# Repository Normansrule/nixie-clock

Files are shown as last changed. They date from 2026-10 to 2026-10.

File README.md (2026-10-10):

# Six-Tube Nixie Clock · Rev C

> [!CAUTION]
> **About 170 V of direct current (DC) inside: hazardous and potentially lethal.** Power only from an external, isolated 12 V adapter (no mains inside). Dark tubes, software "off" or a pulled shunt do **not** mean safe: **measure test pad TP4 below 10 V** before touching. Read **[SAFETY.md](docs/SAFETY.md)** first.

**An open-source, handmade-style desk clock with six real IN-14 Nixie tubes in a walnut case with brass trim, fully enclosed behind a smoked window, that you can make yourself.** It comes with 3D-printable parts, laser-cut and woodworking drawings, a bill of materials (BOM), pin-by-pin wiring, KiCad files, firmware, requirements, labels and a staged build guide, plus a website and a desktop app. **The one missing piece is a routed circuit board**: the path to it is in [MANUFACTURING.md](docs/MANUFACTURING.md).

   

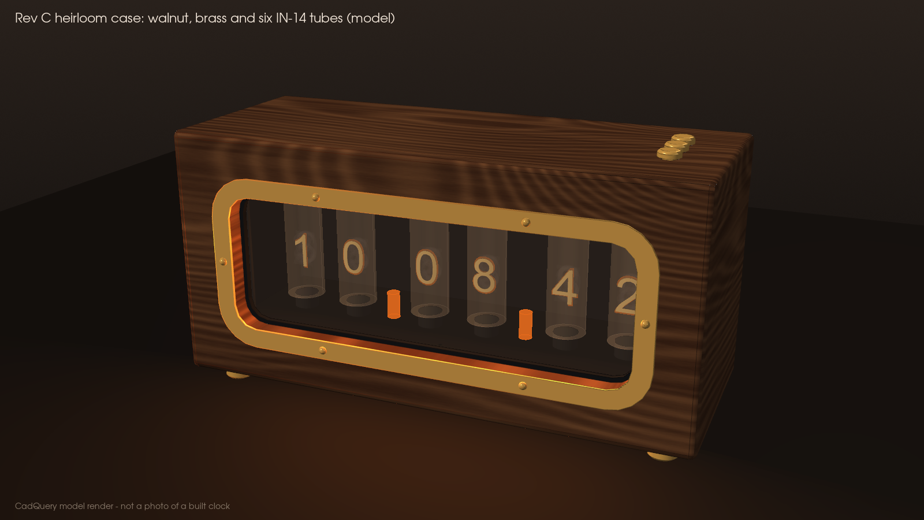
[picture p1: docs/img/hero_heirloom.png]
Walnut and brass heirloom case with six glowing IN-14 tubes, model render


| Front | From the side |
|---|---|
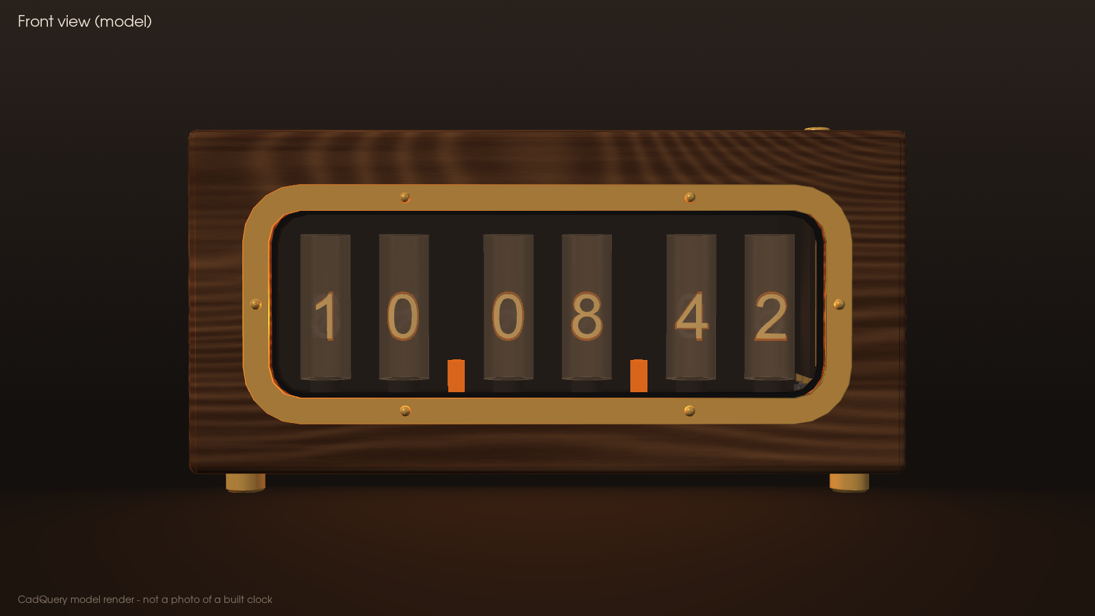
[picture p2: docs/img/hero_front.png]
Front view, model render
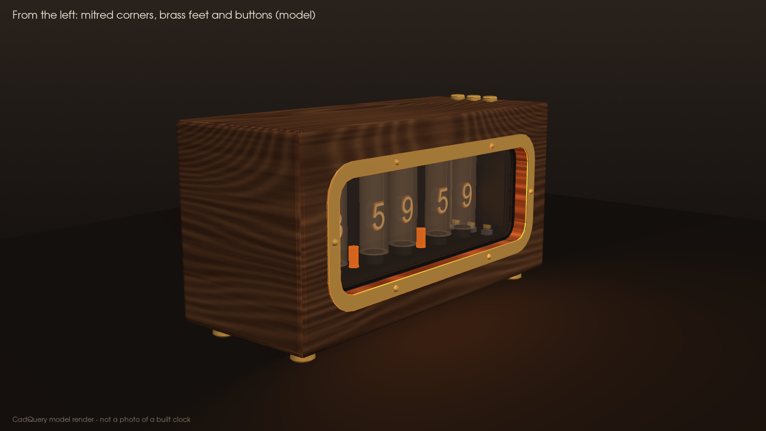
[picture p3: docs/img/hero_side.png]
Left side: mitred corners, brass feet and buttons, model render
|  |  |

> [!IMPORTANT]
> **Rev C is an unvalidated engineering prototype.** Nothing has been powered yet, and the circuit board is not routed, so no Gerber files exist. Recorded file checks pass; every physical check is still open ([VALIDATION.md](docs/VALIDATION.md)).

## At a glance

| | |
|---|---|
| 📏 **Size** | 254 × 100 × 130 mm on its brass feet, about 134 mm to the top of the buttons |
| 🔆 **Display** | 6 × IN-14 tubes (HH MM SS) + 2 × NE-2 neon separators |
| 🔌 **Power** | External isolated 12 V adapter, about 0.25 A with all digits lit |
| 🧠 **Electronics** | Arduino Nano Classic · DS3231 real-time clock (RTC) · 2 × HV5522 tube drivers · NCH8200HV 170 V module |
| 🪵 **Case** | Five mitred 9.5 mm walnut boards, oiled · 1 mm brass bezel with six brass screws · brass feet and button caps · 3 mm smoked cast-acrylic window |
| 🧱 **Inside** | A printed black inner case (fits a Bambu Lab P1S) carries every precise fit and keeps the HV enclosed; on its own it is a complete *printed edition* · **M2 screws only** |
| 💲 **Parts** | About $390 for electronics and printed parts, plus roughly $60–100 for wood and brass (planning estimates, not re-priced) |

## 🏭 Make it

What to make, from which file, and what is ready

Full process, PCB specification and the release gate: **[MANUFACTURING.md](docs/MANUFACTURING.md)**.

## 🧊 See it in 3D

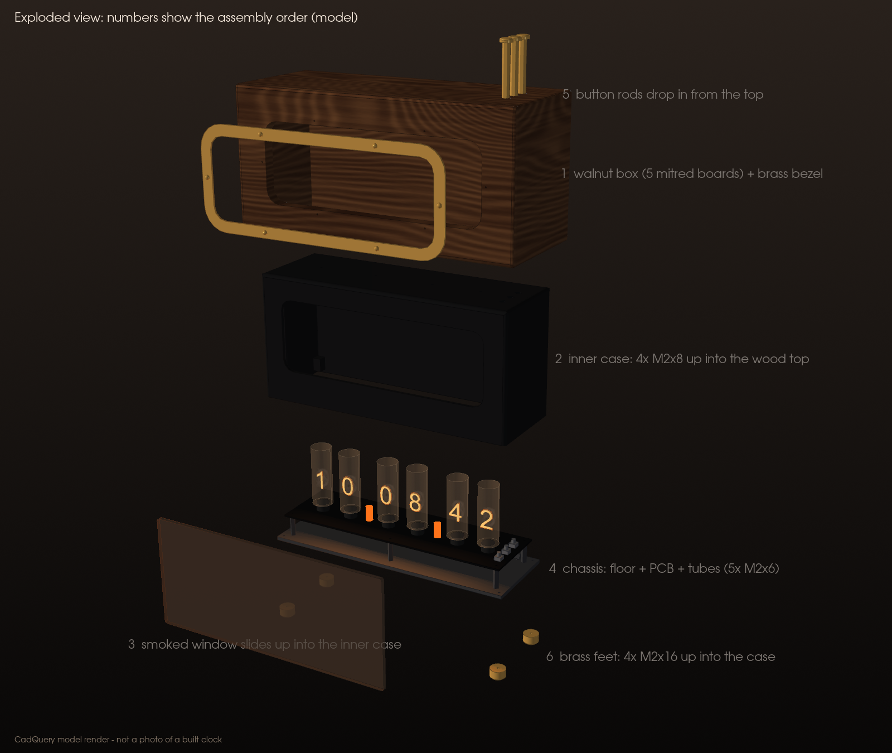
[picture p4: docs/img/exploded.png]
Exploded view


**How it goes together:** glue the five walnut boards into a box and screw the brass bezel on; screw the box onto the printed inner case through its roof; slide the smoked window up into the inner case; screw the PCB with its tubes onto the floor (the *chassis*); lower the case over it and close it with four screws through the brass feet. No glass ever passes through an opening, and nothing high-voltage can be reached once those four screws are in.

GitHub shows `.stl` files in an interactive 3D viewer: click one to rotate it.

| View the whole clock (do not print) | Print these | Cut / make these |
|---|---|---|
| [Finished clock](cad/view/Assembly_RevC_heirloom_VIEW_ONLY.stl) · [Printed edition](cad/view/Inner_case_printed_edition_VIEW_ONLY.stl) · [Chassis, case off](cad/view/Chassis_RevC_case_removed_VIEW_ONLY.stl) | Black PETG: [01 inner case](cad/stl/01_inner_case.stl) · [02 floor](cad/stl/02_floor.stl) · [03 clamp](cad/stl/03_cable_clamp.stl) · [06 fit coupon](cad/stl/06_fit_coupon.stl) · [07 lead coupon](cad/stl/07_unpowered_lead_pattern_coupon.stl) · silk brass: [04 button rod ×3](cad/stl/04_button_rod.stl) · ready plates in [`cad/print/`](cad/print/) | [Wood boards DXF](cad/dxf/Wood_boards_1to1.dxf) (walnut, [WOODWORK.md](docs/WOODWORK.md)) · [Brass bezel DXF](cad/dxf/Brass_bezel_1mm_1to1.dxf) · [Window DXF](cad/dxf/Window_panel_3mm_1to1.dxf) (3 mm smoked cast acrylic) · [brass foot](cad/step/14_brass_foot.step) ×4 |

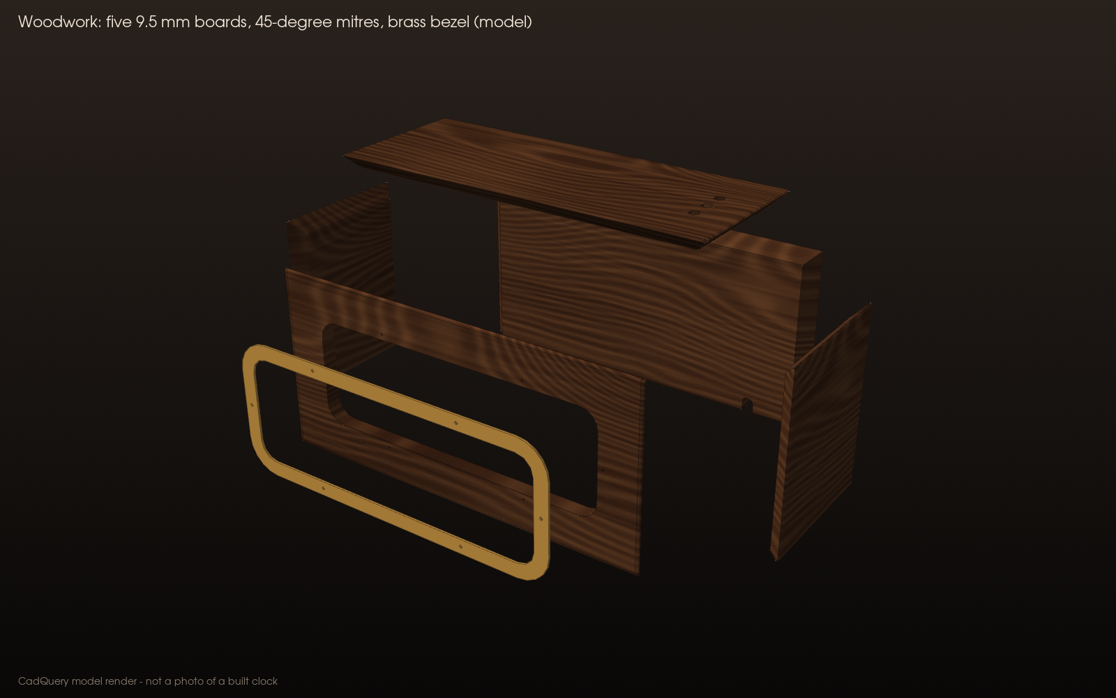
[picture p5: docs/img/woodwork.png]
Woodwork: five mitred walnut boards and the brass bezel


STEP files for computer-aided design (CAD) are in [`cad/step/`](cad/step/); the model of record is [`source/build_cad.py`](source/build_cad.py), driven by [`cad/DIMENSIONS.json`](cad/DIMENSIONS.json). Printing: [PRINTING.md](docs/PRINTING.md) · woodwork and brass: [WOODWORK.md](docs/WOODWORK.md).

Case dimensions

## 🧾 Bill of materials

29 electrical lines (71 parts) plus the case (printed, wood, brass, acrylic) and M2 fasteners. **Lines marked safety-critical must be bought at the stated rating or better.**

| Key part | Qty | Why it matters |
|---|---|---|
| IN-14 Nixie tube | 6 | The display; enclosure is sized for it |
| HV5522PJ-G driver (PLCC-44) | 2 | Switches the tube cathodes (not the PG package) |
| NCH8200HV module | 1 | Makes about 170 V from 12 V |
| Arduino Nano Classic + DS3231SN# | 1 + 1 | Brains and timekeeping |
| 22 kΩ 1 W resistors (Vishay PR01) | 6 | Tube current limit: **safety item** |
| 100 nF ≥250 V capacitor, 110 kΩ bleeders | 1 + 2 | HV rail storage and discharge: **safety items** |

Everything, with specs and allowed substitutions: [`hardware/BOM.csv`](hardware/BOM.csv) · [`hardware/BOM_mechanical.csv`](hardware/BOM_mechanical.csv) · readable [BOM.md](docs/BOM.md).

## 🔌 Circuit and wiring

Wiring overview and driver shift chain

- **Pin by pin:** [WIRING.md](docs/WIRING.md) and [`hardware/NET_MAP.csv`](hardware/NET_MAP.csv) (340 connections; HV5522 pins from the data sheet)
- **Schematic:** [PDF](docs/Nixie_RevC_schematic.pdf) · KiCad project in [`hardware/`](hardware/)
- **PCB:** [mechanical drawing](docs/img/pcb_drawing.svg) · placement-only board (checked by KiCad's own design rules check, no copper yet)
- **Numbers behind the design:** [EQUATIONS.md](docs/EQUATIONS.md) (tube current, resistor power, discharge time, RTC drift)

## 🛠️ Build it

Build stages

Step by step, with parts, measurements and PASS / FIX / STOP at every stage: **[BUILD_GUIDE.md](docs/BUILD_GUIDE.md)**. Record each unit in [`hardware/TEST_RECORD.csv`](hardware/TEST_RECORD.csv) and stick on the [labels](docs/labels.pdf).

## ✅ Requirements

Requirement status

42 requirements, each traced to the part of the design that meets it and to how it is verified: [REQUIREMENTS.md](docs/REQUIREMENTS.md).

## 💻 Website, app and tools

| Website | Desktop app | Tools |
|---|---|---|
| This repository as a website on GitHub Pages; installs as an offline web app | Windows, macOS and Linux from the *Releases* page | Tube and HV calculator, and a USB serial companion for the clock ([APP.md](docs/APP.md)) |

## 🚀 Publish and keep building

- Put this repository on GitHub (website and desktop release included) with one paste: [PUBLISH.md](docs/PUBLISH.md)
- Everyday commands (check, commit, release, apply a new ZIP): [DEVELOP.md](docs/DEVELOP.md)
- Supply chain, signed releases, reporting problems: [SECURITY.md](docs/SECURITY.md) · data sheets: [CREDITS.md](CREDITS.md)

<details>
<summary><b>Repository layout</b></summary>

```
README.md            this page
docs/                SAFETY · BUILD_GUIDE · MANUFACTURING · BOM · WIRING · REQUIREMENTS · EQUATIONS
                     PRINTING · WOODWORK · VALIDATION · APP · PUBLISH · DEVELOP · SECURITY · labels.pdf · schematic PDF
hardware/            KiCad project · NET_MAP.csv · BOM.csv · BOM_mechanical.csv · REQUIREMENTS.csv
                     COMPONENT_PLACEMENT.csv · TEST_RECORD.csv · REVIEW_SIGNOFF.md · native-check reports
firmware/Nixie_RevC/ Nixie_RevC.ino · display_core.h · build/Nixie_RevC.hex
cad/                 DIMENSIONS.json · stl/ · 3mf/ · print/ · step/ · view/ · dxf/ (window, brass bezel, wood boards) · assembly STEP
source/build_cad.py  CadQuery model of record
scripts/             generators, checks, publish/ship/release helpers, gated fab-output script
tests/               equation, design, requirement, CAD and firmware checks
site/ · app/         GitHub Pages website · Electron desktop app
sbom/                toolchain software bill of materials
```
</details>

**Checks:** `scripts/run_all_checks.sh` reruns every recorded check (equations, design tables, requirements, firmware, AVR compile, CAD geometry, KiCad netlist and placement checks). Passing means the files agree with each other, not that a powered clock works.

**License:** MIT ([LICENSE](LICENSE)). Building and powering high-voltage hardware is at your own risk.

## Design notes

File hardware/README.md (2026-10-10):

# Hardware (KiCad, Rev C)

**Status: UNVALIDATED.** Generated files for schematic review and layout. No copper, no routing, no Gerbers.

| File | What it is | How it was made |
|---|---|---|
| `NET_MAP.csv` | Every connection: net, ref, pin, pin name, domain (LV / LOGIC12 / HV), status, note | `scripts/make_design_tables.py` |
| `COMPONENT_PLACEMENT.csv` | Planning positions in **enclosure** coordinates (mm), side, rotation | same |
| `Nixie_RevC.kicad_pro` | Project, with an `HV` net class and patterns that put `HV170`, `ANODE*`, `T?_K?`, `LAMP?_A`, `SEP?_K`, `HV_BLEED_MID`, `HV_SENSE_MID` in it | `scripts/make_kicad.py` |
| `Nixie_RevC.kicad_sch` + `digit_1.kicad_sch` + `digit_2.kicad_sch` | Root sheet (power, logic, level shifters, HV supply, RTC) and one child sheet per driver bank | generated from `NET_MAP.csv`; every connection is a **global label** at a pin |
| `Nixie_RevC.kicad_sym` | Local symbol library: generic box symbols, one per part type | generated |
| `Nixie_RevC.pretty/` | **PLACEHOLDER** footprints: courtyard and fab outline only, **no pads** (plus a real M2 NPTH mounting hole) | generated |
| `sym-lib-table`, `fp-lib-table` | Project-local library tables | generated |
| `Nixie_RevC.kicad_dru` | Starting HV clearance rules for the future routed board | written by hand in the generator; **check against IPC-2221B** |
| `Nixie_RevC_placement.kicad_pcb` | 218 × 64 mm 4-layer outline, five M2 holes, placeholder courtyards (top: tubes, lamps, switches; bottom: everything else, plus keep-outs under the tube and lamp leads) | pcbnew Python API |
| `reports/` | Native netlist export, netlist-vs-net-map comparison, native DRC report of the placement board | `scripts/make_kicad.py` |

**Coordinates.** The placement board uses KiCad's Y-down axis with the clock's front edge at the bottom of the screen. Enclosure point (x, y) sits at board (20 + x, 20 + 80 − y) mm.

## What the native checks do and do not show

- `kicad-cli sch export netlist` reads the generated schematic, and every one of the 106 shared nets matches `NET_MAP.csv`. So the schematic **files** faithfully encode the net map. This is not ERC, and it cannot tell you whether the net map is *right*.
- pcbnew DRC on the placement board reports 0 violations: the outline, holes and courtyards do not collide. There is no copper, so it says nothing about clearances or connectivity.

## To turn this into a board

1. Open `Nixie_RevC.kicad_pro` in KiCad 7 or newer. Redraw the root sheet into readable blocks (the generated one is a label-connected parts list).
2. Replace placeholders with real footprints: PLCC-44 for the HV5522PJ-G, SOIC-16W for the DS3231SN, the IN-14 direct-solder pattern **measured from your tubes**, the NCH8200HV **measured from your module**.
3. Run native ERC. Fix everything or document every waiver.
4. Route 4 layers with `Nixie_RevC.kicad_dru`. Keep HV on one side of the board, away from the Nano and the logic. Keep the top side to tubes, lamps, switches, the HV_ARM header and the TP1–TP4 test pads along the rear edge (reached with the case lifted off).
5. Run native DRC. Have the HV layout reviewed by someone experienced.
6. Only then plot Gerbers and drill files. Record all of it in `docs/VALIDATION.md`.

Regenerate everything here with `python3 scripts/make_design_tables.py && python3 scripts/make_kicad.py` (needs KiCad 7.x with `kicad-cli` and the `pcbnew` Python module).

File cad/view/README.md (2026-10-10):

# View-only assemblies

Open these `.stl` files on GitHub to rotate the whole clock in 3D. **Do not print them**: they contain the glass, PCB, switch, window, wood and brass parts in assembly coordinates. The heirloom view is the finished clock; the printed-edition view is the inner case on its own; the chassis view shows the inside with the case lifted off. Printable parts are in `../stl/` and `../print/`.

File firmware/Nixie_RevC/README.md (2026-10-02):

# Firmware: Nixie_RevC

For the **Arduino Nano Classic (A000005, ATmega328P, 16 MHz)** only. Not for the Nano Every, Nano ESP32 or other boards. Uses only `Wire` and `EEPROM`, which ship with the Arduino AVR core. Serial at 115200 baud.

**Status: UNVALIDATED.** Compiled and linked for the ATmega328P with avr-gcc outside the Arduino IDE; never run on a Rev C board. Read [docs/SAFETY.md](../../docs/SAFETY.md) before connecting USB to a board that has ever had HV on it.

## Files

- `Nixie_RevC.ino`: pins, safe start-up, HV state machine, RTC, buttons, serial commands.
- `display_core.h`: pure logic (bit mapping, one-digit-per-tube check, time formatting, sense conversions). Tested on a PC by `tests/test_display_core.cpp`.

## Features

HH:MM:SS; 12/24-hour; time setting by buttons or serial; real-time clock (RTC) with coin-cell backup; startup blanking; display sleep window; hourly digit exercise against cathode poisoning; VIN and HV diagnostics; default-off on invalid time, reset and faults.

## Safe defaults

- The first lines of `setup()` drive HV_EN and RUN low and shift an all-off frame.
- HV starts only when the time is valid (or while you set it with the buttons, which times out after 60 s), VIN reads 10.8–13.2 V (13.2 V is the HV5522's VDD maximum), and the rail reaches 150 V within 1.5 s. Above 190 V at any time, below 150 V while running, or an unsafe frame latches `HV FAULT` **in EEPROM**: it survives every reset, including the one the serial monitor causes, until you send `CLEARFAULT`.
- Every frame passes `frameIsSafe()` (at most one cathode per tube, never HVOUT32) or an all-off frame is sent instead.
- A 2 s watchdog resets the Nano if the loop hangs; in reset the hardware blanks the tubes and turns HV off.

## Buttons

| Action | Result |
|---|---|
| Hold SET 2 s (or press SET while the time is invalid) | Set hours: H up, M down; SET → set minutes; SET → save (seconds = 00). 60 s without a press abandons setting. HV runs while setting so you can see the digits |
| Hold H 2 s | Toggle 12 / 24-hour (saved) |
| Hold M 2 s | Toggle display sleep (saved) |
| Any press during sleep | Wake for 30 s |

## Serial commands (115200, newline)

`STATUS` · `T hh:mm:ss` · `12` · `24` · `SLEEP hh:mm hh:mm` · `SLEEP OFF` · `HVOFF` (HV off and blank until `RUN`) · `RUN` · `EXERCISE` · `CLEARFAULT` (only after measuring TP4 and fixing the cause)

## Build-time constants to confirm on real hardware

- `nixie::kOutReversed` in `display_core.h` (false = HVOUT*n* is frame bit *n* − 1, matching the data sheet's shift direction). Confirm in Stage 4 by lighting one digit at a time.
- HV window `HV_MIN_DV` / `HV_MAX_DV` and VIN window in `Nixie_RevC.ino`.
- The anode resistor start value (22 kΩ) is not a verified brightness: measure every digit before changing it.

## Build it

Arduino IDE: *Tools → Board → Arduino AVR Boards → Arduino Nano*, *Processor → ATmega328P* (or *Old Bootloader*), then Upload. Record the IDE and core versions in `docs/VALIDATION.md` and pin them in `docs/SECURITY.md` once Stage 2 passes.

Without the IDE (compile check only): `scripts/avr_compile_check.sh /path/to/ArduinoCore-avr`.

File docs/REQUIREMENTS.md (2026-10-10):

# Requirements (Rev C)

42 requirements, each traced to the design element that satisfies it and to how it is verified. Generated by `scripts/make_requirements.py` (also as [`hardware/REQUIREMENTS.csv`](../hardware/REQUIREMENTS.csv)); `tests/check_requirements.py` checks that every requirement has evidence that exists.

**Methods:** I = Inspection, A = Analysis, D = Demonstration, T = Test. **Status:** *recorded* means a script checks the design files, which is **not** a physical result; *open* needs real parts or a measurement at the listed build stage ([BUILD_GUIDE.md](BUILD_GUIDE.md)).

25 of 42 requirements have a recorded design check; 17 still need a physical result

## Safety

| ID | Requirement | Satisfied by | Method | Evidence | Stage | Status |
|---|---|---|---|---|---|---|
| SAF-01 | The clock takes power only from an external, isolated, regulated 12 V adapter. No mains wiring inside the enclosure. | J1 pigtail, adapter line in BOM_mechanical.csv | I | `BOM_mechanical.csv` | 1, 6 | recorded |
| SAF-02 | No high-voltage (HV) copper, lead or module is reachable through any enclosure opening in normal use. | Fully enclosed case: glazed window, rods filling the button holes (<=0.3 mm gap), cable filling the rear hole, screwed floor | I | `tests/check_cad.py (model only)` | 6 | **open** |
| SAF-03 | After power is removed the HV rail falls below 10 V within 60 s, confirmed by measurement every time before access. | RH1+RH2 bleeder (220 kOhm), sense divider, SAFETY.md rule 3 | A, T | `tests/check_equations.py (discharge)` | 3 | **open** |
| SAF-04 | Removing the HV_ARM shunt physically opens the converter's 12 V input. | JP1 in series with QP2 and PS1 input | I, T | `tests/check_design.py` | 2 | recorded |
| SAF-05 | The HV converter stays off whenever the Nano is in reset or unprogrammed. | RGP gate pull-up on QP2, RPD5 base pull-down on QE1 | I, T | `tests/check_design.py` | 2 | recorded |
| SAF-06 | All tube outputs are blanked at start-up and whenever the Nano is in reset. | RD1 pull-down on BL, POL tied HIGH, two-stage RUN shifter | I, T | `tests/check_design.py` | 2 | recorded |
| SAF-07 | No Nano output connects directly to an HV5522 input. | QL1-QL5 level shifters | I | `tests/check_design.py` | - | recorded |
| SAF-08 | At most one cathode per tube is ever latched on, and unused driver outputs are never set. | frameIsSafe() in display_core.h; unsafe frame latches a fault | A, T | `tests/test_display_core.cpp` | 4 | recorded |
| SAF-09 | Each tube anode is current-limited by a 22 kOhm 1 W resistor and each lamp by 220 kOhm 1 W. | RA1-RA6, RL1, RL2 (PR01) | I, A | `tests/check_design.py, tests/check_equations.py` | 4 | recorded |
| SAF-10 | HV is sensed; outside 150-190 V the firmware turns HV off and latches a fault that survives resets until a deliberate CLEARFAULT. | RS1-RS3 to A0; hvService(), EEPROM fault latch | A, T | `scripts/avr_compile_check.sh` | 2, 3 | **open** |
| SAF-11 | The 12 V input is fused and protected against reverse polarity. | F1 PTC, QP1 P-MOSFET | I, T | `tests/check_design.py` | 1 | recorded |
| SAF-12 | Every exposed neon lamp lead is sleeved with insulation rated at least 300 V (600 V preferred). | Sleeving line in BOM_mechanical.csv | I | `BOM_mechanical.csv` | 4 | **open** |
| SAF-13 | HV-side parts meet minimum ratings: CHV >=250 V; bleeder and sense resistors >=200 V; anode and lamp resistors 1 W. | BOM.csv safety_critical lines | I | `tests/check_requirements.py (BOM specs)` | 1 | recorded |
| SAF-14 | A hung firmware loop resets the Nano within 2 s. | wdt_enable(WDTO_2S) | A | `scripts/avr_compile_check.sh` | 2 | recorded |

## Honesty

| ID | Requirement | Satisfied by | Method | Evidence | Stage | Status |
|---|---|---|---|---|---|---|
| HON-01 | No Gerber or drill files are produced until a routed board passes native ERC and DRC and an experienced HV review is signed off. | scripts/make_fab_outputs.sh gate, hardware/REVIEW_SIGNOFF.md | D | `scripts/make_fab_outputs.sh (refuses today)` | - | recorded |
| HON-02 | Validation records keep recorded file checks separate from physical checks, and claim only what was done. | docs/VALIDATION.md | I | `docs/VALIDATION.md` | 7 | recorded |

## Function

| ID | Requirement | Satisfied by | Method | Evidence | Stage | Status |
|---|---|---|---|---|---|---|
| FUN-01 | Six upright IN-14 tubes show HH MM SS, with an NE-2 separator between each pair. | NET_MAP.csv driver map; timeToDigits() | T | `tests/test_display_core.cpp` | 4 | **open** |
| FUN-02 | 12- or 24-hour display is selectable and remembered across power cycles. | cfg.twelveHour in EEPROM | D | `tests/test_display_core.cpp` | 2, 4 | **open** |
| FUN-03 | Time can be set with the SET, H and M buttons and over USB serial. | handleButtons(), T command | D | `scripts/avr_compile_check.sh` | 2 | **open** |
| FUN-04 | The DS3231 keeps time on a CR2032 primary cell while unpowered (about +/-2 ppm, 0-40 C). | U3, J2, VBAT | A, T | `tests/check_equations.py (drift)` | 2 | **open** |
| FUN-05 | An optional sleep window blanks the display; any button wakes it for 30 s. | inWindow(), wantDisplay() | D | `tests/test_display_core.cpp` | 2 | **open** |
| FUN-06 | Once an hour every cathode of every tube is lit briefly (anti-poisoning). | exerciseDigits() | A, D | `tests/test_display_core.cpp` | 4 | recorded |
| FUN-07 | The display stays off while the time is invalid (except while the user is setting it, 60 s timeout). | wantDisplay(), SET_TIMEOUT_MS | D | `scripts/avr_compile_check.sh` | 2 | **open** |
| FUN-08 | STATUS over serial reports time, VIN, HV, state, faults and button states. | printStatus() | D | `scripts/avr_compile_check.sh` | 2 | **open** |

## Electrical

| ID | Requirement | Satisfied by | Method | Evidence | Stage | Status |
|---|---|---|---|---|---|---|
| ELE-01 | With all digits lit the 12 V input current stays near 0.25 A (stop above 0.35 A); adapter rated >=1 A. | EQUATIONS.md section 5 | A, T | `tests/check_equations.py` | 4 | **open** |
| ELE-02 | HV load with all six tubes and both lamps lit stays within the converter rating (model: about 35 % of 30 mA). | PS1 NCH8200HV | A, T | `tests/check_equations.py` | 4 | **open** |
| ELE-03 | HV5522 logic supply stays within 10.8-13.2 V; firmware refuses HV outside that VIN window. | VIN sense RV1/RV2, VIN_MIN_DV/VIN_MAX_DV | A, T | `tests/check_equations.py` | 2 | **open** |

## Mechanical

| ID | Requirement | Satisfied by | Method | Evidence | Stage | Status |
|---|---|---|---|---|---|---|
| MEC-01 | Heirloom case: printed inner case 234 x 80 x 112 mm clad in a mitred hardwood box 254 x 100 x 121.5 mm (129.5 mm on its feet), outer edges rounded R3. | cad/DIMENSIONS.json, source/build_cad.py | I | `tests/check_cad.py` | 6 | recorded |
| MEC-09 | Premium finish: hardwood (walnut by default) with an oil finish, a 1 mm brass bezel with six brass screws around the window, brass feet and brass button caps. | wood_box(), brass_bezel(), brass_foot(), BOM_mechanical.csv wood and brass lines | I, D | `tests/check_cad.py` | 6 | recorded |
| MEC-10 | Wood never carries a functional fit and never touches the electronics: every precise feature is in the printed inner case, and the wood is held only by four screws into its top board. | wood_fit_gap, roof_screws, inner case | I, A | `tests/check_cad.py` | 6 | recorded |
| MEC-02 | Only M2 fasteners: 4x M2x16 (feet and floor to inner case), 4x M2x8 (inner case to wood top), 7x M2x6 (PCB, cable clamp), 6x M2x6 brass (bezel). | DIMENSIONS.json fasteners, BOM_mechanical.csv | I, A | `tests/check_design.py` | 0, 6 | recorded |
| MEC-03 | The tubes are fully enclosed: no glass passes through any opening; the case is lowered over the finished chassis. | case_shell(), floor standoffs, light baffle | I, D | `tests/check_cad.py` | 6 | recorded |
| MEC-04 | All six numerals are seen through one front window glazed with a 3 mm smoked cast-acrylic panel, framed by the brass bezel and held by the floor and three silicone dots so it stays put when the case is lifted. | window_panel(), slot rails, Window DXF | I | `tests/check_cad.py` | 6 | recorded |
| MEC-05 | Every printed part fits a 256 x 256 x 256 mm build volume (Bambu Lab P1S); only the inner-case roof needs supports. The wood and brass parts are not printed. | cad/BUILD_REPORT.txt bounding boxes | A, D | `tests/check_requirements.py (bed fit)` | 0, 6 | recorded |
| MEC-08 | With the case lifted off, TP1, TP4 and the HV_ARM shunt are reachable from the top of the chassis without reaching under the board. | JP1, TP1-TP4 on the PCB top side (COMPONENT_PLACEMENT.csv) | I | `tests/check_design.py` | 3 | recorded |
| MEC-07 | SET, H and M are pressed from the top of the case through brass-coloured rods that rest on the switches by their own weight and are hidden from the window by a baffle. | button_rod(), guides in case_shell() | A, D | `tests/check_cad.py` | 0, 6 | **open** |

## Electrical

| ID | Requirement | Satisfied by | Method | Evidence | Stage | Status |
|---|---|---|---|---|---|---|
| ELE-04 | The sealed, wood-clad case stays cool enough: modelled average internal rise about 3-5 K at about 2.7 W (wood insulation included); regulator checked at Stage 5. | No vents (keeps HV enclosed) | A, T | `tests/check_equations.py (enclosure rise)` | 5 | **open** |

## Mechanical

| ID | Requirement | Satisfied by | Method | Evidence | Stage | Status |
|---|---|---|---|---|---|---|
| MEC-06 | PCB 218 x 64 x 1.6 mm, 4 layers, five M2 holes at the specified coordinates. | Nixie_RevC_placement.kicad_pcb | I | `scripts/make_kicad.py (native placement DRC)` | - | recorded |

## Cost

| ID | Requirement | Satisfied by | Method | Evidence | Stage | Status |
|---|---|---|---|---|---|---|
| CST-01 | Built as cheaply as is safe: generic passives where allowed, no downgrades of safety items (planning total about $390 plus roughly $60-100 for wood and brass, not re-priced). | BOM.csv substitution column | I | `BOM.csv` | order | **open** |

## Supply chain

| ID | Requirement | Satisfied by | Method | Evidence | Stage | Status |
|---|---|---|---|---|---|---|
| SEC-01 | CI actions pinned by commit hash, least-privilege permissions, SBOM, SHA-256 checksums, Dependabot and CodeQL. | .github/, sbom/, SHA256SUMS | I | `.github/workflows/checks.yml` | - | recorded |

## Documentation

| ID | Requirement | Satisfied by | Method | Evidence | Stage | Status |
|---|---|---|---|---|---|---|
| DOC-01 | Every stage of the build guide lists parts, steps, measurements and PASS / FIX / STOP, with a safety gate before HV. | docs/BUILD_GUIDE.md | I | `docs/BUILD_GUIDE.md` | - | recorded |

## Distribution

| ID | Requirement | Satisfied by | Method | Evidence | Stage | Status |
|---|---|---|---|---|---|---|
| APP-01 | The project is published as a GitHub repository, a GitHub Pages website (installable offline) and a desktop app. | site/, app/, workflows | D | `app launched headless (docs/APP.md)` | - | recorded |

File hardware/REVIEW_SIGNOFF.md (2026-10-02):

# Fabrication review sign-off (Rev C)

`scripts/make_fab_outputs.sh` refuses to make Gerber, drill or placement files until **every** field below is filled in
and the last line says `Approved for fabrication: yes`. Fill it in only after the work is actually done.

| Item | Value |
|---|---|
| Routed board file | `hardware/Nixie_RevC.kicad_pcb` |
| Git commit reviewed | |
| Native ERC (electrical rules check): KiCad version, date, result | |
| Native DRC (design rules check) with `Nixie_RevC.kicad_dru`: KiCad version, date, result | |
| HV clearances checked against IPC-2221B and the fab's capability by | |
| Real footprints checked against parts in hand (IN-14 lead circle, NCH8200HV outline, PLCC-44) by | |
| Experienced HV reviewer (name) | |
| Review date | |
| Notes / waivers | |

Approved for fabrication: no

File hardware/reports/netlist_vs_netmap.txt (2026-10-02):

native netlist: 147 nets from kicad-cli 7.0.11
NET_MAP.csv:    106 multi-use nets (NC nets excluded)
mismatched nets: 0
extra native nets: []
NETLIST vs NET_MAP: MATCH

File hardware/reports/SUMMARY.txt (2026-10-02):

Native KiCad checks run by scripts/make_kicad.py
These are NOT ERC, and NOT DRC of a routed board. See docs/VALIDATION.md.

native netlist: 147 nets from kicad-cli 7.0.11
NET_MAP.csv:    106 multi-use nets (NC nets excluded)
mismatched nets: 0
extra native nets: []
NETLIST vs NET_MAP: MATCH

placement board native DRC (pcbnew 7.0.11): violations=0, unconnected=0, footprint errors=0

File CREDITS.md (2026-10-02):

# Credits and data sheets

Every value taken from a data sheet is marked in [`hardware/NET_MAP.csv`](hardware/NET_MAP.csv) (status `DATASHEET`) or listed as an untested assumption in [`docs/VALIDATION.md`](docs/VALIDATION.md). Links were found or opened on 2026-09-30, except the onsemi, Microchip ATmega328P and Arduino pages, which are the manufacturers' usual product pages and were not re-checked. Manufacturers move files: search the part number on the manufacturer's site if a link breaks.

| Part | Document | Used for | Status |
|---|---|---|---|
| IN-14 Nixie tube | [Tube-Tester IN-14 page](https://www.tube-tester.com/sites/nixie/data/in-14/in-14.htm); [IN-14 data (PDF)](https://download.elektronicastynus.be/57/in-14_datasheet.pdf) | 145 V typical maintaining voltage, 2.5 mA typical current, 19 mm × 55 mm bulb, 13 leads | Lead-circle diameter **not verified** (placeholder) |
| HV5522 (HV5522PJ-G) | [Microchip product page](https://www.microchip.com/en-us/product/hv5522); [data sheet DS20005699](https://ww1.microchip.com/downloads/en/DeviceDoc/20005699A.pdf); [Supertex-era data sheet](https://www.mouser.com/datasheet/2/268/supertex_hv5522-1181179.pdf) | PLCC-44 pinout, function table (POL/BL), shift direction, falling-edge clock, VDD 10.8–13.2 V, VIH ≥ VDD − 2 V, 220 V outputs | Read from the Supertex-era sheet; **recheck against DS20005699** |
| DS3231SN# | [Analog Devices DS3231 product page](https://www.analog.com/en/products/ds3231.html); [data sheet (PDF)](https://www.analog.com/media/en/technical-documentation/data-sheets/ds3231.pdf) | Pinout, ±2 ppm (0–40 °C), OSF and EOSC bits, grounding pins 5–12 | Pin 5–12 grounding **verify** |
| NCH8200HV | [Omnixie product page](https://omnixie.io/nch8200hv.html); [NCH8200HV data sheet v2.1 (PDF)](https://nixieclock.org/wp-content/uploads/2023/02/NCH8200HV-Datasheet-EN-v2.1.0.3.pdf) | 2.5–15 V in, ~170 V fixed out, 30 mA peak, 86–89.65 % efficiency, pin order, no reverse-polarity protection | Outline and output capacitance **not documented** |
| ATmega328P / Arduino Nano | [Microchip ATmega328P](https://www.microchip.com/en-us/product/atmega328p); [Arduino Nano A000005](https://docs.arduino.cc/hardware/nano/) | ADC, watchdog, Nano header pinout | |
| DMP3098L-7 | [Diodes Inc. DMP3098L data sheet DS31447](https://datasheet.octopart.com/DMP3098L-7-Diodes-Inc.-datasheet-12534397.pdf) | −30 V P-MOSFET, SOT-23 | V_GS limit **verify** against adapter overshoot |
| 1812L075/33DR | [Littelfuse 1812L PolySwitch data sheet](https://www.littelfuse.com/assetdocs/resettable-ptcs-1812l-datasheet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) | 0.75 A hold, 33 V PTC | |
| MMBT3904 / MMBT3906 | [onsemi MMBT3904](https://www.onsemi.com/products/discrete-power-modules/general-purpose-and-low-vcesat-transistors/mmbt3904); [onsemi MMBT3906](https://www.onsemi.com/products/discrete-power-modules/general-purpose-and-low-vcesat-transistors/mmbt3906) | Level shifters | |
| Omron B3F-1062-G | [Omron B3F series](https://components.omron.com/us-en/products/switches/B3F) | 6 × 6 mm body, 7 mm height | Body height **verify** (drove the pocket change) |
| Vishay PR01 | [Vishay PR01/PR02/PR03](https://www.vishay.com/en/product/28729/); [data sheet (PDF)](https://www.vishay.com/docs/28729/pr010203.pdf) | 1 W axial anode and lamp resistors | |
| NE-2 neon lamp | Generic; supplier data | ~60 V maintaining voltage assumed | **verify** |

## Standards and references

- OWASP Top 10:2025, A03 Software Supply Chain Failures: [A03:2025](https://owasp.org/Top10/2025/A03_2025-Software_Supply_Chain_Failures/).
- IPC-2221B Table 6-1 (conductor spacing): the source to check the HV clearances in `hardware/Nixie_RevC.kicad_dru` against. Not reproduced here.

## Tools

CadQuery, OpenCASCADE, ezdxf, VTK, KiCad, avr-gcc and ArduinoCore-avr. Versions are in [`sbom/toolchain.spdx.json`](sbom/toolchain.spdx.json).

## Author

Aleksander Norman. Rev C documentation, generators and checks prepared with Claude (Anthropic).

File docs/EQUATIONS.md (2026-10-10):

# Equations

Each section goes intuition → equation → symbols and units → worked example → picture and test. Every number on this page is recomputed by [`tests/check_equations.py`](../tests/check_equations.py) (39 checks). They are **model numbers**, not measurements: Stage 4 of the [build guide](BUILD_GUIDE.md) replaces them with readings from your board.

Inputs used throughout:

| Symbol | Value | Source |
|---|---|---|
| V_HV | 170 V | NCH8200HV v2.1 data sheet: fixed nominal output |
| V_tube | 145 V typical, 135–155 V assumed spread | Tube-Tester IN-14 page (typical maintaining voltage) |
| I_typ | 2.5 mA per digit | Tube-Tester IN-14 page (typical cathode current) |
| R_anode | 22 kΩ, 1 W | Rev C start value (RA1–RA6) |
| R_lamp | 220 kΩ, 1 W | RL1, RL2 |
| V_NE2 | 60 V assumed | NE-2 maintaining voltage; **verify** |

## 1. Tube anode current

**Intuition.** A glowing Nixie tube holds its own voltage roughly constant (the *maintaining voltage*). Whatever is left of the supply is dropped across the anode resistor, and that sets the current.

**Equation.** I_anode ≈ (V_HV − V_tube) / R_anode

**Symbols.** I_anode in amperes (A); V_HV and V_tube in volts (V); R_anode in ohms (Ω).

**Worked example.** (170 V − 145 V) / 22 000 Ω = **1.14 mA**. Across the assumed spread: 1.59 mA at 135 V, 0.68 mA at 155 V.

**What it means.** 1.14 mA is about **45 % of the 2.5 mA typical** IN-14 current. Expect the start value to run the tubes gently; a digit that glows only partly is a sign of too little current. The 22 kΩ value is a *starting point, not a verified brightness*. Measure the current on every digit (Stage 4) before you change anything. For reference, 2.5 mA at 145 V would need about 10 kΩ, and a lower resistor raises the fault power in section 2.

Anode current against tube voltage

**Test.** `anode current @ V_tube=...` and `22 k start value vs IN-14 typical` in `tests/check_equations.py`.

## 2. Resistor power: why the anode resistors are 1 W

**Intuition.** In normal running the resistor only sees the leftover 25 V or so, so it barely warms. In a fault (a tube or cathode path shorted) it can see the whole rail.

**Equation.** P = I² × R in normal running; P = V_HV² / R if the full rail appears across it.

**Symbols.** P in watts (W); I in A; R in Ω; V in V.

**Worked example.**

| Case | Calculation | Result | Share of 1 W rating |
|---|---|---|---|
| Normal, worst tube (135 V) | (1.59 mA)² × 22 kΩ | 55.7 mW | 5.6 % |
| Fault: full rail across RA | 170² / 22 000 | **1.31 W** | **131 %** |
| Lamp resistor, normal | (0.5 mA)² × 220 kΩ | 55 mW | 5.5 % |
| Lamp resistor, fault | 170² / 220 000 | 131 mW | 13 % |

**What it means.** Normal dissipation is tiny. The 1 W rating is there for voltage stress and fault margin, and it is still **not enough** for a sustained hard short, because the NCH8200HV data sheet describes no current limit (up to 30 mA peak output). This is recorded as an open item in [VALIDATION.md](VALIDATION.md#open-items), not hidden. Never reduce the rating.

## 3. Bleeder discharge

**Intuition.** When the converter stops, its output capacitors are still charged. The bleeder resistors drain that charge. The tubes go dark long before the rail is safe, because a tube stops glowing at about 140 V.

**Equation.** V(t) = V_HV × e^(−t/τ), with τ = R × C, so the time to fall to a voltage V is t = τ × ln(V_HV / V).

**Symbols.** τ (tau), the time constant, in seconds (s); R in Ω (the bleeder in parallel with the sense divider); C in farads (F).

**Worked example.** R = 220 kΩ ∥ 2.022 MΩ = 198.4 kΩ.

| Capacitance on the rail | τ | Time to 10 V |
|---|---|---|
| CHV only (100 nF) | 19.8 ms | 56 ms |
| CHV + an **assumed** 1 µF inside the converter | 218 ms | 0.62 s |
| Same, but **the bleeder path open** (RH1 and RH2 are in series, so one open resistor is enough) | 2.2 s | 6.3 s |

**What it means.** On paper the rail empties in under a second. But the converter's internal capacitance is not in its data sheet, and a single open resistor makes it ten times slower. That is why [SAFETY.md](SAFETY.md) asks you to wait 60 seconds **and measure below 10 V** every time.

Discharge curves

**Test.** The `tau ...` and `time to 10 V ...` checks. The firmware also warns if its own sense reading is above 10 V three seconds after HV off; that is a hint, not a proof.

## 4. HV and VIN sensing

**Equation.** V_A0 = V_HV × R_S3 / (R_S1 + R_S2 + R_S3); V_A1 = V_IN × R_V2 / (R_V1 + R_V2)

**Worked example.** 170 V × 22 k / 2.022 M = **1.85 V**, about 378 counts on the Nano's 10-bit analog-to-digital converter (ADC) with a 5 V reference, or 0.45 V of HV per count. 12 V × 10 k / 57 k = 2.1 V on A1. Full scale is 459 V for HV and 28.5 V for VIN. If RS3 ever opens, about 82 µA flows into the A0 protection diodes through 2 MΩ, which the pin tolerates.

**What it means.** The firmware window is 150–190 V. The reference is the Nano's 5 V rail, which can be a few percent off, so compare the firmware's `HV sense` with your meter at Stage 3 and note the difference in VALIDATION.md.

## 5. 12 V input current

**Equation.** I_in ≈ P_HV / (η × 12 V) + I_logic, with P_HV = V_HV × (6 × I_anode + 2 × I_lamp + I_bleed + I_sense)

**Worked example.** Worst-case tubes: P_HV ≈ 1.94 W; at η (efficiency) = 86 % and about 50 mA of logic load, **I_in ≈ 0.24 A**. The HV load (10.6 mA) is about 35 % of the converter's 30 mA peak rating.

**Test.** `12 V input current ...` and `NCH8200HV headroom ...`. A reading well above 0.35 A is a stop condition.

## 6. Real-time clock drift

**Intuition.** The DS3231 is a temperature-compensated crystal clock, so it drifts far less than an ordinary watch crystal, but not zero.

**Equation.** drift per day = accuracy (ppm) × 10⁻⁶ × 86 400 s

**Worked example.** At the data sheet's ±2 parts per million (ppm) from 0 to 40 °C: ±0.17 s per day, ±63 s per year at worst. Real parts are usually better. The DS3231 also has an aging register for trimming, which Rev C firmware leaves at zero.

**Test.** `DS3231 worst drift ...`. To measure your clock, set it against a reference, then compare after a week with `STATUS` over the serial port.

## 7. Sealed-case temperature

**Intuition.** The case has no vents (so the HV stays enclosed). All the power the clock uses ends up as heat inside and has to leave through the case surface. The walnut box looks good but is an insulator, so it is part of the path the heat must cross.

**Equation.** ΔT ≈ P / (U × A), with U = 1 / (1/h + t_wood / k_wood)

**Symbols.** ΔT, the average rise of the inside air over the room, in kelvin (K); P, heat released inside, in W; A, the outer surface area, in m²; h, the combined natural-convection and radiation coefficient of the outer surface, in W/(m²·K); t_wood, the board thickness, in m; k_wood, the wood's thermal conductivity across the grain, in W/(m·K); U, the overall coefficient, in W/(m²·K).

**Worked example.** P ≈ 1.94 W / 0.86 (converter) + 7 V × 50 mA (the Nano's regulator) + 0.1 W (logic) ≈ **2.7 W**. A ≈ 2 × (0.254 × 0.100 + 0.254 × 0.1215 + 0.100 × 0.1215) ≈ 0.137 m². Walnut: t_wood / k_wood ≈ 0.0095 / 0.15 ≈ 0.063 m²·K/W (k assumed). With h = 5 (pessimistic), U ≈ 3.8 and ΔT ≈ **5.2 K**; with h = 10 (typical), U ≈ 6.1 and ΔT ≈ 3.2 K. The wood resistance is applied to every face, which is pessimistic for the PETG floor and the acrylic window; the printed inner wall and the inside air film are ignored.

**What it means.** On average the inside barely warms, even with the wood on. Hot spots are another matter: the Nano's linear regulator and the HV module run hotter than the air around them. Stage 5 of the build guide measures them after two hours closed, with the wood box fitted.

**Test.** `heat dissipated inside the case`, `wood wall resistance`, `average internal rise ...`.

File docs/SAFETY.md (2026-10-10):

# High-voltage safety

> **About 170 volts of direct current (V DC) lives on this board whenever the high-voltage converter has run. Treat it as hazardous and potentially lethal.** Rev C is an unvalidated engineering prototype. Nobody has yet powered one and recorded the results.

This page is the rulebook. The [build guide](BUILD_GUIDE.md) points back here at every high-voltage (HV) step, and none of its gates may be skipped.

## The five rules

1. **No mains inside the clock.** Power comes only from an external, *isolated*, regulated 12 V adapter with a centre-positive 5.5 × 2.1 mm plug. The clock never touches line voltage. Do not substitute a non-isolated supply, a bench supply without current limit during bring-up, or a battery pack of unknown voltage.
2. **Off is not safe until you have measured it.** Firmware "HV off", dark tubes, unplugging the adapter and pulling the HV_ARM shunt all stop the converter. **None of them proves the HV rail (net `HV170`, test pad TP4) is discharged.** Only a meter reading does.
3. **Measure before every touch.** Before your hands, tools or probes go near the board: unplug 12 V, wait at least 60 seconds, then measure TP4 to TP1 (ground). Continue only below **10 V**. If the reading is not falling as the bleeder predicts, **STOP**: a bleeder resistor may be open, and the capacitors can hold charge for a long time.
4. **Enclosed in use; guarded during bring-up.** In normal use the clock only runs fully closed: case screwed to the floor through the brass feet, window in place, rods in their holes, so no HV copper, lead or the converter can be reached. The printed inner case is the HV enclosure; the walnut box is only cladding, so the clock never runs in the wood box without the inner case, and all woodwork and brass work (conductive swarf) is finished and vacuumed before electronics go in. The only exception is guarded bench bring-up (Stages 3 and 4 of the build guide), where the board must be measured: then the chassis (floor + PCB) sits on an insulated surface behind a clear barrier, on a current-limited supply, with meter leads and USB connected **before** power is applied, hands off while energised, never unattended.
5. **Experienced review first.** Before the HV_ARM shunt goes in for the first time, someone experienced with high-voltage DC circuits reviews the populated board, the enclosure and your measuring setup.

## What protects you in the design, and what does not

| Protection | What it does | What it does **not** do |
|---|---|---|
| Isolated external 12 V adapter | Keeps mains out of the enclosure | Does nothing about the 170 V made inside |
| F1 resettable fuse (Positive Temperature Coefficient, PTC) | Limits a 12 V side fault | Does not limit HV current |
| QP1 reverse-polarity P-channel MOSFET (Metal-Oxide-Semiconductor Field-Effect Transistor) | Blocks a reversed plug | The converter itself has **no** reverse-polarity protection (its data sheet says so) |
| JP1 HV_ARM shunt | Physically opens the converter's 12 V input | Does not discharge anything already charged |
| QP2 high-side switch, gate pulled off | Converter stays off while the Nano is in reset or unprogrammed | A failed transistor can leave it on |
| Base pull-downs + BL pull-down + POL tied high | Tubes blanked while the Nano is in reset | Depends on the HV5522 behaving as its data sheet says: **verify** |
| 22 kΩ 1 W anode resistors, 220 kΩ 1 W lamp resistors | Set and limit current into each tube and lamp | The NCH8200HV module has no documented current limit, so a hard short can overload a 1 W resistor (see [VALIDATION.md](VALIDATION.md#open-items)) |
| RH1 + RH2 bleeder (220 kΩ total) | Discharges the HV rail in well under a second on paper | Fails silently if a resistor opens: that is why rule 3 exists |
| HV sense divider to A0 | Firmware shuts down outside 150–190 V | A reading is not a guarantee: the sensing chain can fail |
| Firmware fault latch (EEPROM) | Any HV fault keeps HV off across resets until `CLEARFAULT` | A deliberate clear by the user re-enables it |
| Firmware watchdog | A hung Nano resets, which blanks the tubes and turns HV off | Not a safety device on its own |
| Sleeving ≥300 V (600 V preferred) on neon leads | Insulates exposed lamp leads | Only if every lead is covered |

These parts are **safety items and must never be "value-engineered" away**: the 1 W anode and lamp resistors, the ≥250 V HV capacitor (CHV), the bleeders, the sleeving, the isolated adapter and the fused, reverse-protected 12 V path.

## Measuring the HV rail safely

- Use a meter rated at least Category II 600 V with intact leads. Clip the black lead to TP1 **before** power is ever applied, and use a single-hand technique: one hand behind your back or in your pocket.
- Probe TP4 only with the probe tip; never bridge TP4 to anything with a tool.
- Expected with the converter running: about 170 V (the NCH8200HV output is fixed, not adjustable, per its v2.1 data sheet).
- Expected after unplugging, with good bleeders: below 10 V within about 1 second on paper (see [EQUATIONS.md](EQUATIONS.md#3-bleeder-discharge)). Rule 3 still asks you to wait 60 seconds and measure, because the converter's internal capacitance is unknown.
- If you ever need to force a discharge, use a purpose-made discharge tool: a resistor of at least 10 kΩ, rated 5 W or more, on insulated leads. Never short the rail with a screwdriver.

## USB, the shunt and the serial monitor

The Nano sits under the PCB, inside the closed case; its USB port is reached from the side of the chassis once the case is lifted off. Two situations:

- **Guarded bring-up (Stages 3–4):** USB may stay connected with the shunt fitted, but connect it before applying 12 V and never plug or unplug it while 12 V is on. Opening the serial monitor resets the Nano; the firmware keeps any HV fault latched in EEPROM across that reset, so HV cannot quietly restart after a fault. A USB isolator between the computer and the clock is a sensible extra.
- **Flashing firmware:** follow the steps below every time.

### Flashing

1. Unplug the 12 V adapter. Remove the HV_ARM shunt only after the discharge check below.
2. Wait 60 seconds. Lay the clock on its back, remove the 4 screws through the brass feet, stand it up and lift the case (wood and inner case together) straight off. **Measure TP4 to TP1 below 10 V** (both on the top side at the rear edge), then remove the HV_ARM shunt next to them.
3. Connect USB only after that. With the shunt out, USB power cannot reach the converter. This matters because the NCH8200HV starts from as little as 2.5 V input, and USB can back-feed a few volts into the 12 V rail through the Nano's regulator.
4. Refit the shunt only when you are about to close the case for a powered test.

## Stop conditions (any of these ends the session until fixed)

- TP4 does not fall below 10 V within 60 seconds of unplugging.
- The firmware reports `HV FAULT`, `HV still ... after off`, or `unsafe frame rejected`. A fault stays latched in EEPROM until you send `CLEARFAULT`; only do that after you have measured TP4 and found the cause.
- Any smell, discoloration, crackling, visible arcing or a resistor warmer than you can comfortably hold.
- A tube shows more than one digit, or a lamp stays lit when the display should be blank.
- The 12 V adapter current rises above about 0.35 A with all digits lit (the model predicts roughly 0.25 A; see [EQUATIONS.md](EQUATIONS.md#5-12-v-input-current)).

## Who should not build this

If you are not comfortable working near high-voltage direct current, have never used a multimeter on a live circuit, or have no experienced person to review your board, do not build Rev C yet. Wait for a validated revision.

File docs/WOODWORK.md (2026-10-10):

# Woodwork and brass

The heirloom look comes from five hardwood boards mitred into a box, a brass bezel around the window, brass feet and brass button caps. None of this is electrical, and none of it carries a precise fit: the printed inner case does that, so the woodwork can be forgiving. Everything here is a **baseline, untested** plan, like the rest of Rev C.

Woodwork: five mitred boards and the brass bezel, model render

> [!WARNING]
> **Do all woodwork and brass work before any electronics go near the case.** Brass swarf and filings are conductive: one chip near a 170 V trace is a short. Vacuum the inner case and the wood box before assembly. Walnut dust irritates skin and airways: wear a dust mask and extract dust.

## What you make

| Part | Outer size (mm) | Joints | From |
|---|---|---|---|
| 08 front | 254 × 121.5 × 9.5 | 45° mitre on both ends and the top edge; window opening 198 × 68, R12 | `cad/dxf/Wood_boards_1to1.dxf` |
| 09 back | 254 × 121.5 × 9.5 | Mitre both ends and the top; cable notch 8 × 10 in the bottom edge | same |
| 10, 11 ends | 100 × 121.5 × 9.5 | Mitre both vertical edges and the top | same |
| 12 top | 254 × 100 × 9.5 | Mitre all four edges; 3 holes Ø8; 4 pilots Ø1.6 × 6.5 deep from below | same |
| 13 brass bezel | 214 × 84 × 1 | 6 holes Ø2.4 | `cad/dxf/Brass_bezel_1mm_1to1.dxf` |
| 14 brass feet × 4 | Ø14 × 8 | Hole Ø2.4, counterbore Ø4.2 × 2.2, 1 mm chamfer | `cad/step/14_brass_foot.step` |

Sizes are the **outer faces** of the mitred boards; grain runs along the long side of each board. The finished box is 254 × 100 × 121.5 mm, 129.5 mm tall on its feet, and weighs about 530 g in walnut. STEP models of every board are in `cad/step/08_…` to `12_…`.

## Wood

- **Black walnut** is the default. Oak, cherry and ash work too; avoid soft, resinous woods.
- Buy one board **planed to 9.5 mm, 130 mm wide and about 1.1 m long**. Let it sit indoors for a week first.
- Cut the four sides from one length, in order **front · right end · back · left end**, so the grain wraps continuously round the corners. The top comes from what is left.

## Steps

1. **Print the inner case first.** It is the gauge for everything that follows.
2. **Cut the boards** about 1 mm long, then mitre them at exactly 45° on a table saw with a sled, a mitre saw, or a mitre box and shooting board. Test the angle on offcuts: four test pieces must close into a square with no gap.
3. **Window opening** in the front: drill a 10 mm hole inside each corner, saw between them with a coping, scroll or jig saw, and file to the line. Or send the front DXF to a CNC or laser service. The cut edge is hidden behind the brass bezel, so it does not need to be perfect.
4. **Cable notch** in the bottom edge of the back, 8 mm wide and 10 mm high, centred 40 mm from the right-hand end as seen from the front.
5. **Glue-up (tape-hinge method).** Lay the four sides face down in order, ends touching, and tape across each joint. Wrap the inner case in cling film (so glue cannot stick to it), spread PVA glue on the mitres, roll the boards up round the inner case and tape the last joint. Then glue the top on, again with the wrapped inner case inside as the form, and tape or clamp it. Wipe squeeze-out with a damp cloth.
6. **Holes in the top, drilled through the inner case so they line up.** With the glue dry, put the inner case (film off) into the box. From inside, drill each of the four roof holes with a **1.6 mm** bit set to stop 9.5 mm past the inside of the roof (3 mm roof + 6.5 mm into the wood): it must **not** break through the top. Then drill a 6 mm pilot up through each of the three button guides, take the inner case out, and open those three holes to 8 mm from outside.
7. **Round over** every outer edge to about R3 with a 3 mm roundover bit or a sanding block. Sand 120 → 180 → 240, wipe with a damp cloth to raise the grain, then 320.
8. **Finish** the outside with two or three coats of hardwax or Danish oil, then paste wax. Leave the inside faces bare or give them one coat; keep finish out of the screw pilots.
9. **Brass bezel.** Have the DXF cut by a laser or waterjet service, or cut it from 1 mm sheet with a fret saw and files. Deburr, then brush in one direction with a fine abrasive pad (or polish), degrease and clear-lacquer it, or leave it to patina. Centre it on the window, mark the six holes, drill 1.6 mm pilots 6.5 mm deep, cut each thread with a **steel** M2 × 6 first, then drive the **waxed brass** M2 × 6 pan-head screws. Brass screws snap easily in walnut.
10. **Brass feet.** Cut four 8 mm slices from 14 mm brass bar, face them flat, drill 2.4 mm through the centre, counterbore 4.2 mm × 2.2 mm deep on the bottom face, chamfer the bottom edge, and polish. No lathe? Print part 14 in silk brass instead.
11. **Button rods.** Print part 04 in silk brass, or turn them from brass (6 mm shaft, 10.5 mm cap, 96.5 mm overall, 4.2 mm × 2 mm cup in the bottom). Solid brass rods weigh about 0.24 N each, still well under the switches' 1.47 N actuation force.
12. **Fit the box.** Vacuum everything. Slip the box over the inner case and drive 4 × M2 × 8 up through the roof into the pilots. The wood is never glued to the inner case, so it can come off again.

**PASS / FIX / STOP** for this work is in the [build guide](BUILD_GUIDE.md#woodwork-and-brass-no-electronics-any-time).

## Why the wood is cladding, not the enclosure

- **Precision lives in the print.** The window slot, the button guides and the screw blocks are printed to tenths of a millimetre; wood moves with the seasons. A 0.5 mm gap on every side lets it.
- **High voltage stays inside the printed case.** The wood never touches the circuit board, the tubes or any HV part, and the case is never run with only the wood around it.
- **Combustibility.** Wood and PETG both burn; no flammability rating is claimed for either. The anode-resistor fault power in [VALIDATION.md](VALIDATION.md#open-items) is an open item for the same reason.
- **Heat.** The wood adds insulation. With it, the modelled average rise inside the sealed case is about 3–5 K ([EQUATIONS.md](EQUATIONS.md#7-sealed-case-temperature)); Stage 5 of the build guide measures the hot spots with the box on.

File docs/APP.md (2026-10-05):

# App: Nixie Clock Companion

The same content comes in three forms. Pick whichever suits you; they all show the same build guide.

| Form | Where | Works offline | Talks to the clock over USB |
|---|---|---|---|
| **Website** | GitHub Pages: `https://<owner>.github.io/nixie-clock/` | After the first visit (installable web app) | Yes, in Chrome or Edge on a desktop computer |
| **Installable web app** | Open the website in Chrome or Edge, then *Install* (the icon in the address bar) or *Add to Home screen* on a phone | Yes | Desktop Chrome and Edge only |
| **Desktop app** | The repository's *Releases* page: Windows `.exe` (installer or portable), macOS `.dmg`, Linux `.AppImage` or `.deb` | Yes, fully | Yes, on all three |

## What the app adds

- **[Tools](tools.html)**: a live calculator for tube current, resistor power, converter load and discharge time, using the same formulas as [Equations](EQUATIONS.md). Its results are a model, not measurements.
- **Serial companion**: connects to the clock's Arduino Nano at 115200 baud and sends the firmware's own commands: `STATUS`, set the clock from your computer's time, 12/24-hour, sleep window, `EXERCISE`, `RUN`, a large **HV OFF** button, and `CLEARFAULT`, which only works after you tick "I measured TP4 below 10 V and fixed the cause". It sends nothing the firmware does not already accept from the Arduino serial monitor.
- Every page of the build guide, the schematic PDF, the print plates and the window-panel DXF, available offline.

> **Safety is unchanged.** The USB port is inside the closed case (lift the case off the chassis to reach it). Follow [SAFETY.md](SAFETY.md#usb-the-shunt-and-the-serial-monitor): connect USB before 12 V, and treat the HV rail as live until you have measured TP4. Connecting resets the Nano, and the firmware keeps any HV fault latched across that reset.

## Installing the desktop app

The builds are **not code-signed** (signing certificates cost money and Rev C is a prototype), so your operating system will warn you the first time:

- **Windows:** *Windows protected your PC* → *More info* → *Run anyway*. The portable `.exe` needs no install.
- **macOS:** right-click the app → *Open* → *Open*. If macOS still refuses, run `xattr -dr com.apple.quarantine "/Applications/Nixie Clock Companion.app"`.
- **Linux:** `chmod +x NixieClockCompanion-*.AppImage` then run it, or `sudo apt install ./NixieClockCompanion-*.deb`. For USB serial access, add yourself to the `dialout` group once: `sudo usermod -aG dialout $USER`, then log out and back in.
- **Windows Subsystem for Linux (WSL):** run the Windows build instead. WSL cannot see USB serial ports without extra tools.

Each release lists SHA-256 checksums so you can verify the download (see [SECURITY.md](SECURITY.md#signed-releases)).

## How it is built

- `app/` is a small Electron app: `main.js` opens the prebuilt `site/` folder (copied into `app/www` by `copy-site.js`), keeps pages sandboxed with no Node.js access, opens every web link in your normal browser, and picks the Nano's USB serial port automatically (Arduino, CH340, FTDI or CP210x adapters, else the first port).
- Versions are pinned in `app/package.json` and `app/package-lock.json`. Dependabot proposes updates.
- Pushing a tag named `app-vX.Y.Z` runs `.github/workflows/desktop.yml`, which builds on Windows, macOS and Linux runners and attaches the files to a GitHub Release. `scripts/release_app.sh` does the version bump, tag and push for you ([DEVELOP.md](DEVELOP.md)).
- The installable web app comes from `site/manifest.webmanifest` and `site/sw.js`, both generated by `scripts/build_site.py`.

## Status

Recorded on 2026-10-02: the Linux AppImage and `.deb` were packaged with electron-builder 26.15.3 (Electron 44.5.1), and the app was launched on a virtual display. It loaded, the Tools calculator gave the documented 1.14 mA, Web Serial was available, and a connect attempt with no device gave a clean message. The Windows and macOS builds are produced by GitHub Actions on the first release and have not been run by anyone yet. The serial companion has **not** been tried against a real Nano. Record what you find in [VALIDATION.md](VALIDATION.md).

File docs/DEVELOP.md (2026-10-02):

# Keep building

Everyday commands for after the repository is on GitHub ([PUBLISH.md](PUBLISH.md) does the first push). Every block is meant to be pasted into an Ubuntu or WSL terminal as is. They all start with `cd ~/nixie-clock`, so you can paste them from anywhere, and they never touch your home folder's own files.

## One-time: install the full toolchain (optional)

Needed only to rerun every generator and check locally (KiCad, AVR compiler, CadQuery, the desktop app). The quick checks and `ship.sh` work without it.

```bash
cd ~/nixie-clock && scripts/setup_dev.sh
```

## After you change something: check, commit, push

Rebuilds the website, runs the quick checks, refreshes `SHA256SUMS`, commits and pushes. Pages redeploys by itself.

```bash
cd ~/nixie-clock && scripts/ship.sh "Describe what you changed"
```

## Run every recorded check

```bash
cd ~/nixie-clock && scripts/run_all_checks.sh
```

## Change the enclosure

Edit a value in `cad/DIMENSIONS.json`, then rebuild every STEP, STL, 3MF, plate, the DXF and the previews, and ship:

```bash
cd ~/nixie-clock && scripts/render_cad && scripts/ship.sh "Enclosure: describe the change"
```

## Change the BOM, requirements, drawings or labels

Edit the list at the top of the matching script, regenerate, check and ship:

```bash
cd ~/nixie-clock && python3 scripts/make_bom.py && python3 scripts/make_requirements.py && python3 scripts/make_drawings.py && python3 tests/check_requirements.py && scripts/ship.sh "BOM/requirements: describe the change"
```

`scripts/make_labels.py` regenerates `docs/labels.pdf` (needs the CairoSVG package from `scripts/setup_dev.sh`).

## Make the PCB fabrication package (only after routing and review)

Refuses until `hardware/Nixie_RevC.kicad_pcb` is routed, passes KiCad's own DRC and `hardware/REVIEW_SIGNOFF.md` is approved. See [MANUFACTURING.md](MANUFACTURING.md#3-pcb-fabrication-blocked-until-the-release-gate-passes).

```bash
cd ~/nixie-clock && scripts/make_fab_outputs.sh
```

## Change the circuit tables or KiCad files

Edit `scripts/make_design_tables.py` (the net map and placement come from it), then:

```bash
cd ~/nixie-clock && python3 scripts/make_design_tables.py && python3 tests/check_design.py && /usr/bin/python3 scripts/make_kicad.py && kicad-cli sch export pdf -o docs/Nixie_RevC_schematic.pdf hardware/Nixie_RevC.kicad_sch && scripts/ship.sh "Circuit: describe the change"
```

## Try the desktop app locally

On Windows 11 WSL the window opens through WSLg. On plain Ubuntu it opens normally.

```bash
cd ~/nixie-clock/app && npm ci --no-audit --no-fund && npm start
```

## Release a new desktop app version

Bumps the version, tags `app-vX.Y.Z` and pushes. GitHub Actions builds Windows, macOS and Linux files into a Release (about 10 minutes).

```bash
cd ~/nixie-clock && scripts/release_app.sh 1.0.1
```

## Bring in a new nixie-clock.zip (for example from Claude)

Put the new `nixie-clock.zip` in your Downloads folder (Windows Downloads works too under WSL), then:

```bash
cd ~/nixie-clock && scripts/apply_zip.sh && scripts/ship.sh "Apply new nixie-clock.zip"
```

`apply_zip.sh` replaces files, removes files the new ZIP no longer has, and leaves `.git`, `node_modules`, `.venv` and `.build` alone.

## Record a bench result

Fill in the build log in `docs/VALIDATION.md`, then ship it. Claim only what you measured.

```bash
cd ~/nixie-clock && nano docs/VALIDATION.md && scripts/ship.sh "Validation: Stage N results"
```

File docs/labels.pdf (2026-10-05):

Six-Tube Nixie Clock Rev C labels. Print at 100 %, check the 50 mm bar, cut on the grey lines.

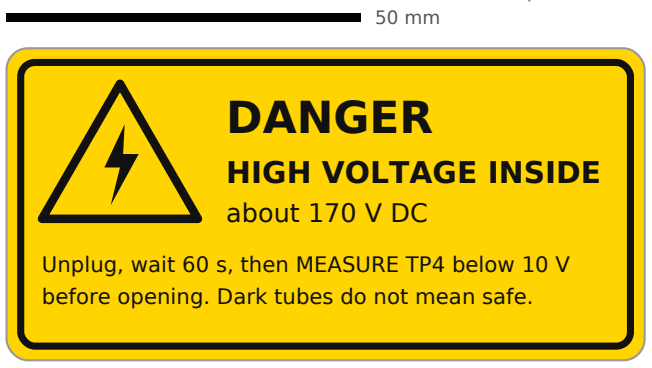
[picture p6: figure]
DANGER; HIGH VOLTAGE INSIDE about 170 V DC

Unplug, wait 60 s, then MEASURE TP4 below 10 V before opening. Dark tubes do not mean safe.

## Six-Tube Nixie Clock

Rev C · UNVALIDATED PROTOTYPE

Input: 12 V DC, 1 A, centre positive
5.5 x 2.1 mm plug · isolated regulated adapter only High voltage inside · read docs/SAFETY.md

Serial: ______________ Built: ___________

These labels are reminders, not a safety certification. The build is an unvalidated engineering prototype.

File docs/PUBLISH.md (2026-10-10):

# Publishing the repository to GitHub

One paste puts the project on GitHub in both forms:

- **Website** on GitHub Pages (also installable as an offline web app from Chrome or Edge), and
- **Desktop app** (Windows, macOS, Linux), built by GitHub Actions from the `app-v1.0.0` tag and attached to a GitHub Release.

Paste the block below **once** into an Ubuntu terminal (Windows Subsystem for Linux, WSL, works too). It:

1. installs `git`, the GitHub command-line interface (`gh`), `unzip` and `rsync` (the only step that uses `sudo`);
2. signs `gh` in as the account in `OWNER` (**the one interactive step**, only the first time: a browser code appears). If `gh` already knows that account it just switches to it;
3. pushes over SSH when `~/.ssh/config` has a host alias for that account (for example `github-normansrule`), otherwise over HTTPS with the `gh` token and the `workflow` permission;
4. finds `nixie-clock.zip` in `~/Downloads` or, under WSL, in your Windows Downloads folder;
5. unpacks it to `~/nixie-clock` (its own folder, and it refuses to run git anywhere else, which matters if your home folder is itself a git repository). If the repository is already there, it is brought exactly in line with the ZIP: files the new version no longer has are removed, so old and new designs never mix;
6. commits, creates the public repository, pushes `main`, turns on Pages, waits for the site, tags the desktop release and prints all the links.

It is safe to run again: every step checks what already exists and only does what is missing. Everything runs inside `( ... )`, so an error stops the script without closing your terminal. Change `OWNER` on the first line if the repository should belong to a different GitHub account.

```bash
(
set -euo pipefail
# 0. Settings: the GitHub account that will own the repository
OWNER="Normansrule"; REPO="nixie-clock"; DEST="$HOME/$REPO"
# 1. Install git, GitHub CLI, unzip and rsync (the only sudo step)
sudo apt-get update -qq
sudo apt-get install -y -qq git gh unzip rsync python3
# 2. Sign the GitHub CLI in as $OWNER (interactive only the first time)
gh auth status -h github.com >/dev/null 2>&1 || gh auth login -h github.com -p https -w -s workflow
if [ "$(gh api user --jq .login)" != "$OWNER" ]; then gh auth switch -h github.com -u "$OWNER" >/dev/null 2>&1 || gh auth login -h github.com -p https -w -s workflow; fi
[ "$(gh api user --jq .login)" = "$OWNER" ] || { echo "GitHub CLI is signed in as $(gh api user --jq .login), not $OWNER: run gh auth login and choose $OWNER"; false; }
# 3. Choose how to push: SSH host alias for $OWNER if ~/.ssh/config has one, else HTTPS with the gh token
ALIAS="$(awk -v o="$(printf %s "$OWNER" | tr '[:upper:]' '[:lower:]')" 'tolower($1)=="host" && index(tolower($2),o){print $2; exit}' "$HOME/.ssh/config" 2>/dev/null || true)"
if [ -n "$ALIAS" ]; then URL="git@$ALIAS:$OWNER/$REPO.git"; else
  SCOPES="$(gh api -i user 2>/dev/null | tr -d '\r' | grep -i '^x-oauth-scopes:' || true)"
  case "$SCOPES" in *workflow*) ;; *) gh auth refresh -h github.com -s workflow ;; esac
  gh auth setup-git -h github.com; URL="https://github.com/$OWNER/$REPO.git"; fi
echo "Pushing to $URL"
# 4. Find the ZIP: ~/Downloads first, then the Windows Downloads folder when running under WSL
ZIP="$HOME/Downloads/$REPO.zip"
[ -f "$ZIP" ] || ZIP="$(ls -t /mnt/c/Users/*/Downloads/$REPO*.zip 2>/dev/null | head -n1 || true)"
[ -f "$ZIP" ] || { echo "Could not find $REPO.zip in ~/Downloads or /mnt/c/Users/*/Downloads"; false; }
# 5. Unpack to ~/nixie-clock: a fresh folder, or an existing repository brought exactly in line with the ZIP
#    (files the new ZIP no longer has are removed; .git and local build folders are kept)
TMP="$(mktemp -d)"; unzip -q "$ZIP" -d "$TMP"
[ -f "$TMP/$REPO/docs/SAFETY.md" ] || { echo "$ZIP does not contain the $REPO folder"; false; }
mkdir -p "$DEST"
rsync -a --delete --exclude '.git/' --exclude 'node_modules/' --exclude '.venv/' --exclude '.build/' --exclude 'app/www/' --exclude 'app/dist/' --exclude 'fab/' "$TMP/$REPO/" "$DEST/"
rm -rf "$TMP"
cd "$DEST"
[ "$PWD" = "$DEST" ] && [ -f docs/SAFETY.md ] && [ -f app/package.json ] || { echo "Not in the unpacked repository: stopping"; false; }
# 6. Start the repository on branch main and make sure git is using this folder, not a parent repository
[ -d .git ] || git init -q -b main
[ "$(git rev-parse --show-toplevel)" = "$DEST" ] || { echo "git is not rooted at $DEST: stopping"; false; }
git config user.name >/dev/null || git config user.name "$OWNER"
git config user.email >/dev/null || git config user.email "$(gh api user --jq .id)+$OWNER@users.noreply.github.com"
# 7. Commit everything (skipped if nothing changed)
git add -A
git diff --cached --quiet || git commit -qm "Six-Tube Nixie Clock Rev C: walnut and brass heirloom case, build guide, KiCad, CAD, firmware, website and desktop app"
# 8. Create the public GitHub repository if it does not exist, and point origin at it
gh repo view "$OWNER/$REPO" >/dev/null 2>&1 || gh repo create "$OWNER/$REPO" --public -d "Six-tube IN-14 Nixie clock: build guide, KiCad, CadQuery, firmware, website and desktop app (Rev C, unvalidated)" --homepage "https://$(printf %s "$OWNER" | tr '[:upper:]' '[:lower:]').github.io/$REPO/"
git remote add origin "$URL" 2>/dev/null || git remote set-url origin "$URL"
gh api -X POST "repos/$OWNER/$REPO/pages" -f build_type=workflow >/dev/null 2>&1 || true
# 9. Push main, then make sure GitHub Pages is on (published by the repository's pages workflow)
git push -q -u origin main
gh api -X POST "repos/$OWNER/$REPO/pages" -f build_type=workflow >/dev/null 2>&1 || gh api -X PUT "repos/$OWNER/$REPO/pages" -f build_type=workflow >/dev/null
# 10. Start a fresh Pages deployment and wait for that run (not an older one) to finish
OLD="$(gh run list -R "$OWNER/$REPO" -w pages.yml -e workflow_dispatch -L 1 --json databaseId --jq '.[0].databaseId // ""' 2>/dev/null || true)"
for _ in 1 2 3 4 5 6; do gh workflow run pages.yml -R "$OWNER/$REPO" >/dev/null 2>&1 && break; sleep 5; done
RUN=""; for _ in $(seq 1 24); do RUN="$(gh run list -R "$OWNER/$REPO" -w pages.yml -e workflow_dispatch -L 1 --json databaseId --jq '.[0].databaseId // ""' 2>/dev/null || true)"; [ -n "$RUN" ] && [ "$RUN" != "$OLD" ] && break; sleep 5; done
if [ -n "$RUN" ] && [ "$RUN" != "$OLD" ]; then gh run watch "$RUN" -R "$OWNER/$REPO" --exit-status >/dev/null || echo "Pages run did not finish cleanly: gh run view $RUN -R $OWNER/$REPO --log-failed"; else echo "Pages run not found yet: check the Actions tab"; fi
# 11. Release the desktop app: tag app-v<version> once; GitHub Actions builds Windows, macOS and Linux files
VER="$(python3 -c 'import json; print(json.load(open("app/package.json"))["version"])')"
git rev-parse -q --verify "refs/tags/app-v$VER" >/dev/null || git tag -a "app-v$VER" -m "Nixie Clock Companion $VER"
[ -n "$(git ls-remote --tags origin "refs/tags/app-v$VER")" ] || git push -q origin "app-v$VER"
# 12. Print the links
echo "Website:      $(gh api "repos/$OWNER/$REPO/pages" --jq .html_url 2>/dev/null || echo "https://$OWNER.github.io/$REPO/")"
echo "Repository:   https://github.com/$OWNER/$REPO"
echo "Desktop app:  https://github.com/$OWNER/$REPO/releases/tag/app-v$VER  (ready in about 10 minutes)"
echo "Keep building: cd ~/nixie-clock, then see docs/DEVELOP.md"
)
```

## After that

Everyday commands (check, commit and push; release a new app version; bring in a new ZIP) are in [DEVELOP.md](DEVELOP.md).

## If something goes wrong

- **`refusing to allow an OAuth App to create or update workflow`**: you pushed over HTTPS without the `workflow` permission. Run `gh auth refresh -h github.com -s workflow`, then paste the block again.
- **`Permission denied (publickey)`**: the SSH alias in `~/.ssh/config` does not have a key GitHub accepts for `OWNER`. Test with `ssh -T git@<alias>`, or move the alias out of the way to fall back to HTTPS.
- **Signed in as the wrong account**: `gh auth login -h github.com` and choose the right one, then paste the block again.
- **Pages is not enabled, or the first deploy fails**: open the repository's *Settings → Pages*, set *Source* to *GitHub Actions*, then run `gh workflow run pages.yml -R <owner>/nixie-clock`.
- **The desktop release is missing files**: open the *Actions* tab, choose the *desktop* run, and read the failed job's log. Rerun it with `gh run rerun <run id> --failed -R <owner>/nixie-clock`.
- **The site shows old content**: the site is prebuilt. Run `scripts/ship.sh "Rebuild site"` from `~/nixie-clock`.

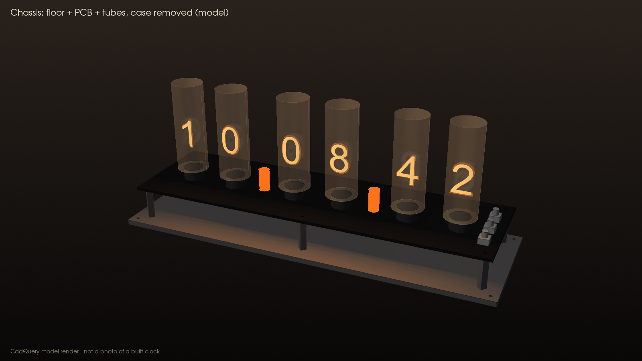
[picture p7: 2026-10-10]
site/img/chassis.png

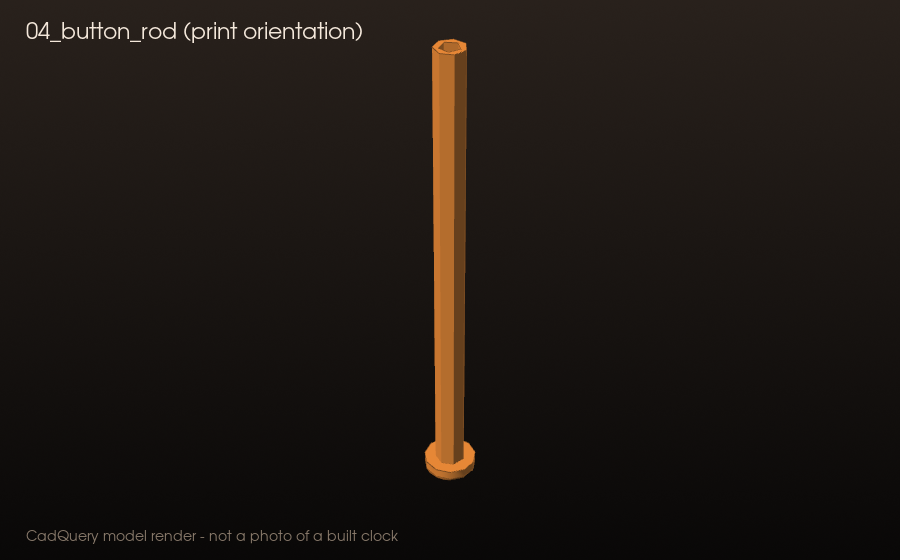
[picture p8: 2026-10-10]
docs/img/part_04_button_rod.png

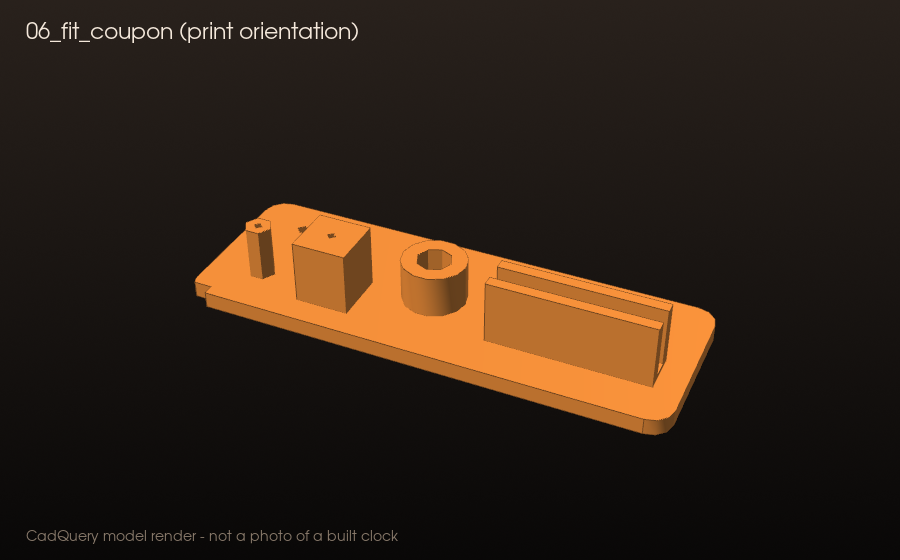
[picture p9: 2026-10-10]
site/img/part_06_fit_coupon.png

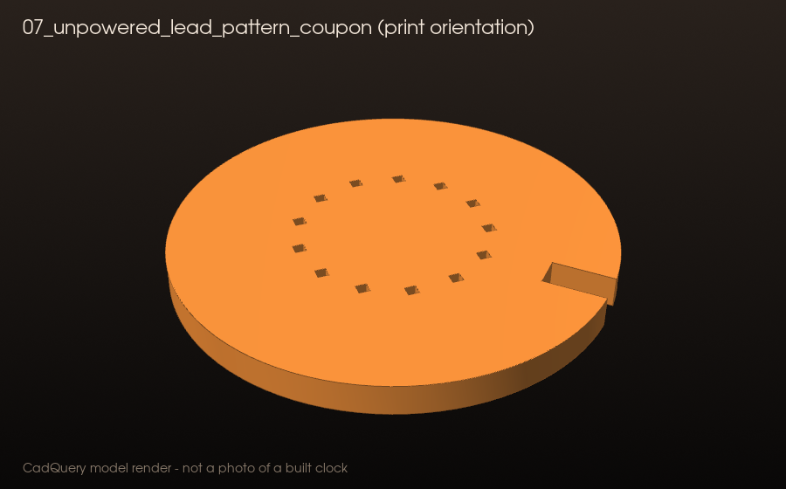
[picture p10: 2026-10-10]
site/img/part_07_unpowered_lead_pattern_coupon.png

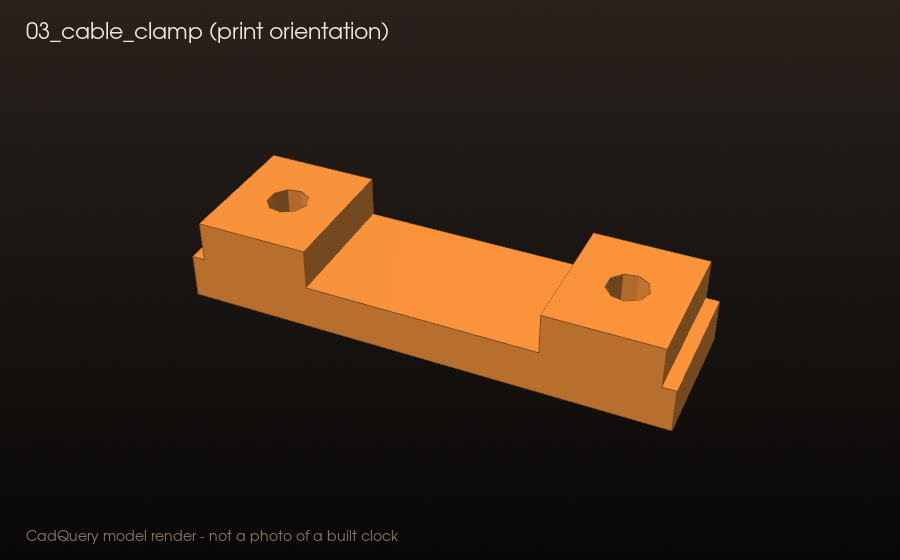
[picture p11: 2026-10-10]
docs/img/part_03_cable_clamp.png

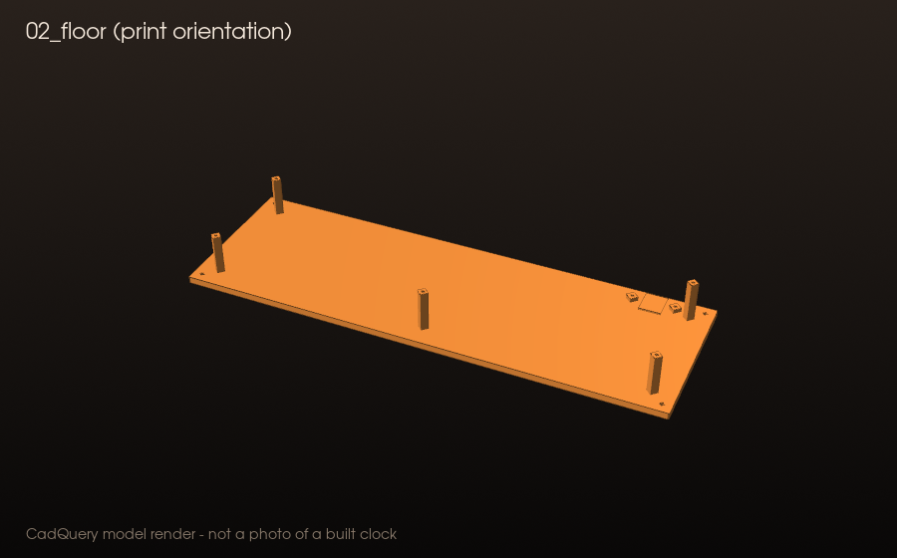
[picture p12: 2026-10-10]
site/img/part_02_floor.png

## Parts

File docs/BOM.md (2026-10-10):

# Bill of materials (Rev C)

Machine-readable versions: [`hardware/BOM.csv`](../hardware/BOM.csv) (electrical, with specs and allowed substitutions) and [`hardware/BOM_mechanical.csv`](../hardware/BOM_mechanical.csv) (enclosure, wood, brass and fasteners, grouped by kind), generated by `scripts/make_bom.py`.

Quantities are **Rev C fitted quantities**, not purchase quantities. Buy one or two spares of the cheap passives, not a whole second kit. Before ordering, check every package suffix, footprint and pinout against the manufacturer's data sheet ([CREDITS.md](../CREDITS.md) lists them). Reference designators match [`hardware/NET_MAP.csv`](../hardware/NET_MAP.csv) and [`hardware/COMPONENT_PLACEMENT.csv`](../hardware/COMPONENT_PLACEMENT.csv); `tests/check_design.py` checks the counts below against the placement table.

**Budget (planning only, recheck before ordering):** about $390 before tax for the electronics and printed case, carried over from the brief's $379–391 planning figures, **plus roughly $60–100 for the walnut, brass, oil and brass screws** (a rough estimate, not re-priced). Tube prices move the total more than anything else.

## Safety-critical parts first

These are the parts you must not substitute with something cheaper or lower-rated.

| Qty | Ref | Part | Why it matters |
|---|---|---|---|
| 6 | RA1–RA6 | 22 kΩ 1 % **1 W** axial, Vishay PR01 series | Tube anode resistors. 1 W is for voltage stress and fault margin (see [EQUATIONS.md](EQUATIONS.md#2-resistor-power-why-the-anode-resistors-are-1-w)). Do **not** confuse with RS3. |
| 2 | RL1, RL2 | 220 kΩ 1 % **1 W** axial, PR01 | Neon lamp resistors |
| 2 | RH1, RH2 | 110 kΩ 1206, **≥0.5 W, ≥200 V** | HV bleeder. Each sees 85 V |
| 2 | RS1, RS2 | 1 MΩ 1206, ≥0.25 W, **≥200 V** | HV sense divider top |
| 1 | CHV | 100 nF **≥250 V** 1210, ≤3 mm tall | HV rail capacitor. Never a low-voltage substitute |
| 1 | F1 | Littelfuse 1812L075/33DR resettable fuse (positive temperature coefficient, PTC) | 12 V input protection |
| 1 | QP1 | Diodes DMP3098L-7 P-channel metal-oxide-semiconductor field-effect transistor (P-MOSFET), SOT-23 (small-outline transistor) package | Reverse-polarity protection |
| — | — | Insulation sleeving rated **≥300 V (600 V preferred)** | Over every neon lamp lead |
| 1 | — | **Isolated**, regulated 12 V, ≥1 A adapter, centre-positive 5.5 × 2.1 mm | Keeps mains outside the clock |

## Tubes, modules, integrated circuits (ICs) and controls

| Qty | Ref | Part | Notes |
|---|---|---|---|
| 6 | T1–T6 | IN-14 Nixie tube **with factory spacers** | Direct-solder leads. Bulb about 19 mm; check each against fit coupon 06 |
| 2 | L1, L2 | NE-2 (VCC A1A) neon lamp | Separators. Sleeve both leads |
| 2 | U1, U2 | Microchip **HV5522PJ-G** (44-lead PLCC, Plastic Leaded Chip Carrier) | Not the HV5522PG-G (different package) |
| 1 | A1 | Arduino Nano Classic A000005 (ATmega328P) | Not a Nano Every or ESP32 board |
| 1 | U3 | Analog Devices **DS3231SN#** real-time clock (RTC), SOIC-16 wide (small-outline integrated circuit) | Temperature-compensated |
| 1 | PS1 | Omnixie **NCH8200HV** 12 V → ~170 V module | 2.5–15 V input, fixed output, no enable pin |
| 3 | SW1–SW3 | Omron **B3F-1062-G** 7 mm tactile switch | SET, H, M. Not the 4.3 mm B3F-1002 |
| 1 | QP2 | Diodes DMP3098L-7 P-MOSFET, SOT-23 | HV converter switch |
| 5 | QE1, QL1–QL4 | MMBT3904 NPN bipolar transistor, SOT-23 | Level shifters and HV enable |
| 1 | QL5 | MMBT3906 PNP bipolar transistor, SOT-23 | Blanking stage |
| 1 | JP1 | 1×2 2.54 mm header + shunt | **HV_ARM** |

## Low-voltage passives (0805, 1 %, ≥0.125 W, ≥50 V)

| Qty | Value | Refs |
|---|---|---|
| 7 | 100 kΩ | RPD1–RPD5, RGP, RPU5 |
| 11 | 10 kΩ | RB1–RB6, RC1–RC3, RD1, RV2 |
| 1 | 22 kΩ | RS3 (sense divider bottom, **not** an anode resistor) |
| 1 | 47 kΩ | RV1 |
| 2 | 4.7 kΩ | RI1, RI2 (I²C pull-ups) |

## Capacitors

| Qty | Value | Refs | Notes |
|---|---|---|---|
| 3 | 100 nF 0805 | C1, C2, C8 | Driver and RTC decoupling |
| 2 | 10 µF 0805, ≥25 V | C3, C4 | Driver bulk. Check the capacitance left at 12 V bias |
| 1 | 47 µF 25 V radial, ≤6.3 × 8 mm, 2.5 mm pitch | C5 | 12 V input bulk |
| 1 | 10 µF 1210, ≥25 V | C6 | Converter input |
| 1 | 100 nF ≥250 V 1210 | CHV | See safety table |
| 1 | 10 nF 0805 | C7 | HV sense filter |

## Off-board and mechanical

| Qty | Item | Notes |
|---|---|---|
| 1 | 4-layer FR-4 (glass-epoxy) printed circuit board (PCB), 218 × 64 × 1.6 mm | **Not yet routed.** Do not order until the native review in [VALIDATION.md](VALIDATION.md) passes. Matte black solder mask looks best behind the smoked window |
| 1 | Insulated DC-jack pigtail | Through the 4.2 mm rear opening and the notch in the wood, clamped by part 03 |
| 1 | CR2032 **primary** lithium cell | Never a rechargeable LIR2032 (no charging circuit) |
| 1 | Insulated CR2032 holder, ≤30 × 25 × 7 mm | Wired to J2 |
| 2 | 1×15 2.54 mm headers, 6 mm stack | Nano mount |
| 1 | Converter mount set, 4 mm stand-off | For PS1 |
| 2 | Cable ties | Wire dressing |
| 1 | USB (Universal Serial Bus) Mini-B **data** cable | Charge-only cables will not flash |

### Heirloom case

| Qty | Item | Notes |
|---|---|---|
| — | PETG (polyethylene terephthalate glycol) filament, **matte black** | About 400 g: inner case, floor, clamp, coupons, plus supports (estimated from model volume) |
| — | Silk brass (or gold) PLA or PETG | About 15 g: three button rods (and the feet, if printed) |
| 1 | Window panel, 3 mm smoked grey or bronze **cast** acrylic, laser cut from [`cad/dxf/Window_panel_3mm_1to1.dxf`](../cad/dxf/Window_panel_3mm_1to1.dxf) | 206 × 92.8 mm |
| — | Clear neutral-cure silicone | Three dots hold the window in its slot |
| 1 | Hardwood board, black walnut (or oak, cherry, ash), planed to 9.5 mm, 130 mm × 1.1 m | Five mitred boards ([WOODWORK.md](WOODWORK.md), [`cad/dxf/Wood_boards_1to1.dxf`](../cad/dxf/Wood_boards_1to1.dxf)) |
| — | PVA wood glue, wide masking tape, sandpaper 120–320 grit | Mitre glue-up and R3 roundover |
| — | Hardwax or Danish oil, paste wax | Outside faces |
| 1 | Brass bezel, 1 mm sheet (CuZn37 / C272 or C260), cut from [`cad/dxf/Brass_bezel_1mm_1to1.dxf`](../cad/dxf/Brass_bezel_1mm_1to1.dxf) | 214 × 84 mm; brushed or polished, lacquered or left to patina |
| 1 | Brass round bar, 14 mm × 40 mm (free-machining CuZn39Pb3 / C360) | Four 8 mm feet (part 14), or print them in silk brass |
| 4 | Felt washers, 14 mm outside, 5 mm hole | Under the brass feet |
| — | Fit coupons 06 and 07 | Print first ([PRINTING.md](PRINTING.md)) |

## M2 fasteners

M2 throughout, no M3 or M4. Printed posts have 1.7 mm pilot holes (not heat-set inserts): tap M2 after checking the coupon. Wood pilots are 1.6 mm, 6.5 mm deep.

| Screw | Qty | Uses |
|---|---|---|
| M2 × 16 socket head | 4 | Through each brass foot and the floor into the corner blocks of the inner case (from below) |
| M2 × 8 | 4 | Up through the inner-case roof into the wood top |
| M2 × 6 | 7 | 5 × PCB onto the floor standoffs, 2 × cable clamp |
| M2 × 6 brass pan head | 6 | Brass bezel onto the wood front (cut the thread with a steel screw first) |

## Cost levers that are safe to pull

- Generic passives from a reputable distributor, at the ratings above.
- Smoked acrylic offcuts are cheap: the window is only 206 × 92.8 mm.
- Print the brass feet and rods in silk brass instead of machining brass; skip the wood and use the printed inner case alone (the printed edition). Neither changes anything electrical.
- Tubes and ICs from reputable sellers (fakes and pulls are common); do not overbuy spares.

Do **not** cheapen: the 1 W tube and lamp resistors, CHV, the bleeders, the sleeving, the isolated adapter, or the fused, reverse-protected input.

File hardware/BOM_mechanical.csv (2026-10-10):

option | qty | item | spec | file
electronics | 1 | 4-layer FR-4 printed circuit board (PCB) 218 x 64 x 1.6 mm | NOT YET ROUTED: see docs/MANUFACTURING.md release gate. Matte black solder mask suits the case (cosmetic; any colour works) | hardware/
electronics | 1 | Isolated regulated 12 V adapter, >=1 A, centre-positive 5.5 x 2.1 mm | SAFETY ITEM: isolated, regulated, from a reputable maker | -
electronics | 1 | Insulated DC-jack pigtail, 5.5 x 2.1 mm female, about 150 mm | outer diameter about 4 mm to suit the 4.2 mm rear hole and clamp | -
electronics | 1 | CR2032 primary lithium cell | never a rechargeable LIR2032 | -
electronics | 1 | Insulated CR2032 holder with leads | <=30 x 25 x 7 mm | -
electronics | 2 | 1x15 female headers, 2.54 mm | Nano socket, about 6 mm stack | -
electronics | 1 | Converter mount set (stand-offs) for the NCH8200HV | 4 mm separation from the board | -
electronics | 1 | Insulation sleeving for neon leads, about 300 mm | SAFETY ITEM: rated >=300 V, 600 V preferred | -
electronics | 2 | Cable ties, small | wire dressing | -
electronics | 1 | USB Mini-B data cable | data-capable, for flashing | -
printed | 1 | PETG filament, matte black | about 400 g for the inner case, floor, clamp and coupons, plus supports | -
printed | 1 | Silk brass (or gold) PLA or PETG filament | about 15 g for the three button rods (and the feet if you print them) | -
printed | 1 | Printed part 01 inner case (carries every functional feature) | PETG black, upright, tree supports inside under the roof | cad/stl/01_inner_case.stl
printed | 1 | Printed part 02 floor (carries the PCB on 5 standoffs) | PETG | cad/stl/02_floor.stl
printed | 1 | Printed part 03 cable clamp | PETG | cad/stl/03_cable_clamp.stl
printed | 3 | Part 04 button rod (SET, H, M) | silk brass filament, cap down, brim; or turned from 12 mm brass bar | cad/stl/04_button_rod.stl
printed | 1 | Printed part 06 fit coupon (print first) | PETG | cad/stl/06_fit_coupon.stl
printed | 1 | Printed part 07 unpowered lead-pattern coupon (never powered) | PETG | cad/stl/07_unpowered_lead_pattern_coupon.stl
cut | 1 | Part 05 window panel, laser cut | 3 mm smoked grey or bronze CAST acrylic, 206 x 92.8 mm | cad/dxf/Window_panel_3mm_1to1.dxf
cut | 1 | Clear neutral-cure silicone, small tube | 3 dots hold the window panel in its slot so it cannot drop out when the case is lifted | -
cut | 1 | Part 13 brass bezel, laser or waterjet cut (or fret saw) | 1 mm brass sheet CuZn37 / C272 or C260, 214 x 84 mm outline, 6 holes 2.4 mm; brush or polish, then clear lacquer or wax | cad/dxf/Brass_bezel_1mm_1to1.dxf
wood | 1 | Hardwood board for parts 08-12 | black walnut (or oak, cherry, ash), planed to 9.5 mm, 130 mm wide x 1.1 m: the four sides from one length for a continuous grain wrap, plus the top | cad/dxf/Wood_boards_1to1.dxf
wood | 1 | PVA wood glue (water resistant, e.g. type II) | for the eight mitre joints only; the wood is never glued to the inner case | -
wood | 1 | Wide masking tape | mitre glue-up: tape the boards face-down edge to edge and fold them into a box | -
wood | 1 | Sandpaper 120, 180, 240, 320 grit | round over the outer edges to R3 by hand or with a 3 mm roundover bit | -
wood | 1 | Hardwax oil or Danish oil, small tin, and paste wax | finish outside faces only; leave the inside and the window opening edge raw or dark-stained | -
brass | 1 | Brass round bar, 14 mm diameter x 40 mm | free-machining CuZn39Pb3 / C360; four 8 mm slices, each drilled 2.4 mm and counterbored 4.2 x 2.2 mm (part 14); or print the feet in silk brass | cad/step/14_brass_foot.step
brass | 4 | Felt washers, 14 mm OD, 5 mm hole | under the brass feet, to protect furniture; leave the screw heads reachable | -
labels | 1 | Printed HV warning and rating labels | docs/labels.pdf, on the underside of the floor | docs/labels.pdf
fasteners | 4 | M2 x 16 socket-head screw | through each brass foot and the floor into the inner-case corner blocks | -
fasteners | 4 | M2 x 8 screw | up through the inner-case roof into the wood top (6.5 mm pilots, 1.6 mm drill) | -
fasteners | 7 | M2 x 6 screw | 5 PCB to floor standoffs + 2 cable clamp | -
fasteners | 6 | M2 x 6 brass pan-head screw | brass bezel to wood front (1.6 mm pilots, 6.5 mm deep) | -

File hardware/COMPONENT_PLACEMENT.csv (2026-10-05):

ref | value | footprint_intent | side | x_mm | y_mm | rot_deg | note
T1 | IN-14 | local:IN-14_direct_solder | top | 32 | 35 | 0 | fixed by enclosure; numerals face -Y (front)
T2 | IN-14 | local:IN-14_direct_solder | top | 62 | 35 | 0 | fixed by enclosure; numerals face -Y (front)
T3 | IN-14 | local:IN-14_direct_solder | top | 102 | 35 | 0 | fixed by enclosure; numerals face -Y (front)
T4 | IN-14 | local:IN-14_direct_solder | top | 132 | 35 | 0 | fixed by enclosure; numerals face -Y (front)
T5 | IN-14 | local:IN-14_direct_solder | top | 172 | 35 | 0 | fixed by enclosure; numerals face -Y (front)
T6 | IN-14 | local:IN-14_direct_solder | top | 202 | 35 | 0 | fixed by enclosure; numerals face -Y (front)
L1 | NE-2 / VCC A1A | local:NE2_upright_sleeved | top | 82 | 35 | 0 | fixed by enclosure
L2 | NE-2 / VCC A1A | local:NE2_upright_sleeved | top | 152 | 35 | 0 | fixed by enclosure
SW1 | B3F-1062-G (SET) | Button_Switch_THT:SW_PUSH_6mm | top | 218 | 24 | 0 | fixed by enclosure
SW2 | B3F-1062-G (H) | Button_Switch_THT:SW_PUSH_6mm | top | 218 | 38 | 0 | fixed by enclosure
SW3 | B3F-1062-G (M) | Button_Switch_THT:SW_PUSH_6mm | top | 218 | 52 | 0 | fixed by enclosure
H1 | M2 mounting hole | MountingHole:MountingHole_2.2mm_M2 | both | 13 | 13 | 0 | fixed by enclosure
H2 | M2 mounting hole | MountingHole:MountingHole_2.2mm_M2 | both | 117 | 13 | 0 | fixed by enclosure
H3 | M2 mounting hole | MountingHole:MountingHole_2.2mm_M2 | both | 221 | 13 | 0 | fixed by enclosure
H4 | M2 mounting hole | MountingHole:MountingHole_2.2mm_M2 | both | 13 | 67 | 0 | fixed by enclosure
H5 | M2 mounting hole | MountingHole:MountingHole_2.2mm_M2 | both | 221 | 67 | 0 | fixed by enclosure
U1 | HV5522PJ-G | Package_LCC:PLCC-44 | bottom | 80 | 18 | 0 | planning position
U2 | HV5522PJ-G | Package_LCC:PLCC-44 | bottom | 152 | 18 | 0 | planning position
A1 | Arduino Nano Classic A000005 | Module:Arduino_Nano (2x 1x15 headers, 6 mm) | bottom | 40 | 58 | 0 | planning position
PS1 | NCH8200HV | Nixie_RevC:PLACEHOLDER_NCH8200HV_30x21 (size VERIFY) | bottom | 125 | 58 | 0 | planning position
U3 | DS3231SN# | Package_SO:SOIC-16W_7.5x10.3mm | bottom | 186 | 18 | 0 | planning position
F1 | 1812L075/33DR | Fuse:Fuse_1812 | bottom | 211 | 67 | 0 | planning position
QP1 | DMP3098L-7 | Package_TO_SOT_SMD:SOT-23 | bottom | 211 | 61 | 0 | planning position
QP2 | DMP3098L-7 | Package_TO_SOT_SMD:SOT-23 | bottom | 100 | 50 | 0 | planning position
J1 | 12 V pigtail pads | Nixie_RevC:WirePads_2 (to author) | bottom | 204 | 67 | 0 | planning position
J2 | CR2032 lead pads | Nixie_RevC:WirePads_2 (to author) | bottom | 224 | 45 | 0 | planning position
C5 | 47 uF 25 V radial | Capacitor_THT:CP_Radial_D6.3mm_P2.50mm | bottom | 196 | 60 | 0 | planning position
C6 | 10 uF 1210 | Capacitor_SMD:C_1210 | bottom | 100 | 54 | 0 | planning position
CHV | 100 nF >=250 V 1210 | Capacitor_SMD:C_1210 | bottom | 145 | 50 | 0 | planning position
RH1 | 110 k 1206 >=0.5 W | Resistor_SMD:R_1206 | bottom | 145 | 54 | 0 | planning position
RH2 | 110 k 1206 >=0.5 W | Resistor_SMD:R_1206 | bottom | 145 | 58 | 0 | planning position
RS1 | 1 M 1206 | Resistor_SMD:R_1206 | bottom | 149 | 50 | 0 | planning position
RS2 | 1 M 1206 | Resistor_SMD:R_1206 | bottom | 149 | 54 | 0 | planning position
RS3 | 22 k 0805 | Resistor_SMD:R_0805 | bottom | 149 | 58 | 0 | planning position
C7 | 10 nF 0805 | Capacitor_SMD:C_0805 | bottom | 149 | 62 | 0 | planning position
RA1 | 22 k 1% 1 W PR01 | Resistor_THT:R_Axial_DIN0207_L6.3mm_D2.5mm_P10.16mm_Horizontal | bottom | 42 | 35 | 90 | HV: keep >=2 mm creepage from LV nets
RA2 | 22 k 1% 1 W PR01 | Resistor_THT:R_Axial_DIN0207_L6.3mm_D2.5mm_P10.16mm_Horizontal | bottom | 72 | 35 | 90 | HV: keep >=2 mm creepage from LV nets
RA3 | 22 k 1% 1 W PR01 | Resistor_THT:R_Axial_DIN0207_L6.3mm_D2.5mm_P10.16mm_Horizontal | bottom | 112 | 35 | 90 | HV: keep >=2 mm creepage from LV nets
RA4 | 22 k 1% 1 W PR01 | Resistor_THT:R_Axial_DIN0207_L6.3mm_D2.5mm_P10.16mm_Horizontal | bottom | 142 | 35 | 90 | HV: keep >=2 mm creepage from LV nets
RA5 | 22 k 1% 1 W PR01 | Resistor_THT:R_Axial_DIN0207_L6.3mm_D2.5mm_P10.16mm_Horizontal | bottom | 182 | 35 | 90 | HV: keep >=2 mm creepage from LV nets
RA6 | 22 k 1% 1 W PR01 | Resistor_THT:R_Axial_DIN0207_L6.3mm_D2.5mm_P10.16mm_Horizontal | bottom | 212 | 35 | 90 | HV: keep >=2 mm creepage from LV nets
RL1 | 220 k 1% 1 W PR01 | Resistor_THT:R_Axial_DIN0207_L6.3mm_D2.5mm_P10.16mm_Horizontal | bottom | 86 | 35 | 90 | planning position
RL2 | 220 k 1% 1 W PR01 | Resistor_THT:R_Axial_DIN0207_L6.3mm_D2.5mm_P10.16mm_Horizontal | bottom | 156 | 35 | 90 | planning position
JP1 | 1x2 header + shunt (HV_ARM) | Connector_PinHeader_2.54mm:PinHeader_1x02 | top | 90 | 66 | 0 | top-side service access with the case lifted off
TP1 | GND | TestPoint:TestPoint_Pad_D1.5mm | top | 100 | 68 | 0 | top-side service access with the case lifted off
TP4 | HV170 | TestPoint:TestPoint_Pad_D1.5mm | top | 106 | 68 | 0 | top-side service access with the case lifted off
TP2 | V12 | TestPoint:TestPoint_Pad_D1.5mm | top | 180 | 68 | 0 | top-side service access with the case lifted off
TP3 | V5 | TestPoint:TestPoint_Pad_D1.5mm | top | 186 | 68 | 0 | top-side service access with the case lifted off
C1 | 100 nF 0805 | Capacitor_SMD:C_0805 | bottom | 93 | 12 | 0 | planning position
C3 | 10 uF 0805 | Capacitor_SMD:C_0805 | bottom | 93 | 16 | 0 | planning position
C2 | 100 nF 0805 | Capacitor_SMD:C_0805 | bottom | 165 | 12 | 0 | planning position
C4 | 10 uF 0805 | Capacitor_SMD:C_0805 | bottom | 165 | 16 | 0 | planning position
C8 | 100 nF 0805 | Capacitor_SMD:C_0805 | bottom | 186 | 27 | 0 | planning position
RI1 | 4.7 k 0805 | Resistor_SMD:R_0805 | bottom | 196 | 12 | 0 | planning position
RI2 | 4.7 k 0805 | Resistor_SMD:R_0805 | bottom | 196 | 16 | 0 | planning position
RV1 | 47 k 0805 | Resistor_SMD:R_0805 | bottom | 66 | 50 | 0 | planning position
RV2 | 10 k 0805 | Resistor_SMD:R_0805 | bottom | 66 | 54 | 0 | planning position
QL1 | MMBT3904 | Package_TO_SOT_SMD:SOT-23 | bottom | 97 | 11 | 0 | planning position
RB1 | 10 k 0805 | Resistor_SMD:R_0805 | bottom | 101 | 11 | 0 | planning position
RPD1 | 100 k 0805 | Resistor_SMD:R_0805 | bottom | 105 | 11 | 0 | planning position
RC1 | 10 k 0805 | Resistor_SMD:R_0805 | bottom | 109 | 11 | 0 | planning position
QL2 | MMBT3904 | Package_TO_SOT_SMD:SOT-23 | bottom | 97 | 15 | 0 | planning position
RB2 | 10 k 0805 | Resistor_SMD:R_0805 | bottom | 101 | 15 | 0 | planning position
RPD2 | 100 k 0805 | Resistor_SMD:R_0805 | bottom | 105 | 15 | 0 | planning position
RC2 | 10 k 0805 | Resistor_SMD:R_0805 | bottom | 109 | 15 | 0 | planning position
QL3 | MMBT3904 | Package_TO_SOT_SMD:SOT-23 | bottom | 97 | 19 | 0 | planning position
RB3 | 10 k 0805 | Resistor_SMD:R_0805 | bottom | 101 | 19 | 0 | planning position
RPD3 | 100 k 0805 | Resistor_SMD:R_0805 | bottom | 105 | 19 | 0 | planning position
RC3 | 10 k 0805 | Resistor_SMD:R_0805 | bottom | 109 | 19 | 0 | planning position
QL4 | MMBT3904 | Package_TO_SOT_SMD:SOT-23 | bottom | 97 | 23 | 0 | planning position
RB4 | 10 k 0805 | Resistor_SMD:R_0805 | bottom | 101 | 23 | 0 | planning position
RPD4 | 100 k 0805 | Resistor_SMD:R_0805 | bottom | 105 | 23 | 0 | planning position
RD1 | 10 k 0805 | Resistor_SMD:R_0805 | bottom | 109 | 23 | 0 | planning position
QL5 | MMBT3906 | Package_TO_SOT_SMD:SOT-23 | bottom | 123 | 11 | 0 | planning position
RB6 | 10 k 0805 | Resistor_SMD:R_0805 | bottom | 127 | 11 | 0 | planning position
RPU5 | 100 k 0805 | Resistor_SMD:R_0805 | bottom | 131 | 11 | 0 | planning position
QE1 | MMBT3904 | Package_TO_SOT_SMD:SOT-23 | bottom | 96 | 62 | 0 | planning position
RB5 | 10 k 0805 | Resistor_SMD:R_0805 | bottom | 100 | 62 | 0 | planning position
RPD5 | 100 k 0805 | Resistor_SMD:R_0805 | bottom | 104 | 62 | 0 | planning position
RGP | 100 k 0805 | Resistor_SMD:R_0805 | bottom | 104 | 50 | 0 | planning position

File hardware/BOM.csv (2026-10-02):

line | qty | refs | category | description | manufacturer | mpn_or_series | package | spec | substitution | safety_critical
1 | 2 | U1 U2 | IC | 32-channel serial-to-parallel driver, open-drain, 220 V | Microchip | HV5522PJ-G | PLCC-44 | 220 V outputs, VDD 10.8-13.2 V | not the HV5522PG-G (different package) | yes
2 | 1 | PS1 | Module | 12 V to ~170 V DC-DC boost module | Omnixie | NCH8200HV | module (outline VERIFY) | 2.5-15 V in, ~170 V out, 30 mA peak | none without re-checking HV design | yes
3 | 1 | F1 | Protection | Resettable fuse (PTC, positive temperature coefficient) | Littelfuse | 1812L075/33DR | 1812 | 0.75 A hold, 33 V | SAFETY ITEM: same ratings or better only | yes
4 | 2 | QP1 QP2 | Transistor | P-channel MOSFET (metal-oxide-semiconductor field-effect transistor) | Diodes Inc. | DMP3098L-7 | SOT-23 | -30 V | equivalent P-MOSFET only after V_GS and R_DS(on) review | yes
5 | 1 | JP1 | Connector | 1x2 pin header + jumper shunt (HV_ARM) | generic | 2.54 mm header + shunt | THT 2.54 mm | gold or tin, 2.54 mm | any part meeting the spec | yes
6 | 6 | RA1 RA2 RA3 RA4 RA5 RA6 | Resistor | 22 kOhm 1 % 1 W axial: tube anode | Vishay | PR01 series, 22K0, 1 % | axial DIN0207, 10.16 mm pitch | 1 % , 1 W, metal film | SAFETY ITEM: same ratings or better only | yes
7 | 2 | RL1 RL2 | Resistor | 220 kOhm 1 % 1 W axial: neon lamp | Vishay | PR01 series, 220K, 1 % | axial DIN0207, 10.16 mm pitch | 1 %, 1 W | SAFETY ITEM: same ratings or better only | yes
8 | 2 | RH1 RH2 | Resistor | 110 kOhm 1206: HV bleeder | generic | - | 1206 | >=0.5 W, >=200 V working voltage | SAFETY ITEM: same ratings or better only | yes
9 | 2 | RS1 RS2 | Resistor | 1 MOhm 1206: HV sense divider top | generic | - | 1206 | >=0.25 W, >=200 V working voltage | SAFETY ITEM: same ratings or better only | yes
10 | 1 | CHV | Capacitor | 100 nF HV rail capacitor (CHV) | generic | - | 1210, <=3 mm tall | >=250 V, X7R | SAFETY ITEM: same ratings or better only | yes
11 | 6 | T1 T2 T3 T4 T5 T6 | Tube | IN-14 Nixie tube with factory spacers | various (NOS, new old stock) | IN-14 | 13-lead direct solder | test each tube before soldering; bulb about 19 mm | IN-14 only (enclosure is sized for it) | no
12 | 2 | L1 L2 | Lamp | NE-2 neon lamp, separator | VCC (Visual Communications Company) | A1A (NE-2 type) | wire leads | about 60 V maintaining voltage (verify) | NE-2 equivalent | no
13 | 3 | SW1 SW2 SW3 | Switch | Tactile switch 6x6 mm, 7 mm tall | Omron | B3F-1062-G | THT 4-pin | 7 mm actuator height | not the 4.3 mm B3F-1002 | no
14 | 1 | A1 | Module | Arduino Nano Classic (ATmega328P) | Arduino | A000005 | 2x 1x15 headers, 15.24 mm row spacing | ATmega328P, 16 MHz, 5 V | not Nano Every or Nano ESP32 | no
15 | 1 | U3 | IC | Temperature-compensated real-time clock (RTC) | Analog Devices | DS3231SN# | SOIC-16 wide | +/-2 ppm 0-40 C | DS3231SN# only (not DS3231M) | no
16 | 5 | QL1 QL2 QL3 QL4 QE1 | Transistor | NPN bipolar transistor | onsemi or equivalent | MMBT3904 | SOT-23 | 40 V, 200 mA | any part meeting the spec | no
17 | 1 | QL5 | Transistor | PNP bipolar transistor | onsemi or equivalent | MMBT3906 | SOT-23 | -40 V, -200 mA | any part meeting the spec | no
18 | 1 | J1 | Connector | Wire pads for 12 V input pigtail | (PCB pads) | - | pads | see BOM_mechanical.csv for the pigtail | - | no
19 | 1 | J2 | Connector | Wire pads for CR2032 holder | (PCB pads) | - | pads | see BOM_mechanical.csv for the holder | - | no
20 | 1 | RS3 | Resistor | 22 kOhm 0805: HV sense bottom (NOT an anode resistor) | generic | - | 0805 | 1 %, >=0.125 W, >=50 V | any part meeting the spec | no
21 | 1 | RV1 | Resistor | 47 kOhm 0805: VIN sense top | generic | - | 0805 | 1 %, >=0.125 W, >=50 V | any part meeting the spec | no
22 | 11 | RV2 RB1 RC1 RB2 RC2 RB3 RC3 RB4 RD1 RB6 RB5 | Resistor | 10 kOhm 0805 | generic | - | 0805 | 1 %, >=0.125 W, >=50 V | any part meeting the spec | no
23 | 7 | RPD1 RPD2 RPD3 RPD4 RPU5 RPD5 RGP | Resistor | 100 kOhm 0805: default-off pull-ups/pull-downs | generic | - | 0805 | 1 %, >=0.125 W, >=50 V | any part meeting the spec | no
24 | 2 | RI1 RI2 | Resistor | 4.7 kOhm 0805: I2C pull-ups | generic | - | 0805 | 1 %, >=0.125 W, >=50 V | any part meeting the spec | no
25 | 3 | C1 C2 C8 | Capacitor | 100 nF 0805 decoupling | generic | - | 0805 | X7R, >=25 V | any part meeting the spec | no
26 | 2 | C3 C4 | Capacitor | 10 uF 0805 driver bulk | generic | - | 0805 | X5R/X7R, >=25 V (check capacitance at 12 V bias) | any part meeting the spec | no
27 | 1 | C7 | Capacitor | 10 nF 0805 HV-sense filter | generic | - | 0805 | X7R, >=25 V | any part meeting the spec | no
28 | 1 | C6 | Capacitor | 10 uF 1210 converter input | generic | - | 1210 | X5R/X7R, >=25 V | any part meeting the spec | no
29 | 1 | C5 | Capacitor | 47 uF electrolytic, 12 V input bulk | generic | - | radial <=6.3x8 mm, 2.5 mm pitch | 25 V, 105 C | any part meeting the spec | no

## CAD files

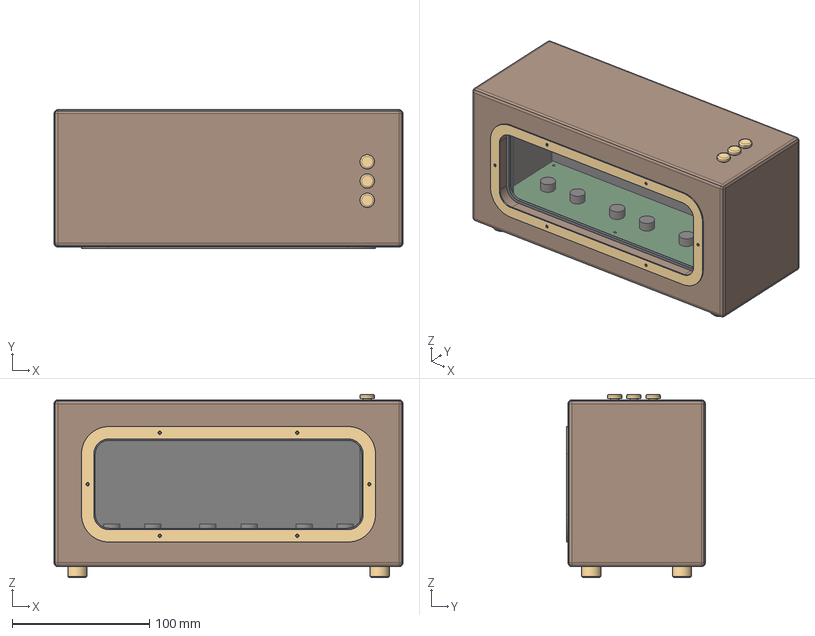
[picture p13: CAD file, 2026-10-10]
cad/Assembly_RevC_heirloom.step
254.0 x 101.0 x 133.5 mm
01_inner_case
02_floor
03_cable_clamp
04_button_rod_SET
04_button_rod_H
04_button_rod_M
05_window_panel
08_wood_front
09_wood_back
10_wood_end_left
11_wood_end_right
12_wood_top
13_brass_bezel
14_brass_foot_1
14_brass_foot_2
14_brass_foot_3
14_brass_foot_4
PCB
glass_1
spacer_1
glass_2
spacer_2
glass_3
spacer_3
glass_4
spacer_4
glass_5
spacer_5
glass_6
spacer_6
lamp_1
lamp_2
button_SET
button_H
button_M

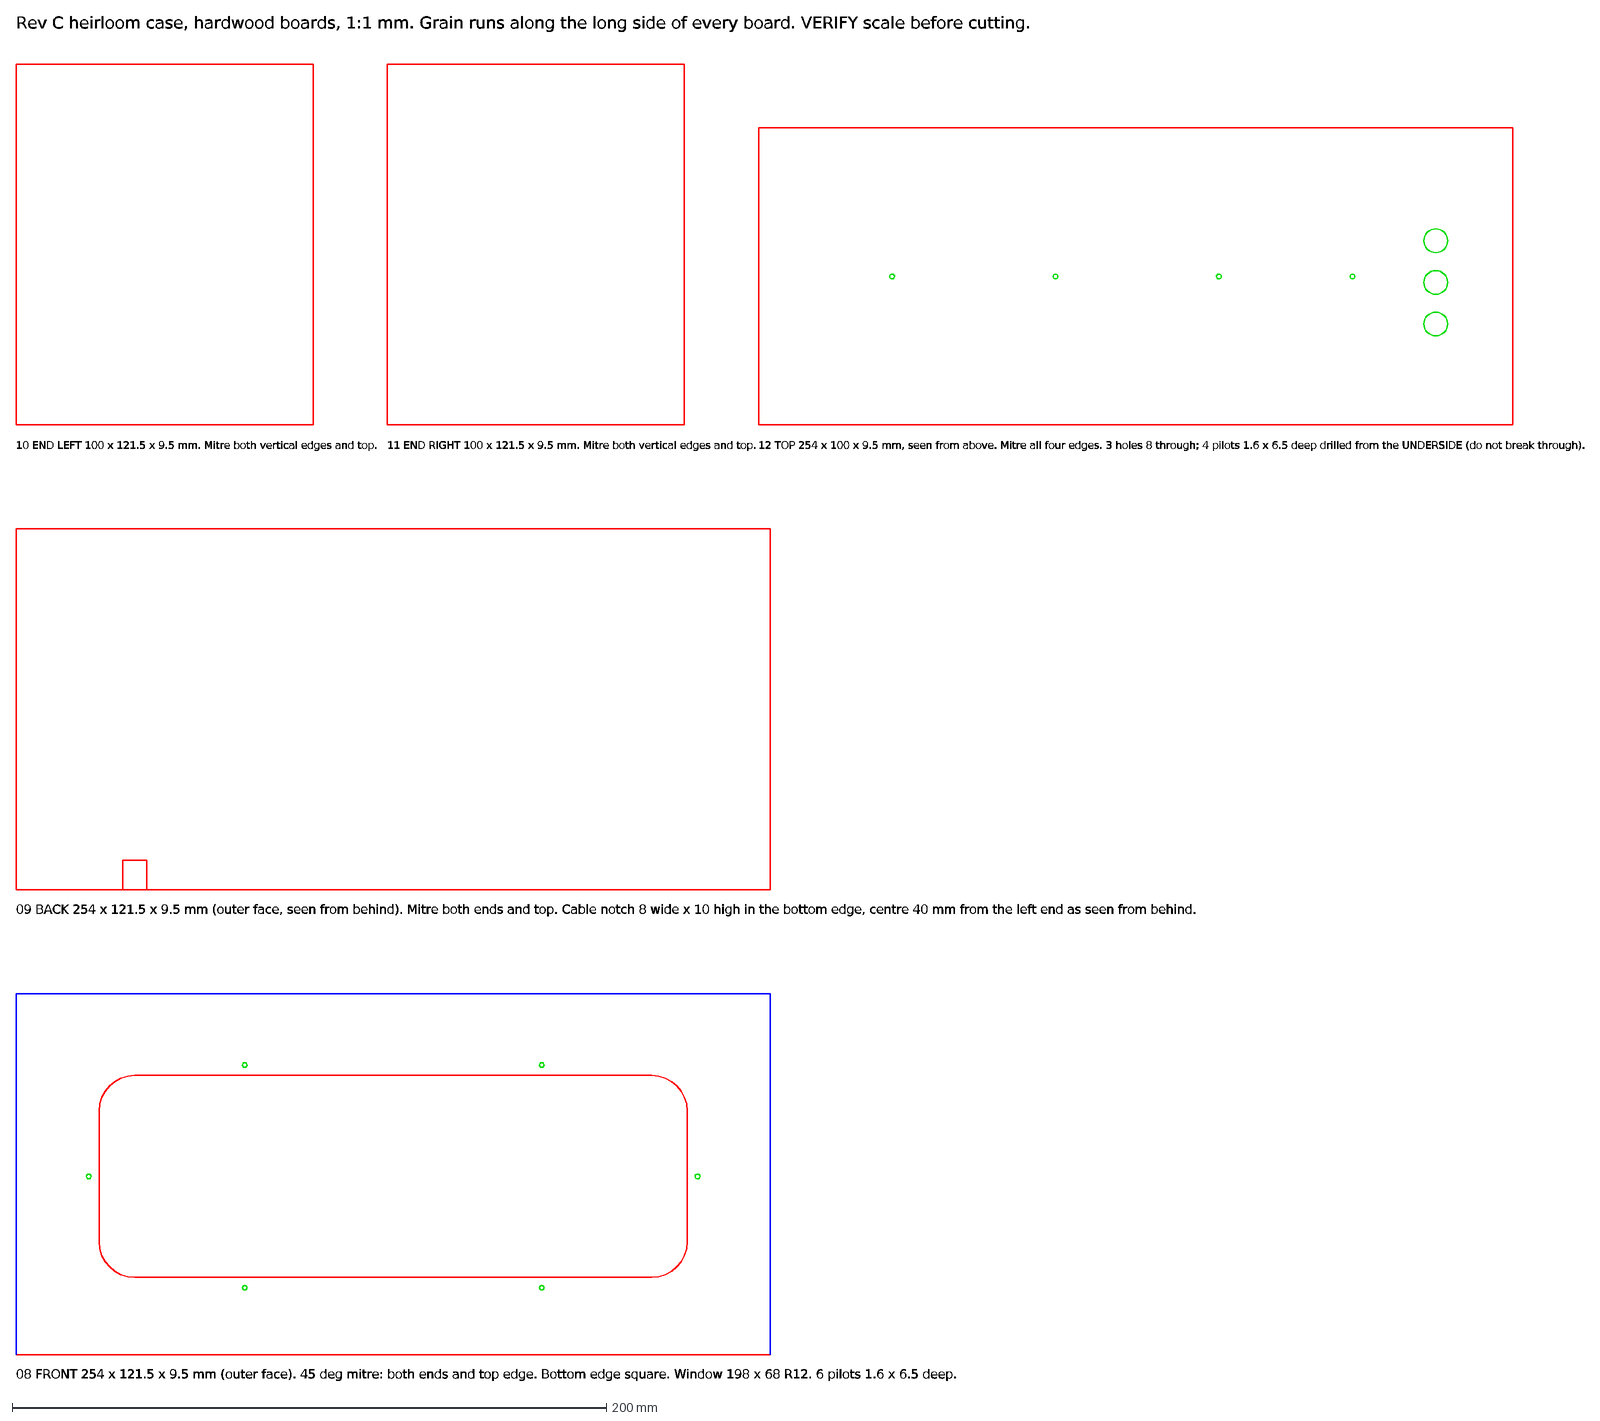
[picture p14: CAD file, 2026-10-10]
cad/dxf/Wood_boards_1to1.dxf
08 FRONT 254 x 121.5 x 9.5 mm (outer face). 45 deg mitre: both ends and top edge. Bottom edge square. Window 198 x 68 R12. 6 pilots 1.6 x 6.5 deep.
09 BACK 254 x 121.5 x 9.5 mm (outer face, seen from behind). Mitre both ends and top. Cable notch 8 wide x 10 high in the bottom edge, centre 40 mm from the lef
10 END LEFT 100 x 121.5 x 9.5 mm. Mitre both vertical edges and top.
11 END RIGHT 100 x 121.5 x 9.5 mm. Mitre both vertical edges and top.
12 TOP 254 x 100 x 9.5 mm, seen from above. Mitre all four edges. 3 holes 8 through; 4 pilots 1.6 x 6.5 deep drilled from the UNDERSIDE (do not break through).
Rev C heirloom case, hardwood boards, 1:1 mm. Grain runs along the long side of every board. VERIFY scale before cutting.

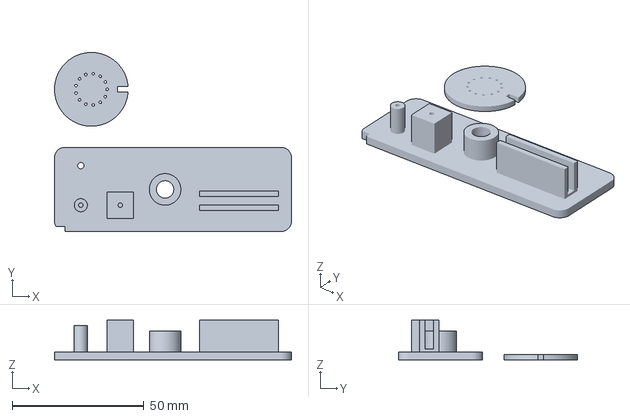
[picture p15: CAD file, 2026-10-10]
cad/print/plate_0_fit_coupons.3mf
90.0 x 68.0 x 15.0 mm

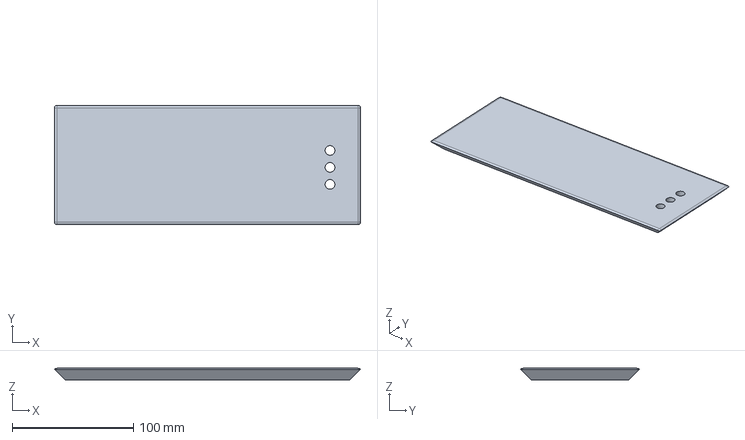
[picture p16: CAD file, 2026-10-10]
cad/step/12_wood_top.step
252.2 x 98.2 x 9.50 mm

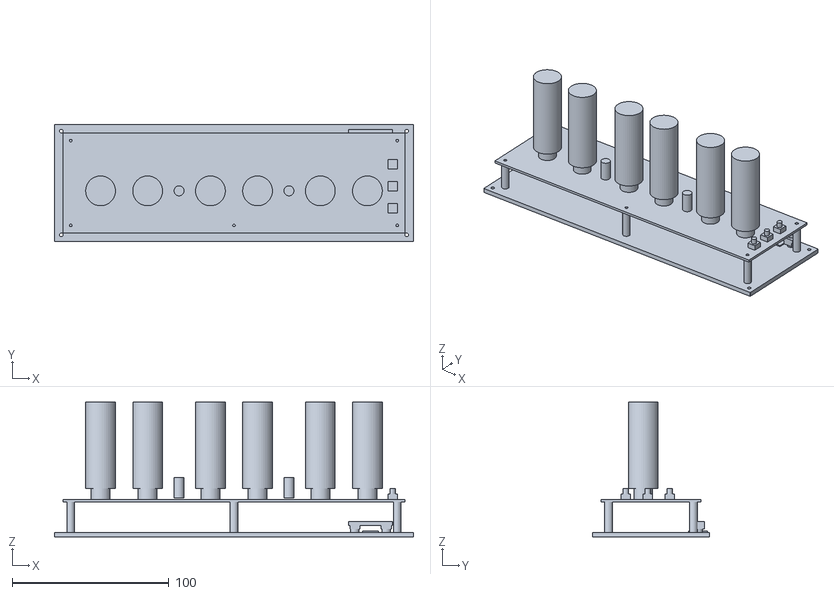
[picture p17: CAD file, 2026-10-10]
cad/view/Chassis_RevC_case_removed_VIEW_ONLY.stl
228.7 x 74.7 x 86.0

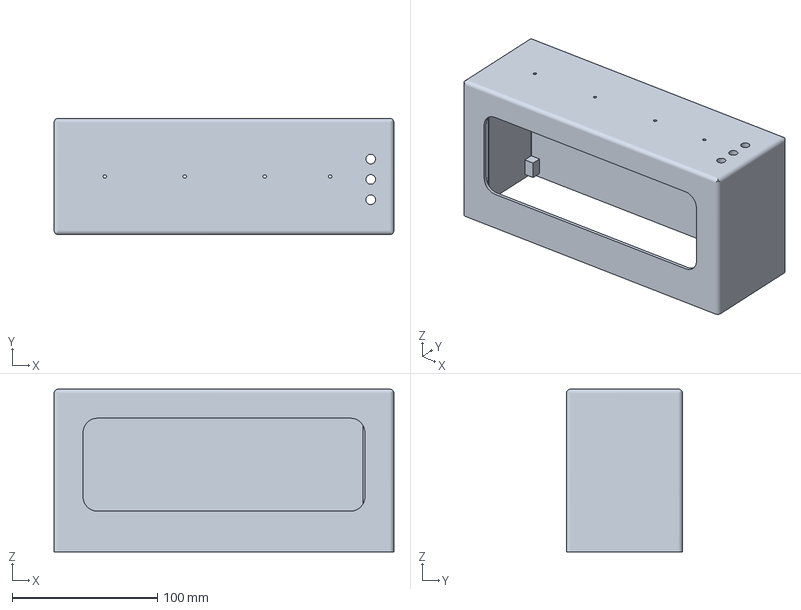
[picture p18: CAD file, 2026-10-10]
site/downloads/plate_A_inner_case.3mf
234.0 x 80.0 x 112.0 mm

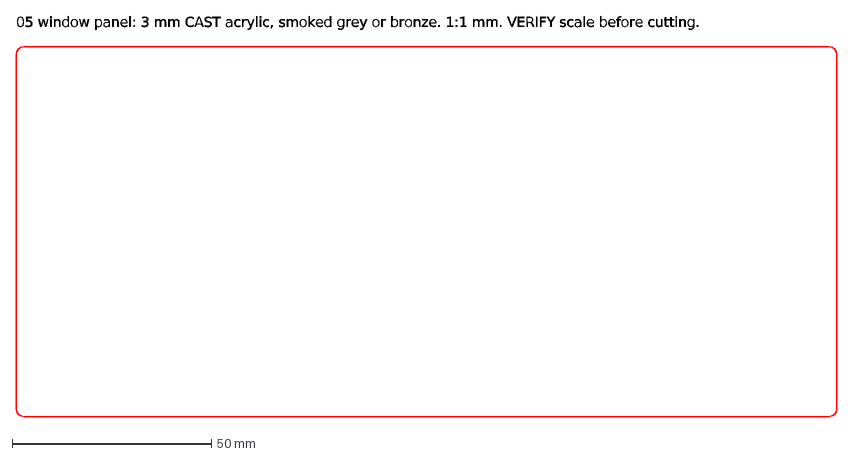
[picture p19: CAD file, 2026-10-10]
cad/dxf/Window_panel_3mm_1to1.dxf
05 window panel: 3 mm CAST acrylic, smoked grey or bronze. 1:1 mm. VERIFY scale before cutting.

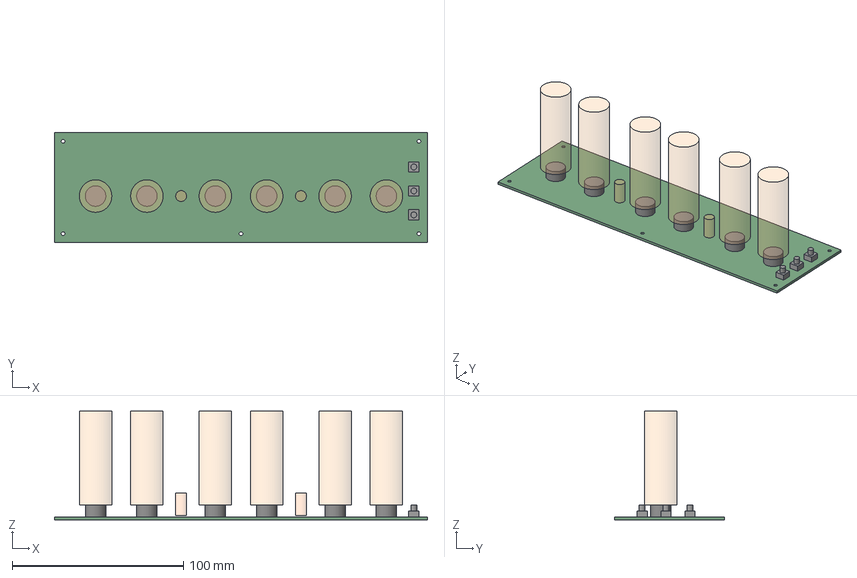
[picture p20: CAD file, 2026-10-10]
cad/PCB_mechanical_RevC.step
218.0 x 64.0 x 63.6 mm
PCB
glass_1
spacer_1
glass_2
spacer_2
glass_3
spacer_3
glass_4
spacer_4
glass_5
spacer_5
glass_6
spacer_6
lamp_1
lamp_2
button_SET
button_H
button_M

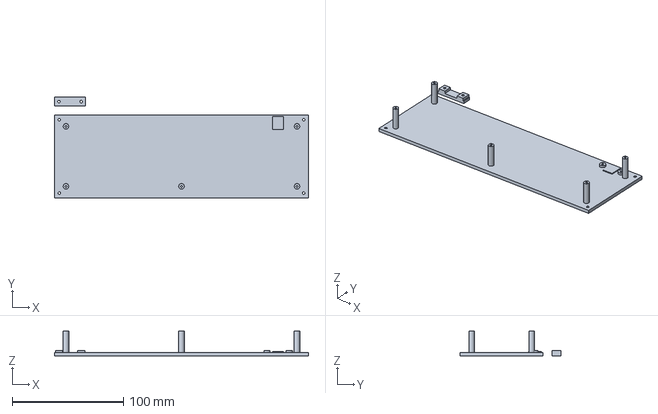
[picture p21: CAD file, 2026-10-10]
cad/print/plate_B_floor_clamp.3mf
228.7 x 90.7 x 22.4 mm

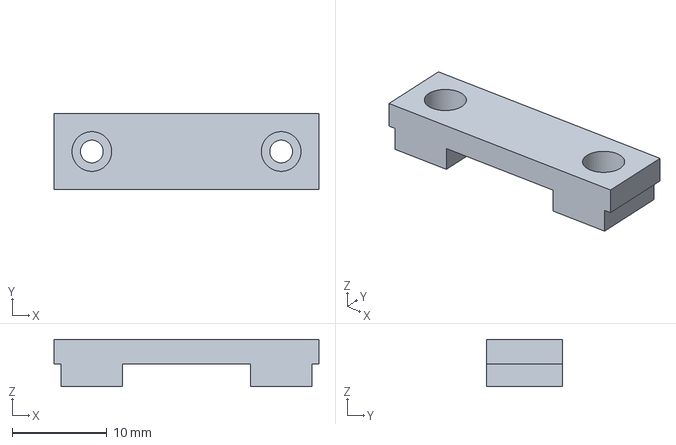
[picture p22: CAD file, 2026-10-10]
cad/step/03_cable_clamp.step
28.0 x 8.00 x 5.00 mm

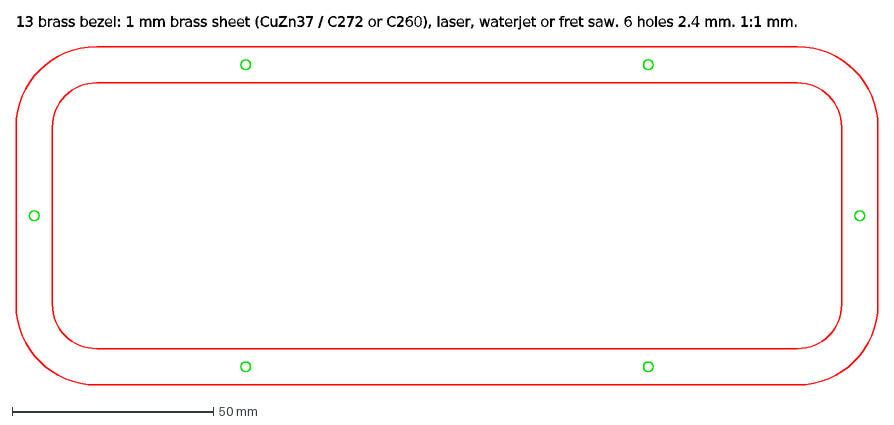
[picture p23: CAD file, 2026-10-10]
cad/dxf/Brass_bezel_1mm_1to1.dxf
13 brass bezel: 1 mm brass sheet (CuZn37 / C272 or C260), laser, waterjet or fret saw. 6 holes 2.4 mm. 1:1 mm.

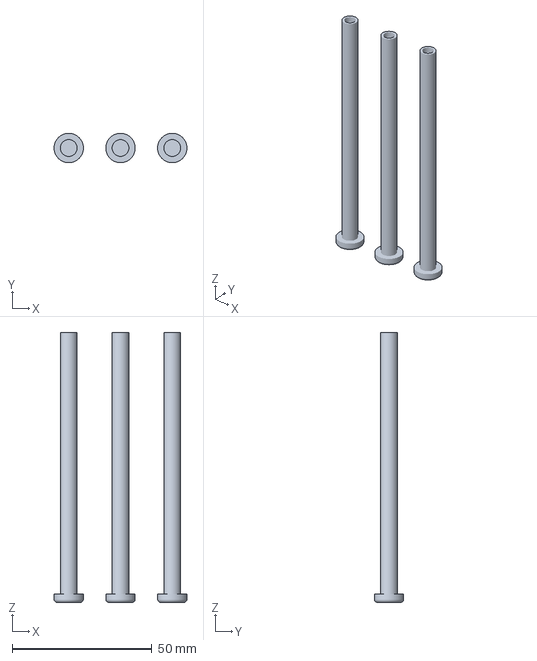
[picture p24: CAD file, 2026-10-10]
cad/print/plate_C_button_rods_silk_brass.3mf
47.5 x 10.5 x 96.5 mm

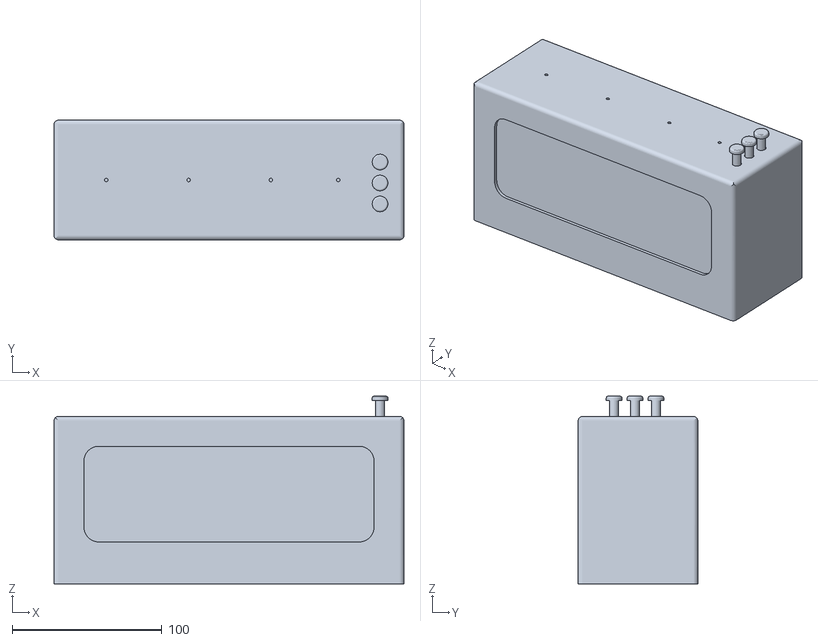
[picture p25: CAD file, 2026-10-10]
cad/view/Inner_case_printed_edition_VIEW_ONLY.stl
234.0 x 80.0 x 125.5

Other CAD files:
cad/view/Assembly_RevC_heirloom_VIEW_ONLY.stl
cad/step/01_inner_case.step
cad/3mf/01_inner_case.3mf
cad/3mf/02_floor.3mf
cad/3mf/03_cable_clamp.3mf
cad/3mf/04_button_rod.3mf
cad/3mf/06_fit_coupon.3mf
cad/3mf/07_unpowered_lead_pattern_coupon.3mf
cad/3mf/14_brass_foot.3mf
cad/Window_panel_3mm_1to1.dxf
cad/step/02_floor.step
cad/step/04_button_rod.step
cad/step/05_window_panel_3mm_acrylic.step
cad/step/06_fit_coupon.step
cad/step/07_unpowered_lead_pattern_coupon.step
cad/step/08_wood_front.step
cad/step/09_wood_back.step
cad/step/10_wood_end_left.step
cad/step/11_wood_end_right.step
cad/step/13_brass_bezel_1mm.step
cad/step/14_brass_foot.step
cad/stl/01_inner_case.stl
cad/stl/02_floor.stl
cad/stl/03_cable_clamp.stl
cad/stl/04_button_rod.stl
cad/stl/06_fit_coupon.stl
cad/stl/07_unpowered_lead_pattern_coupon.stl
cad/stl/14_brass_foot.stl
site/downloads/Window_panel_3mm_1to1.dxf

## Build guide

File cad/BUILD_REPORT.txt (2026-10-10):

Generated by source/build_cad.py from cad/DIMENSIONS.json
01_inner_case                        print bbox  234.0 x  80.0 x 112.0 mm  volume  207.1 cm3
02_floor                             print bbox  228.7 x  74.7 x  22.4 mm  volume   53.2 cm3
03_cable_clamp                       print bbox   28.0 x   8.0 x   5.0 mm  volume    0.7 cm3
04_button_rod                        print bbox   10.5 x  10.5 x  96.5 mm  volume    2.9 cm3
05_window_panel_3mm_acrylic          made, not printed: bbox  206.0 x   3.0 x  92.8 mm  volume   57.3 cm3
06_fit_coupon                        print bbox   90.0 x  32.0 x  15.0 mm  volume   12.0 cm3
07_unpowered_lead_pattern_coupon     print bbox   28.0 x  28.0 x   2.0 mm  volume    1.2 cm3
08_wood_front                        made, not printed: bbox  252.2 x   9.5 x 120.6 mm  volume  143.5 cm3
09_wood_back                         made, not printed: bbox  252.2 x   9.5 x 120.6 mm  volume  269.7 cm3
10_wood_end_left                     made, not printed: bbox    9.5 x  98.2 x 120.6 mm  volume  100.0 cm3
11_wood_end_right                    made, not printed: bbox    9.5 x  98.2 x 120.6 mm  volume  100.0 cm3
12_wood_top                          made, not printed: bbox  252.2 x  98.2 x   9.5 mm  volume  208.3 cm3
13_brass_bezel_1mm                   made, not printed: bbox  214.0 x   1.0 x  84.0 mm  volume    4.8 cm3
14_brass_foot                        print bbox   14.0 x  14.0 x   8.0 mm  volume    1.2 cm3
hardwood box total 822 cm3, about 526 g in walnut; outer 254 x 100 x 121.5 mm, 129.5 mm tall on its feet
dxf/Window_panel_3mm_1to1.dxf        sheet 206.0 x 92.8 mm
dxf/Brass_bezel_1mm_1to1.dxf         sheet 214.0 x 84.0 mm
dxf/Wood_boards_1to1.dxf             sheet 504.0 x 434.5 mm

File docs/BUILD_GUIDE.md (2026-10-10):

# Build guide (Rev C)

This is the spine of the project. Every stage lists the **parts**, the **steps**, the **measurements** to record, and an explicit **PASS / FIX / STOP** decision. Record every measurement in [VALIDATION.md](VALIDATION.md) as you go; that file is how the next builder learns what actually worked.

> **Read [SAFETY.md](SAFETY.md) first.** Stages 3 onward involve about 170 V DC. There is a safety gate before anything high-voltage, and the discharge gate is never skipped.

**Words used here.** *HV* = high voltage, the ~170 V rail (`HV170`). *LV* = low voltage, the 12 V and 5 V parts. *Shunt* = the little jumper cap on JP1 (HV_ARM). *RTC* = real-time clock (the DS3231). *PCB* = printed circuit board. *DMM* = digital multimeter. *IDE* = integrated development environment (the Arduino app). *USB* = Universal Serial Bus. *I²C* = Inter-Integrated Circuit, the two-wire bus to the RTC. *VIN* = the Nano's input-voltage pin. *CAT II* = the meter's measurement category rating. *PETG* = polyethylene terephthalate glycol, the printing plastic.

## Before you start: what exists and what does not

Rev C is an **unvalidated engineering prototype**. The repository has the net map, a generated KiCad schematic, a placement-only board, firmware and enclosure models. It does **not** yet have a routed board or Gerber files. Someone must:

1. Open `hardware/Nixie_RevC.kicad_pro` in KiCad, redraw the generated schematic into readable form, pick or draw real footprints, and run **native ERC** (electrical rules check).
2. Route the 4-layer board with the HV rules in `hardware/Nixie_RevC.kicad_dru` and run **native DRC** (design rules check).
3. Have the HV layout reviewed by someone experienced, then generate Gerbers and drill files.

Only after that does Stage 1 have a board to populate. Stages 0 and the firmware parts of Stage 2 can be done today.

**Tools:** temperature-controlled soldering iron, flux, DMM rated CAT II 600 V or better with clip leads, bench supply with adjustable current limit (for Stages 1–3), USB Mini-B data cable, M2 tap and holder, calipers, safety glasses.

**The enclosure** is a fully enclosed heirloom case: a printed black **inner case** carries every functional feature (window slot, button guides, floor-screw blocks), and a mitred **walnut box** with a brass bezel slips over it, held by four screws into its top board. The tubes stand inside, seen through a smoked acrylic window; SET, H and M are pressed from the top through brass-coloured rods. The PCB screws onto five standoffs on the printed floor, making a **chassis** you can work on by itself; the case lowers over it at the end and four brass feet screw it shut. M2 screws only ([BOM.md](BOM.md#m2-fasteners)). The inner case alone is a complete enclosure, so you can build and test everything before the woodwork is done.

Exploded view

---

## Stage 0: fit coupons and M2 threads (no electronics)

**Parts:** PETG, `cad/print/plate_0_fit_coupons.3mf` (parts 06 and 07), one IN-14 tube, one printed button rod (part 04), a 25 mm offcut of your 3 mm acrylic, a scrap of 1.6 mm board, an offcut of your 9.5 mm hardwood, M2 × 6 (steel and brass) and M2 × 8 screws, M2 tap, 1.6 mm drill.

**Steps**
1. Print the coupons with the baseline settings in [PRINTING.md](PRINTING.md).
2. Coupon 06: slide the acrylic offcut into the 3.3 mm slot (it must go in without force and not rattle), and slide a button rod through the guide (it must drop freely under its own weight).
3. Tap the two 1.7 mm pilot holes with an M2 tap, backing out every half-turn. Drive an M2 × 6 through the board scrap into the standoff, and an M2 × 8 into the tall block. Snug, then back out.
4. Hardwood offcut: drill a 1.6 mm pilot 6.5 mm deep, drive a **steel** M2 × 6 first to cut the thread, back it out, wax a **brass** M2 × 6 and drive it in. Brass screws are soft and snap easily in walnut; this is how the six bezel screws go in.
5. Coupon 07 (**never powered**, never used as a tube spacer): try your tube's 13 leads against the hole pattern. The pattern in `cad/DIMENSIONS.json` (13 × Ø1.0 mm on a 12.0 mm circle) is a placeholder; measure your tube's actual lead circle with calipers and update `in14_lead_circle_d`.

**Measure:** glass diameter and height of each of your six tubes (spacer plus glass must stay under 80 mm above the board; nominal is 62 mm); acrylic thickness; thread engagement (turns before snug); the real lead circle diameter.

- **PASS:** acrylic slides in, rod drops freely, screws bite firmly and do not strip, the brass screw seats without twisting off.
- **FIX:** a tight hole → change the value in `cad/DIMENSIONS.json` and rerun `scripts/render_cad`. **Never scale a whole part** in the slicer to fix a hole. Stripped threads → try 1.6 mm pilots. Brass screw twists → 1.7 mm pilot in the wood.
- **STOP:** your tubes are taller than the case allows (they would touch the roof).

---

## Woodwork and brass (no electronics, any time)

Follow **[WOODWORK.md](WOODWORK.md)**: cut the five mitred boards from `cad/dxf/Wood_boards_1to1.dxf`, glue them into a box with the tape-hinge method (the printed inner case, wrapped in cling film, is the form), round the outer edges, oil, then fit the brass bezel. Make or print the four brass feet (part 14).

Woodwork: five mitred boards and the brass bezel

**Measure:** outer size of the box; the gap between the box and the printed inner case on each side; whether the top board sits flat on the inner-case roof.

- **PASS:** the box slips over the inner case by hand with a small, even gap (about 0.5 mm a side); the four M2 × 8 roof screws pull the top board down flat; the bezel lies flat with all six brass screws seated; the rods move freely through the 8 mm holes in the top.
- **FIX:** box too tight → sand the inside faces (never the inner case). Open mitre → fill with glue and sanding dust, sand flush. Rod rubs the wood → open the hole to 8.5 mm.
- **STOP:** the box only goes on by force (it would crack at a mitre in winter); any wood touching the window panel.

---

## Stage 1: low-voltage section (no HV parts powered)

**Parts:** the bare Rev C PCB, F1, QP1, C5, C1–C4, U1, U2, U3 and its passives, all level-shifter parts (QL1–QL5, RB1–RB4, RB6, RPD1–RPD4, RC1–RC3, RD1, RPU5), the HV-enable parts that are still low voltage (QE1, RB5, RPD5, QP2, RGP, C6, the JP1 header), RV1, RV2, RI1, RI2, C7, C8, Nano headers, J1 pigtail, J2 battery holder.

**Do not fit yet:** PS1, the JP1 shunt, tubes, lamps, anode and lamp resistors, bleeders, sense divider (RS1–RS3), CHV.

**Steps**
1. Inspect the bare board under magnification: no bridges, no copper slivers near the HV area.
2. Solder surface-mount parts smallest first, then the Nano headers and the pigtail. Clamp the pigtail so it does not pull on the pads.
3. Clean off flux. Inspect every joint.
4. With nothing powered, measure resistance TP2 → TP1 and TP3 → TP1. Neither should be a short.
5. Bench supply at 12.0 V, **current limit 100 mA**, into J1. Nano **not** plugged in yet.

**Measure:** TP2 (V12), supply current; then reverse the leads briefly and confirm almost zero current (QP1 blocking).

- **PASS:** TP2 = 11.8–12.0 V, current a few milliamps; reversed polarity draws nothing and nothing warms.
- **FIX:** low V12 → check QP1 orientation and F1. Current at the limit → look for a short near C5/C6 or the drivers.
- **STOP:** anything gets hot, or the supply sits in current limit.

Then plug in the Nano (not yet programmed) and repeat: TP3 (V5) should be 4.9–5.1 V.

---

## Stage 2: logic and RTC bring-up (no converter fitted)

**Parts:** Nano on its headers, CR2032 in its holder, USB data cable, the JP1 shunt. PS1 is **not** fitted yet, so nothing on the board can make high voltage in this stage. That is why the shunt can go in here: it lets you test the HV switch QP2 with nothing behind it.

**Steps**
1. Install the Arduino IDE and "Arduino AVR Boards". Board: *Arduino Nano*; processor: *ATmega328P* (try *Old Bootloader* if upload fails). Open `firmware/Nixie_RevC/Nixie_RevC.ino` and upload. Record the IDE, core and compiler versions in VALIDATION.md.
2. Serial monitor at 115200 baud, line ending *Newline*. You should see `Nixie Rev C (UNVALIDATED PROTOTYPE FIRMWARE)` and `RTC time invalid ... display stays OFF`.
3. Type `T 12:34:00`. Expect `OK time set`. Type `STATUS`.
4. Fit the shunt. Apply 12 V (bench supply, 150 mA limit). With a valid time the firmware switches QP2 on, sees no high voltage (PS1 is not fitted) and reports `HV did not reach 150 V ...` and `HV FAULT latched in EEPROM`. **That is the expected result**: it proves the start check works. Press the Nano's reset button: it must print `HV FAULT is latched from before the reset` and keep HV off. Then send `HVOFF` followed by `CLEARFAULT` (in that order, so it does not immediately try again).
5. Buttons: `STATUS` shows `buttons SET/H/M 000`; hold each switch and repeat, expecting a `1` in its place.
6. Battery backup: note the time, remove 12 V and USB for five minutes, restore power, `STATUS`. Time must have kept running.
7. HV switch check (shunt fitted, 12 V on): hold the Nano in reset (keep its reset button pressed) and measure `HV_IN_12V` (QP2 drain, the PS1 VIN pad): it must be about 0 V, and `HV_GATE` must equal `HV_ARMED_12V` (about 12 V). With `HVOFF` in force, `HV_IN_12V` must again be about 0 V. Send `RUN` only when you want HV requested again.
8. Logic check with a scope or logic analyser (optional, recommended): probe `DRV_CLK`, `DRV_DIN`, `DRV_LE` and `DRV_BL` at the drivers. Swings should be about 0 V to 12 V. With the Nano held in reset, `DRV_BL` must read LOW.
9. Remove the shunt again before Stage 3.

**Measure:** VIN reading in `STATUS` vs DMM on TP2; backup result; `HV_IN_12V` in reset and after `HVOFF`; `HV_IN_12V` during the start attempt (about 12 V); driver-side logic levels; `DRV_BL` during reset.

- **PASS:** time set and retained, buttons read, fault survives a reset until `CLEARFAULT`, `HV_IN_12V` about 0 V whenever HV is not requested, `DRV_BL` LOW in reset, logic swings 0–12 V.
- **FIX:** `RTC read failed` → check I²C pull-ups and U3 orientation. Wrong VIN reading → check RV1/RV2.
- **STOP:** `DRV_BL` is HIGH while the Nano is in reset, `HV_IN_12V` is above about 1 V when HV is not requested, or a fault does not survive a reset. The blanking, HV-enable or fault-latch default is broken; do not continue to Stage 3.

---

## SAFETY GATE before Stage 3

All of these must be true. Write the date and the reviewer's name in VALIDATION.md.

- [ ] Stages 0–2 passed and are recorded.
- [ ] An experienced HV reviewer has inspected the populated board, the HV area, the planned test setup and this guide.
- [ ] Meter: CAT II 600 V or better, black lead clipped to TP1, discharge tool (≥10 kΩ, ≥5 W, insulated) within reach.
- [ ] Bench supply with current limit available; the board sits on an insulated surface behind a clear barrier; meter leads and USB are connected before power; no one else touches it.
- [ ] You will not leave it energised unattended, and you know the stop conditions in [SAFETY.md](SAFETY.md#stop-conditions-any-of-these-ends-the-session-until-fixed).

---

## Stage 3: HV stage (guarded)

**Parts:** PS1 NCH8200HV, CHV, RH1, RH2, RS1, RS2, RS3. **Still no tubes, lamps or anode resistors.**

**Steps**
1. With everything unplugged, fit PS1, CHV, the bleeders and the sense divider. Clean and inspect; check the HV area for flux and solder balls.
2. Screw the board onto the floor standoffs (5 × M2 × 6) so it becomes the chassis. Bench supply 12.0 V, current limit **300 mA**. Guarded bench setup from [SAFETY.md](SAFETY.md) rule 4: chassis without its case, on an insulated surface behind a clear barrier. Connect USB and open the serial monitor, and clip the meter to TP4/TP1, all **before** applying power.
3. Insert the HV_ARM shunt (power off). Apply 12 V. The firmware starts HV if the time is valid. Expect `HV up: ~170 V`.
4. Read TP4 on the meter. Compare with the firmware's `HV sense` in `STATUS`.
5. Send `HVOFF`. Watch the meter fall. The firmware should report `HV decayed to ...` after 3 s.
6. Unplug 12 V. Wait 60 s. Confirm TP4 below 10 V. **This is the discharge gate.**

**Measure:** TP4 running; firmware HV reading; supply current with HV on (no load); TP4 at 1 s, 5 s and 60 s after `HVOFF`; time to fall below 10 V.

- **PASS:** TP4 = 165–175 V; firmware within about 5 % of the meter; TP4 below 10 V within a few seconds and well below by 60 s.
- **FIX:** firmware reading off by a steady percentage → note it; the Nano's 5 V reference is the usual cause.
- **STOP:** TP4 above 190 V; supply in current limit; TP4 not falling after `HVOFF` or not below 10 V at 60 s (suspect RH1/RH2 or the solder joints); any heat or smell at PS1.

---

## Stage 4: light one digit, then all six tubes and both lamps

**Parts:** T1–T6 with factory spacers, RA1–RA6, L1, L2, RL1, RL2, sleeving.

**Steps**
1. Discharge gate (unplug, 60 s, TP4 below 10 V). Remove the shunt.
2. Fit **T1 only** and RA1. This stage uses the same guarded bench setup as Stage 3 (chassis without its case, barrier, leads and USB connected before power). Tubes are direct-solder: keep the factory spacers, seat the tube square, solder the leads, and never bend them at the glass seal.
3. Fit the shunt (power off), then power up. Use `EXERCISE` or set the time so T1 shows each digit. Confirm the digit that lights is the one intended: this is the real test of the bit order, `kOutReversed`, and the latch and clock timing.
4. Measure the current of each digit. Two methods, chosen with your reviewer: (a) with power off and the rail discharged, lift one end of RA1 and clip the DMM in its mA range into the gap before powering up; or (b) clip DMM leads across RA1 before powering up, read the voltage, and divide by 22 kΩ. Never move probes while 12 V is on.
5. Discharge gate. Fit the remaining tubes, anode resistors, lamps (leads sleeved) and lamp resistors. Repeat the digit check for every tube and both separators.
6. With all six tubes lit, record the supply current and TP4.

**Measure:** per-digit current for every digit of every tube (60 values); lamp current; TP4 with all lit; 12 V supply current with all lit.

- **PASS:** each tube shows only the intended digit; currents close to the model (about 0.7–1.6 mA; see [EQUATIONS.md](EQUATIONS.md#1-tube-anode-current)); TP4 stays above 160 V with everything lit; supply current about 0.25 A.
- **FIX:** wrong digit lights → flip `kOutReversed` or correct the cathode wiring, and record which. Digits glow only partly → too little current; discuss changing RA with your reviewer (it raises the fault power) and record the change as a design change.
- **STOP:** two digits in one tube glow together; a separator lights when it should be off; TP4 sags below 150 V (the firmware will fault); anything hot.

---

## Stage 5: closed-case thermal run

**Steps:** close the heirloom case completely, wood box fitted (no USB: the port is inside), shunt fitted, all digits running, 25 °C room. The case has no vents on purpose (it keeps HV enclosed); the model predicts an average internal rise of only a few kelvin ([EQUATIONS.md](EQUATIONS.md#7-sealed-case-temperature)), and this stage checks the hot spots. Measure the 12 V current with an inline meter on the adapter side. Run for 2 hours, watching the tubes. Then unplug, pass the discharge gate, open, and immediately measure the Nano's regulator, PS1 and the anode resistors with a thermometer or thermal camera. Afterwards, connect USB (shunt out) and read `STATUS` for any fault.

**Measure:** temperatures, 12 V current at start and end, room temperature, time drift, any fault.

- **PASS:** regulator comfortably below its limit (record the value; below about 70 °C case temperature is a reasonable target), no part too hot to touch briefly, HV steady.
- **FIX:** hot regulator → the case may need baffled vents that do **not** expose HV; that is an enclosure design change. Do not run the clock with the wood box removed to cool it: the printed inner case is the HV enclosure, the wood is only cladding.
- **STOP:** any component discoloured or the case deformed.

---

## Stage 6: close the heirloom case

**Parts:** inner case (01) with the wood box screwed on (Woodwork above), window panel (05), three button rods (04), cable clamp (03), four brass feet (14), 4 × M2 × 16, clear silicone, four felt washers, two cable ties.

1. Discharge gate. Dress the pigtail through the rear opening, over the floor's cradle, and fix it with the cable clamp (2 × M2 × 6).
2. Case upside down on a soft cloth: slide the window panel up into its slot from the open bottom, film peeled on the inside face only. Put three small dots of silicone in the slot (both top corners and the middle of the top edge). Let it cure.
3. Turn the case upright and drop the three rods into the holes in the top, shaft first: they hang by their brass caps.
4. Fit the HV_ARM shunt (power off). Lower the case **straight down** over the chassis; the tubes go in without touching anything. Watch that each rod lands on its switch.
5. Lay the clock on its back on a cloth. At each corner, put an M2 × 16 through a brass foot (counterbore outward) and the floor, into the corner block. Snug, not tight. Add the felt washers. Peel the outer film from the window.
6. Check: nothing shows through any gap except the glowing digits; each cap clicks its switch and springs back.

- **PASS:** closed, rigid, buttons work, no exposed HV. **STOP:** any gap exposes HV, or a cap stays down.

**To open later:** unplug, wait 60 s, lay the clock on its back, remove the 4 screws through the brass feet, stand it up and lift the case (wood and inner case together) straight up. The window and rods stay in the case. Measure TP4 to TP1 (top side, rear edge) below 10 V before touching anything else; the HV_ARM shunt is next to them.

---

## Stage 7: close the loop

1. Fill in VALIDATION.md: every measurement, every deviation, every FIX you made, and who reviewed Stage 3.
2. If you changed a value, update `cad/DIMENSIONS.json` or `scripts/make_design_tables.py`, rerun the generators and tests, and commit.
3. Only claim what you actually measured. "Worked on my bench" is a data point, not a validation.

**Never skip the discharge gate.**

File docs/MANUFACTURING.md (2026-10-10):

# Manufacturing package (Rev C)

Everything needed to make a Rev C clock from open files, in the order you would do it. **One step is blocked:** the printed circuit board (PCB) has not been routed yet, so there are no Gerber files. Everything else can be made today.

What to make, with which file, and what is ready

| Process | Files | Status |
|---|---|---|
| Buy parts | [`hardware/BOM.csv`](../hardware/BOM.csv) (electrical, 29 lines, 71 parts) · [`hardware/BOM_mechanical.csv`](../hardware/BOM_mechanical.csv) · readable version: [BOM.md](BOM.md) | Ready |
| 3D print | `cad/print/*.3mf` plates, or single parts in `cad/stl/` and `cad/3mf/` · [PRINTING.md](PRINTING.md) | Ready (fit unverified: print coupons first) |
| Laser / waterjet cut | [`cad/dxf/Window_panel_3mm_1to1.dxf`](../cad/dxf/Window_panel_3mm_1to1.dxf) (3 mm smoked cast acrylic, 206 × 92.8 mm) · [`cad/dxf/Brass_bezel_1mm_1to1.dxf`](../cad/dxf/Brass_bezel_1mm_1to1.dxf) (1 mm brass, 214 × 84 mm) | Ready |
| Woodwork | [`cad/dxf/Wood_boards_1to1.dxf`](../cad/dxf/Wood_boards_1to1.dxf), five 9.5 mm walnut boards, 45° mitres · [WOODWORK.md](WOODWORK.md) | Ready |
| Brass feet | [`cad/step/14_brass_foot.step`](../cad/step/14_brass_foot.step), four slices of 14 mm brass bar (or print in silk brass) | Ready |
| PCB fabrication | `hardware/` KiCad project → `scripts/make_fab_outputs.sh` | **Blocked**: board not routed; release gate below |
| PCB assembly | [BUILD_GUIDE.md](BUILD_GUIDE.md) Stages 1–4, `hardware/COMPONENT_PLACEMENT.csv` | Waits for the PCB |
| Wiring | Section 4 below, [WIRING.md](WIRING.md) | Ready |
| Firmware | `firmware/Nixie_RevC/build/Nixie_RevC.hex` or the `.ino` | Compiles (never run on a board) |
| Labels | [`docs/labels.pdf`](labels.pdf) (print at 100 %) | Ready |
| Test and record | [`hardware/TEST_RECORD.csv`](../hardware/TEST_RECORD.csv), [VALIDATION.md](VALIDATION.md) | Ready |

## 1. Buy parts

- Use `hardware/BOM.csv`. The `spec` column is the requirement; `substitution` says when a generic part is fine. **Lines marked `safety_critical = yes` must be bought at the stated rating or better**: the 1 W anode and lamp resistors, the ≥250 V high-voltage capacitor (CHV), the ≥200 V bleeder and sense resistors, the fuse, the P-channel transistors, the HV5522 drivers and the HV module.
- `hardware/BOM_mechanical.csv` lists the heirloom case (printed, cut, wood and brass parts), fasteners and off-board items. M2 only: 4 × M2 × 16, 4 × M2 × 8, 7 × M2 × 6, 6 × M2 × 6 brass.
- Buy integrated circuits from authorised distributors; buy tubes from sellers who test them.

## 2. 3D print, cut, woodwork

- Bambu Lab P1S (256 mm cube) or any printer with at least 240 × 85 mm of bed and 115 mm of height: the inner case is 234 × 80 × 112 mm.
- Black PETG, 0.20 mm layers, 4 walls, 5 top and bottom layers, 20–25 % infill. Only the inner case needs supports (automatic tree supports, inside under the roof and in the window opening). Print the button rods in silk brass. Details: [PRINTING.md](PRINTING.md).
- Print `plate_0_fit_coupons.3mf` first and check it against an acrylic offcut, a button rod, a hardwood offcut and M2 screws before printing anything large.
- Acrylic: cut the window DXF at 1:1 in millimetres from 3 mm **cast** acrylic, smoked grey or bronze; confirm 206 × 92.8 mm in the laser software first.
- Brass: send the bezel DXF to a laser or waterjet service (or fret-saw it from 1 mm sheet).
- Wood: five mitred boards from one 130 mm × 1.1 m walnut board, glued round the printed inner case as a form, oiled. Step by step in [WOODWORK.md](WOODWORK.md).

Exploded view

## 3. PCB fabrication (blocked until the release gate passes)

### What exists now

- Generated schematic (root sheet plus two driver sheets), checked net by net against `NET_MAP.csv` with KiCad's own netlist export.
- A placement-only board: 218 × 64 mm outline, five M2 holes and component courtyards, with 0 violations in KiCad's own design rules check (DRC). It has **no copper and no real footprints**.

PCB mechanical drawing

### What must happen before anyone orders boards

1. Replace the placeholder footprints with real ones, including the IN-14 lead pattern **measured from your tubes** and the NCH8200HV outline **measured from your module**.
2. Run KiCad's electrical rules check (ERC) on a readable schematic.
3. Route four layers with `hardware/Nixie_RevC.kicad_dru` and run DRC to 0 violations and 0 unconnected items.
4. Have an experienced high-voltage reviewer check the layout, then fill in [`hardware/REVIEW_SIGNOFF.md`](../hardware/REVIEW_SIGNOFF.md).
5. Run `scripts/make_fab_outputs.sh`. It checks all of the above and only then writes Gerbers, Excellon drill files, a placement file and the BOM into `fab/`, zipped with a SHA-256 checksum. Today it stops at step 1 on purpose.

### Board specification to send with the files (starting values: confirm with your fab)

| Item | Value |
|---|---|
| Size | 218 × 64 mm, 5 × Ø2.2 mm non-plated M2 holes (see drawing) |
| Layers | 4 |
| Thickness | 1.6 mm FR-4 (glass-epoxy), Tg ≥ 150 °C |
| Copper | 1 oz outer, 0.5 oz inner |
| Finish | ENIG (electroless nickel immersion gold): flat pads suit the 44-lead plastic leaded chip carrier (PLCC-44) drivers |
| Solder mask / silkscreen | Matte black (looks best through the smoked window; any colour works) / white |
| HV clearance | ≥1.0 mm between HV and low-voltage nets on every layer, ≥0.65 mm HV to HV, ≥2.0 mm HV to board edge (from `Nixie_RevC.kicad_dru`; check against IPC-2221B) |
| Top side | Only tubes, lamps, switches, the HV_ARM header and test pads TP1–TP4 (along the rear edge, for measuring with the case lifted off) |
| Electrical test | Request 100 % flying-probe test |

## 4. Wiring harness

| Wire | Spec | Route |
|---|---|---|
| 12 V input | Insulated pigtail, 5.5 × 2.1 mm female, about 150 mm, about 4 mm outer diameter | Rear 4.2 mm hole → floor cradle → cable clamp (part 03, 2 × M2 × 6) → J1 pads |
| Backup cell | Insulated CR2032 holder with leads | J2 pads; stick the holder to the floor away from the HV area |
| Neon lamps | NE-2 leads, sleeved ≥300 V (600 V preferred) over every exposed millimetre | L1, L2 positions |
| Dressing | 2 small cable ties | Keep every low-voltage wire away from PS1, the anode resistors and the tube leads |

## 5. Assembly

Follow [BUILD_GUIDE.md](BUILD_GUIDE.md) exactly. It is also the assembly procedure: low-voltage parts and the HV-enable switch first (Stage 1), logic and clock bring-up with no HV module fitted (Stage 2), the HV supply under guarded conditions (Stage 3), then one tube before all six (Stage 4). Never skip the discharge gate.

## 6. Programming

Arduino IDE (integrated development environment): open `firmware/Nixie_RevC/Nixie_RevC.ino`, board *Arduino Nano*, processor *ATmega328P*, Upload.

Or flash the prebuilt image with `avrdude` (no IDE). Check `firmware/Nixie_RevC/build/BUILD_INFO.txt` for its SHA-256 first, and follow the USB rules in [SAFETY.md](SAFETY.md#usb-the-shunt-and-the-serial-monitor):

```bash
sudo apt-get install -y avrdude
avrdude -p m328p -c arduino -P /dev/ttyUSB0 -b 115200 -D -U flash:w:firmware/Nixie_RevC/build/Nixie_RevC.hex:i   # use -b 57600 for the old bootloader
```

## 7. Test, label, record

- Record every unit in a copy of [`hardware/TEST_RECORD.csv`](../hardware/TEST_RECORD.csv) (one file per serial number). Any STOP result ends the build until it is fixed.
- Print [`docs/labels.pdf`](labels.pdf) at 100 % on vinyl sticker paper: the HV warning and rating plate go on the underside of the floor, the small 170 V markers inside the case near PS1 and TP4, and the HV_ARM tag next to JP1.

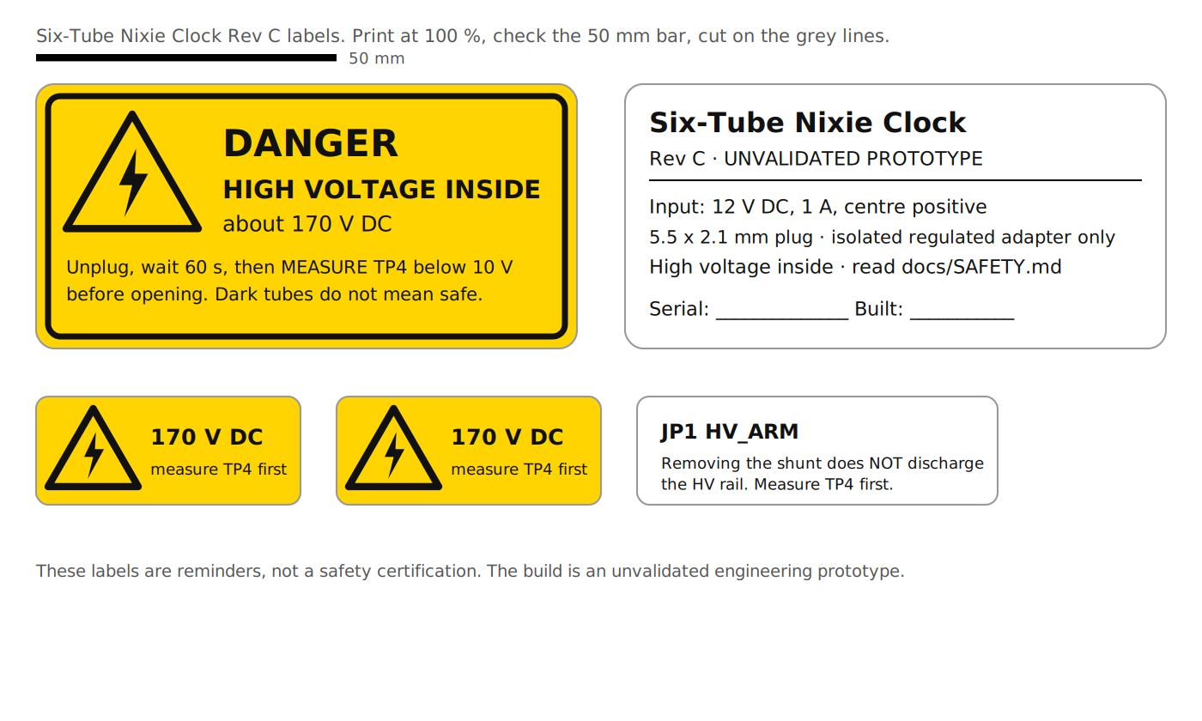
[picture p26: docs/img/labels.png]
Labels


- Fill in [VALIDATION.md](VALIDATION.md). Claim only what you measured.

## 8. Requirements and licence

- Every requirement, what satisfies it and how it is verified: [REQUIREMENTS.md](REQUIREMENTS.md).
- Everything in the repository is under the MIT licence. If you would prefer a licence written for hardware that keeps derivatives open, the CERN Open Hardware Licence (CERN-OHL-S) is the usual choice; changing it is the project owner's decision.

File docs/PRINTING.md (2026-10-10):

# Printing and cutting

Everything here is a **baseline, untested** starting point. Print the fit coupons first and adjust `cad/DIMENSIONS.json`, not the slicer scale. The wood and brass parts are in [WOODWORK.md](WOODWORK.md).

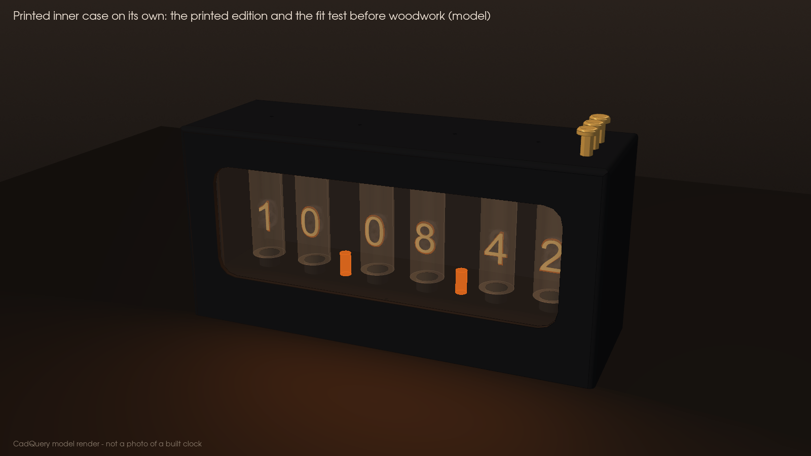
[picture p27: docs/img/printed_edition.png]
Printed inner case on its own, model render


The printed **inner case** is the real enclosure: it carries the window slot, the button guides, the light baffle and the floor-screw blocks, and it is what keeps the high voltage enclosed. On its own it is a complete, working case (the *printed edition*); the walnut box is cladding that slips over it.

## Which files to use

| Use | Files | Orientation |
|---|---|---|
| **Slice these** | `cad/stl/*.stl` or `cad/3mf/*.3mf`, or the ready plates in `cad/print/` | Print orientation, already on the bed |
| **Laser-cut these** | `cad/dxf/Window_panel_3mm_1to1.dxf` (acrylic) · `cad/dxf/Brass_bezel_1mm_1to1.dxf` (brass) | 2D, 1:1 millimetres |
| **Woodwork** | `cad/dxf/Wood_boards_1to1.dxf` · [WOODWORK.md](WOODWORK.md) | 2D outer faces, 1:1 |
| CAD reference only | `cad/step/*.step`, `cad/Assembly_RevC_heirloom.step` | Assembly coordinates: **do not slice** |
| View only | `cad/view/*.stl` (finished clock, printed edition, chassis) | Includes glass, PCB, wood and brass: **never print** |

## Parts and plates

| Plate | Parts | Notes |
|---|---|---|
| `plate_0_fit_coupons.3mf` | 06 fit coupon, 07 unpowered lead-pattern coupon | Print first, black PETG |
| `plate_A_inner_case.3mf` | 01 inner case (upright, open bottom on the bed) | 234 × 80 × 112 mm, black PETG; tree supports (see below) |
| `plate_B_floor_clamp.3mf` | 02 floor, 03 cable clamp | Black PETG, no supports |
| `plate_C_button_rods_silk_brass.3mf` | 3 × 04 button rods | **Silk brass** (or gold) filament, cap down, 5 mm brim, slow outer walls |
| (single part) | 14 brass foot × 4, only if you are not making them from brass bar | Silk brass, counterbore up |

Coupon 07 carries only the IN-14 lead pattern. **It is never a powered tube spacer.** Keep the factory spacers on your tubes.

Print the inner case in **matte black**: through the smoked window it reads as a dark cavity, so only the glowing digits show.

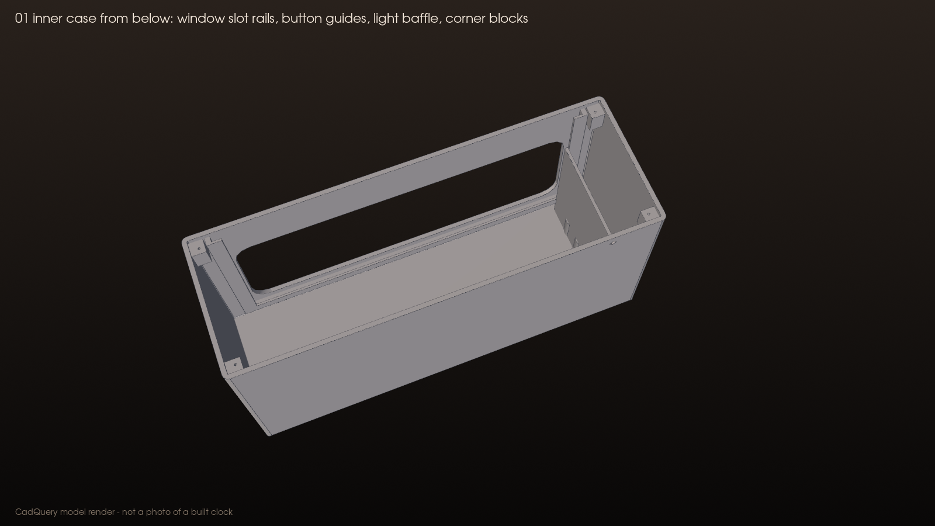
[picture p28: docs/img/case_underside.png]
Inner case from below: window slot rails, button guides, light baffle, corner blocks


## Printer

Every printed part fits a Bambu Lab P1S (256 × 256 × 256 mm). Any printer with at least 240 × 85 mm of bed and 115 mm of height works. The wood box (254 × 100 mm) is not printed.

## Baseline settings (PETG, matte)

| Setting | Value |
|---|---|
| Layer height | 0.20 mm |
| Walls | 4 |
| Top / bottom layers | 5 / 5 |
| Infill | 20–25 % (gyroid or grid) |
| Supports | **Inner case (01):** tree supports, automatic, with *on build plate only* turned **off**. They form inside under the roof, the three button guides and the baffle, and in the window opening; the outside needs none. **Everything else:** none |
| Brim | 5 mm on the inner case and the rods |
| Seam | Aligned at the back |

The rods are 96.5 mm tall and 6 mm thick: print them slowly (outer walls about 40 mm/s) with a brim, spaced apart, so they stay straight.

## Inspect in the slicer before printing

- **Window slot:** two vertical rails inside the front wall, a top stop above the window, and a 3.3 mm slot open at the bottom.
- **Button guides:** three tubes hanging from the roof at the right-hand end, with 6.6 mm holes through the top.
- **Light baffle:** a thin fin hanging from the roof just left of the guides; it hides the brass rods from anyone looking in through the window.
- **Roof holes:** four 2.4 mm holes along the middle of the roof for the screws that hold the wood top.
- **Corner blocks:** four solid blocks in the bottom corners, each with a 1.7 mm pilot hole.
- **Floor standoffs:** five 5 mm posts on part 02, 19.4 mm tall, each with a 1.7 mm pilot at the top.
- **Cable path:** the 4.2 mm rear hole, and the cradle and two bosses on the floor.

## After printing

- Tap every 1.7 mm pilot with an M2 tap; clear the chips.
- Check that each rod slides freely in its guide.
- Remove all support material from inside the case, especially around the window slot and the baffle.

## Window panel

Cut `cad/dxf/Window_panel_3mm_1to1.dxf` (layer `CUT`, millimetres, 1:1) from **3 mm cast acrylic**. Smoked grey or bronze gives the vintage look: the glowing digits show through and the rest of the inside disappears. Before cutting, confirm the laser software reads it as 206 × 92.8 mm, and peel the protective film only at assembly.

The panel slides up into its slot from the open bottom of the inner case. Before the case goes on, put three small dots of clear neutral-cure silicone in the slot (both top corners and the middle of the top edge) so the panel stays in the case when you lift the case off later.

## Changing a dimension

1. Edit the value in `cad/DIMENSIONS.json` (for example `window_x`, `button_hole_d` or `wood_fit_gap`).
2. Run `scripts/render_cad`. It rebuilds every STEP, STL, 3MF, plate, DXF, drawing and preview, then runs the geometry checks, so the outputs never drift from the source.
3. Reprint the coupon. Record the change in [VALIDATION.md](VALIDATION.md).

**Never scale a part uniformly to fix a hole.** That moves every screw post too.

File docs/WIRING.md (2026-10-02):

# Wiring, pin by pin

This page is the human-readable view of [`hardware/NET_MAP.csv`](../hardware/NET_MAP.csv) (340 connections, 106 shared nets). The net map is the source of truth; the generated KiCad schematic ([PDF](Nixie_RevC_schematic.pdf)) is checked against it by a native KiCad netlist export. **Verify every pin against the real part and board before soldering.**

Wiring overview and shift chain

Status column in the net map: `OK` = stable, well-known pinout (Nano silk labels, DS3231SN); `DATASHEET` = taken from the HV5522 data sheet, recheck against the current Microchip revision; `VERIFY` = design intent to confirm during schematic review.

## 1. Power path

| From | Through | To | Net |
|---|---|---|---|
| 12 V adapter | J1 pad 1 (pad 2 = GND) | F1 pin 1 | `+12V_IN` |
| F1 pin 2 | QP1 drain → source (gate to GND) | V12 rail | `12V_FUSED` → `V12` |
| V12 | C5 47 µF to GND; TP2 | Nano VIN, U1/U2 VDD (pin 25), C1–C4 | `V12` |
| Nano 5V | TP3 | U3 VCC (pin 2), C8, RI1, RI2 | `V5` |
| V12 | JP1 (HV_ARM) | QP2 source, RGP | `HV_ARMED_12V` |
| QP2 drain | C6 10 µF to GND | PS1 pin 1 VIN | `HV_IN_12V` |
| PS1 pin 3 VOUT | CHV to GND; TP4 | RA1–RA6, RL1, RL2, RH1, RS1 | `HV170` |

Test pads: TP1 GND, TP2 V12, TP3 V5, TP4 HV170. PCB pads: J1 12 V in, J2 backup battery (pad 1 VBAT, pad 2 GND).

## 2. Arduino Nano (A1)

| Nano pin | Net | Goes to | Notes |
|---|---|---|---|
| D2 | `BTN_SET` | SW1 pins 1, 2 | `INPUT_PULLUP`, press = LOW |
| D3 | `BTN_H` | SW2 pins 1, 2 | |
| D4 | `BTN_M` | SW3 pins 1, 2 | Switch pins 3, 4 to GND |
| D6 | `RUN` | RB4 → QL4 → RB6 → QL5 → `DRV_BL` | HIGH = outputs enabled |
| D7 | `HV_EN` | RB5 → QE1 → `HV_GATE` (QP2 gate) | HIGH = converter input on |
| D9 | `LATCH_N` | RB3 → QL3 → `DRV_LE` | Inverted: Nano HIGH → LE LOW |
| D10 | `DATA_N` | RB2 → QL2 → `DRV_DIN` | Inverted |
| D13 | `CLOCK_N` | RB1 → QL1 → `DRV_CLK` | Inverted. D13 also drives the Nano's light-emitting diode (LED): harmless |
| A0 | `HV_SENSE` | RS2/RS3 junction, C7 | 170 V → 1.85 V |
| A1 | `VIN_SENSE` | RV1/RV2 junction | 12 V → 2.1 V; firmware window 10.8–13.2 V |
| A4 | `I2C_SDA` | U3 pin 15, RI1 | I²C (Inter-Integrated Circuit) data |
| A5 | `I2C_SCL` | U3 pin 16, RI2 | I²C clock |
| VIN / 5V / GND | `V12` / `V5` / `GND` | | |

**Rule: no Nano pin connects directly to an HV5522 pin.** The HV5522 needs logic HIGH above VDD − 2 V (about 10 V at 12 V), which a 5 V Nano cannot give, and a direct link would put the Nano on a board that carries 170 V. `tests/check_design.py` enforces this rule on the net map.

## 3. Level shifters (5 V → 12 V logic)

Each Nano output drives an NPN (bipolar, negative-positive-negative) transistor through a 10 kΩ base resistor, with a 100 kΩ pull-down so the transistor stays off while the Nano is in reset.

| Signal | Transistor | Base R / pull-down | Collector pull-up | Driver net | Default with Nano in reset |
|---|---|---|---|---|---|
| Clock | QL1 MMBT3904 | RB1 / RPD1 | RC1 10 k to V12 | `DRV_CLK` | HIGH (reset state; running idle is LOW) |
| Data | QL2 MMBT3904 | RB2 / RPD2 | RC2 | `DRV_DIN` | HIGH |
| Latch | QL3 MMBT3904 | RB3 / RPD3 | RC3 | `DRV_LE` | HIGH (latches follow the shift register, but BL is blanking) |
| Blank | QL4 MMBT3904 → QL5 MMBT3906 | RB4 / RPD4, RB6 / RPU5 | RD1 10 k **pull-down** | `DRV_BL` | **LOW = all outputs off** |
| HV enable | QE1 MMBT3904 | RB5 / RPD5 | RGP 100 k gate pull-up | `HV_GATE` | QP2 **off** |

Blanking uses two stages so that its default is LOW (blanked) rather than the HIGH that a single pulled-up inverter would give.

## 4. HV5522PJ-G drivers (U1, U2)

PLCC-44 pins, from the HV5522 data sheet: 30–44 = HVOUT1–15, 1–17 = HVOUT16–32, 18 DATA OUT, 22 POL, 23 CLK, 24 VSS, 25 VDD, 26 LE, 27 DATA IN, 28 BL, 19–21 and 29 not connected.

| Pin | U1 net | U2 net |
|---|---|---|
| 25 VDD (logic supply) / 24 VSS (ground) | `V12` / `GND` | `V12` / `GND` |
| 23 CLK | `DRV_CLK` | `DRV_CLK` |
| 26 LE | `DRV_LE` | `DRV_LE` |
| 28 BL | `DRV_BL` | `DRV_BL` |
| 22 POL | **`V12` (tied HIGH)** | **`V12`** |
| 27 DATA IN | `DRV_DIN` | `DRV_CHAIN` |
| 18 DATA OUT | `DRV_CHAIN` | not connected |

**Why POL is tied high.** In the data sheet's function table, BL LOW with POL HIGH turns every output **off**; BL LOW with POL LOW turns every output **on**. Tying POL to V12 is what makes the default-low BL line a blanking signal. If POL were ever left floating or low, a reset would light all ten digits of every tube at once.

### Driver output map

| Driver output (pin) | U1 | U2 |
|---|---|---|
| HVOUT1–10 (30–39) | T1 digits 0–9 | T4 digits 0–9 |
| HVOUT11–20 (40–44, 1–5) | T2 digits 0–9 | T5 digits 0–9 |
| HVOUT21–30 (6–15) | T3 digits 0–9 | T6 digits 0–9 |
| HVOUT31 (16) | L1 separator (via lamp) | L2 separator |
| HVOUT32 (17) | unused, never set | unused, never set |

Each IN-14 anode goes to HV170 through its own 22 kΩ resistor: T*n* anode ← RA*n*. The IN-14 left and right decimal-point cathodes are left unconnected. Each lamp: HV170 → RL*n* → lamp → driver HVOUT31.

T1 and T2 show hours, T3 and T4 minutes, T5 and T6 seconds. L1 sits between T2 and T3; L2 between T4 and T5.

### Shift order and timing

- Firmware sends 64 bits, **bit 63 first**, then pulses LE. U1 DATA OUT feeds U2 DATA IN.
- Data enters at HVOUT1 and moves toward HVOUT32, so after 64 clocks **bit 0 is U1 HVOUT1** and **bit 63 is U2 HVOUT32**. Frame bit *b* of bank *k* = HVOUT(*b* − 32*k* + 1). This is `kOutReversed = false` in `display_core.h`.
- The data sheet shifts on the CLK falling edge and loads the latches while LE is HIGH. The firmware holds data steady across the whole clock pulse, so either edge would capture it. Confirm with Stage 4 of the build guide by lighting one digit at a time.

## 5. Real-time clock (U3, DS3231SN#, SOIC-16 small-outline package)

| Pin | Net | Pin | Net |
|---|---|---|---|
| 1 32kHz | not connected | 13 GND | `GND` |
| 2 VCC | `V5` | 14 VBAT | `VBAT` (J2 pad 1 → CR2032 +) |
| 3 INT/SQW | not connected | 15 SDA | `I2C_SDA` |
| 4 RST | not connected | 16 SCL | `I2C_SCL` |
| 5–12 | `GND` (the data sheet asks for these not-connected (N.C.) pins to be grounded; **verify**) | | |

## 6. HV converter (PS1, NCH8200HV)

Pins per the v2.1 data sheet: VIN, GND, VOUT, GND, GND (numbered 1–5 here). Confirm on the module you receive. The module has **no enable pin, no reverse-polarity protection and no documented current limit**; QP2 is the enable, and QP1 plus F1 protect the input.

## 7. Off-board wiring

| Wire | From | To | Notes |
|---|---|---|---|
| 12 V pigtail | Rear 4.2 mm opening, clamped by part 03 | J1 pads | Strain relief before the solder joint |
| Battery | Insulated CR2032 holder | J2 pads | Primary CR2032 only |
| Neon leads | L1, L2 | PCB | Sleeved ≥300 V (600 V preferred) over their whole exposed length |

Dress all wires away from the HV area around PS1, the anode resistors and the tube leads, and tie them down with the two cable ties.

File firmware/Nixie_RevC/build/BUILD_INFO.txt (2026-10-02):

Nixie_RevC.hex - UNVALIDATED prototype firmware image (never run on a Rev C board)
Built by scripts/avr_compile_check.sh: avr-gcc 7.3.0, ATmega328P @ 16 MHz, -Os
Arduino AVR core: 42fa4a1ea1b1b11d1cc0a60298e529d37f9d14bd (1.8.6 expected)
Flash used: 13712 bytes, static RAM: 844 bytes
SHA-256: 2ae26238d1a0eeb7e5ef4e7a05358be6d320b72e4ed13d45e33b501e9dc928cd

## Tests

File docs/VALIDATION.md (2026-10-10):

# Validation status (Rev C)

**Rev C is an UNVALIDATED ENGINEERING PROTOTYPE, not a fabrication release.** No Gerbers or drill files are shipped. This page keeps two lists apart on purpose:

- **Recorded checks**: things a script or tool did to the *files* in this repository. They show the files are self-consistent. They are **not** independent proof that the circuit, the board or the enclosure works.
- **Physical checks**: things that can only be done with real parts, a real board and a meter. **None of these has been done.**

## Recorded checks (repeat with `scripts/run_all_checks.sh`)

| Check | Tool | Result on 2026-09-30 | What it does *not* show |
|---|---|---|---|
| Equation arithmetic (39 checks, including the sealed, wood-clad case temperature) | `tests/check_equations.py` | 39 / 39 pass | That the real tubes, converter or resistors behave like the model |
| Design-table consistency (153 checks): BOM counts, no Nano pin on a driver net, pull-ups/pull-downs present, POL tied high, one cathode per driver output, placement inside the board, fastener lengths | `tests/check_design.py` (**custom Python, not KiCad DRC**) | 153 / 153 pass | Electrical correctness of the design; anything about copper |
| Requirements and BOM (traceability, safety ratings in BOM.csv, bed fit, files exist) | `tests/check_requirements.py` (**custom Python**) | 155 / 155 pass | Whether the requirements are met by real hardware |
| Fabrication release gate | `scripts/make_fab_outputs.sh` | Refuses (no routed board): correct | Anything about a future board |
| Firmware display core on a PC (383 checks), including every displayable time producing a one-digit-per-tube frame | `g++` + `tests/test_display_core.cpp` | 383 / 383 pass | That the bit order, polarity and clock edge match the real HV5522 |
| Firmware compile and link for ATmega328P | `scripts/avr_compile_check.sh`: avr-gcc 7.3.0 against ArduinoCore-avr 1.8.6, **manual build, not the Arduino IDE** | Pass: 13 712 B flash, 844 B static RAM, no sketch warnings with `-Wall -Wextra` | That the IDE build is identical, that it uploads, or that it runs correctly |
| Schematic encodes the net map | `scripts/make_kicad.py`: **native** `kicad-cli 7.0.11 sch export netlist`, compared net by net with `NET_MAP.csv` | 106 / 106 nets match, no extra nets | ERC; readability; whether the net map itself is right. **Native ERC has not been run** |
| Placement board | `scripts/make_kicad.py`: **native** pcbnew 7.0.11 DRC on `Nixie_RevC_placement.kicad_pcb` (outline, 5 M2 holes, placeholder courtyards on both sides, no copper) | 0 violations | Anything about routing, clearances, copper or real footprints |
| Desktop app (Nixie Clock Companion 1.0.0) | electron-builder 26.15.3 / Electron 44.5.1, Linux AppImage and `.deb` packaged; app launched on a virtual display (Xvfb) with Playwright: pages load, calculator matches EQUATIONS.md, Web Serial present, no page errors | Pass on Linux x64 | Windows and macOS builds (made by CI at release, not yet run); any real serial session with a Nano |
| Enclosure computer-aided design (CAD) model | `tests/check_cad.py`: OpenCASCADE booleans between every case part (printed, acrylic, five wood boards, brass bezel and feet) and nominal envelopes of the PCB, glass, spacers, lamps and switches, plus enclosure rules (tubes fully inside, window fully glazed, rod and cable gaps, light baffle, mitres, bezel cover, screw engagement, build volume) | 279 / 279 pass | Physical fit of real, printed parts, real wood (which moves with humidity) and real tubes |

Reports: `hardware/reports/SUMMARY.txt`, `hardware/reports/placement_native_drc.rpt`, `hardware/reports/netlist_vs_netmap.txt`, `cad/BUILD_REPORT.txt`.

## Physical checks: all NOT established

| Item | Status | Stage |
|---|---|---|
| Native KiCad electrical rules check (ERC) on a human-reviewed schematic | NOT DONE | Before Stage 1 |
| Routed 4-layer board with native design rules check (DRC) under `Nixie_RevC.kicad_dru` | NOT DONE (board not routed) | Before Stage 1 |
| Experienced HV layout review, then Gerbers | NOT DONE | Before Stage 1 |
| Arduino integrated development environment (IDE) compile and upload to a real Nano | NOT DONE | 2 |
| Printed fit: coupons, inner case, floor, button rods, window panel, screws | NOT DONE | 0, 6 |
| Woodwork fit: box over the inner case, mitres, bezel, brass screws, feet | NOT DONE | Woodwork, 6 |
| Low-voltage power-up, reverse polarity, logic levels, blanking default | NOT DONE | 1, 2 |
| HV bring-up, sense accuracy, **measured discharge** | NOT DONE | 3 |
| Digit mapping, per-digit current, converter loading | NOT DONE | 4 |
| Closed-case thermal margin (with the wood box on) | NOT DONE | 5 |
| Any safety compliance or certification | NOT CLAIMED | — |

## Untested assumptions

Each of these is a number or behaviour the design relies on and that nobody has measured on Rev C hardware.

1. IN-14 bulb is about 19 × 55 mm (Tube-Tester) on 7 mm factory spacers; the case leaves about 23 mm above the glass. Real tubes vary.
2. IN-14 lead pattern (13 leads) is a **placeholder**: 12.0 mm circle, 1.0 mm holes. Measure your tubes.
3. IN-14 maintaining voltage about 145 V; typical current 2.5 mA. With 22 kΩ at 170 V the model gives about 1.1 mA.
4. NE-2 maintaining voltage about 60 V.
4a. IN-14 ignition (strike) voltage is commonly quoted as up to about 170 V; it was not confirmed from a primary source here. On a fixed 170 V rail that leaves little margin: check that every digit strikes reliably, including from cold. The firmware's 150 V floor is a fault limit, not an operating point.
5. NCH8200HV: output fixed at about 170 V, 2.5–15 V input, 30 mA peak, pin order VIN, GND, VOUT, GND, GND, **internal output capacitance unknown** (the discharge model assumes 1 µF). Module outline unknown: the placement board reserves 30 × 21 mm.
6. HV5522PJ-G function table (POL HIGH + BL LOW = all off; with POL HIGH and BL HIGH, a register 1 = output on), shift direction (HVOUT1 → HVOUT32), falling-edge clock, LE HIGH loads latches, VDD 10.8–13.2 V (the firmware's VIN window stops at 13.2 V for this reason), PLCC pin numbers: taken from the Supertex-era HV5522 data sheet. Recheck against Microchip DS20005699.
7. DS3231SN pins 5–12 should be grounded.
8. Omron B3F-1062-G body about 3.5 mm tall and 6 × 6 mm.
9. Nano's 5 V rail is the ADC reference, accurate to a few percent.
10. All printed fit allowances marked VERIFY in `cad/DIMENSIONS.json`.
11. Hardwood: 9.5 mm boards, 0.5 mm fit gap per side to the inner case, 1.6 mm pilots that hold M2 screws in walnut, and a thermal conductivity of about 0.15 W/(m·K) across the grain. Wood moves with humidity; the gap is a guess.

## Open items

These came out of the recorded checks and are deliberately left visible rather than fixed silently.

- **Anode resistor fault power.** If the full 170 V rail appears across one 22 kΩ resistor (a shorted tube or cathode path), it dissipates 1.31 W, above its 1 W rating. The NCH8200HV data sheet documents no current limit. Options for a future revision: a 2 W part or two 11 kΩ 1 W in series, a current-limited HV supply, or an HV fuse. Rev C keeps the brief's 22 kΩ 1 W values.
- **Tube current well below typical.** The 22 kΩ start value predicts about 45 % of the IN-14's typical 2.5 mA. Measure at Stage 4 before deciding anything.
- **Enclosure changed from the brief: heirloom case.** At the builder's request the low base with tubes standing out of it was replaced, first by a fully enclosed alarm-clock case and then by the current heirloom case: a printed black inner case (tubes inside, a captive 3 mm smoked acrylic window, buttons pressed from the top through rods, PCB carried on floor standoffs) clad in a mitred walnut box with a brass bezel, brass feet and brass button caps. All functional fits stay in the printed part; the wood is held only by four screws into its top board. Fasteners: 4 × M2 × 16, 4 × M2 × 8, 7 × M2 × 6, 6 × M2 × 6 brass. Test pads TP1–TP4 and the HV_ARM header are on the top side so they can be reached with the case lifted off.
- **Wood and brass (new, unverified).** Mitre accuracy, the 0.5 mm fit gap, seasonal wood movement, and the strength of brass M2 screws in walnut pilots are all untested. Brass swarf is conductive: the build order (woodwork and brass finished and vacuumed before electronics) is the mitigation. No flammability rating is claimed for the wood or the PETG.
- **Light baffle.** A 1.6 mm printed fin hides the brass rods from the window. It clears tube 6 by 1.1 mm and the rods by 0.8 mm on nominal dimensions; real tube diameters vary.
- **Button rods (unverified).** Each rod rests on its switch by its own weight (about 0.04 N printed, 0.24 N in solid brass, against a 1.47 N actuation force) with about 1 mm of free travel above the 0.25 mm switch travel. The height chain (standoffs, PCB, switch, roof, wood top) has not been measured; coupon 06 and Stage 6 check it.
- **Window retention.** The panel rests on the floor and is held in its slot by three silicone dots, so it stays in the case when the case is lifted. Without the silicone it would drop out onto the tubes.
- **Sealed case, no vents.** Kept closed on purpose so HV stays enclosed. With the wood box on, the model predicts an average internal rise of about 3–5 K at about 2.7 W ([EQUATIONS.md](EQUATIONS.md#7-sealed-case-temperature)); local hot spots (the Nano's regulator, PS1) are checked at Stage 5.
- **Case printing.** The inner case prints upright and needs tree supports inside under the roof and in the window opening; support removal around the window slot must leave the slot clean (see [PRINTING.md](PRINTING.md)).
- **USB back-feed.** The converter can start from 2.5 V. With the shunt fitted and only USB connected, back-feed through the Nano could, in principle, reach it if QP2 were on. Firmware refuses HV below 10.8 V VIN, and the flashing procedure removes the shunt; Stage 2 checks that `HV_IN_12V` stays near 0 V whenever HV is not requested.
- **Serial monitor resets the Nano.** Opening the serial monitor resets the board. The firmware therefore latches HV faults in EEPROM; it does not rely on the Nano staying powered. Confirmed in code only; Stage 2 checks it on a board.
- **Bottom-side keep-out above the cable clamp.** Parts under the clamp region near the rear opening must stay below about 11 mm.
- **Nano classic bootloader and the watchdog.** Some older Nano bootloaders hang after a watchdog reset. With the pins high-impedance the clock simply stays dark and HV stays off (safe), but it will not restart until power-cycled. Record which bootloader your Nano has.

## Build log (fill in)

| Date | Stage | Builder | Reviewer | Measurement | Value | PASS/FIX/STOP | Notes |
|---|---|---|---|---|---|---|---|
| | 0 | | | glass diameters T1–T6 | | | |
| | 0 | | | real IN-14 lead circle | | | |
| | 1 | | | TP2, TP3, reverse polarity | | | |
| | 2 | | | IDE / core / compiler versions | | | |
| | 2 | | | DRV_BL and HV_GATE in reset | | | |
| | 3 | | | TP4 running; firmware HV reading | | | |
| | 3 | | | TP4 at 1 s / 5 s / 60 s after off | | | |
| | 4 | | | per-digit current (attach table) | | | |
| | 4 | | | supply current, all lit | | | |
| | 5 | | | regulator / PS1 / RA temps after 2 h | | | |
| | 6 | | | enclosure fit, gaps | | | |

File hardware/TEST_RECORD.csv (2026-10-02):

serial | date | stage | step | measurement | expected | measured | unit | result(PASS/FIX/STOP) | tester | reviewer | notes
 |  | 0 | coupon 06 | glass passes 19.4 mm opening (T1-T6) | no contact |  | -
 |  | 0 | coupon 07 | IN-14 lead circle diameter | 12.0 (placeholder) |  | mm
 |  | 1 | power | TP2 V12 at 12.0 V input | 11.8-12.0 |  | V
 |  | 1 | power | reverse polarity current | about 0 |  | mA
 |  | 1 | power | TP3 V5 with Nano fitted | 4.9-5.1 |  | V
 |  | 2 | firmware | IDE / core / compiler versions | record |  | -
 |  | 2 | RTC | time kept after 5 min unpowered | yes |  | -
 |  | 2 | HV switch | HV_IN_12V with Nano held in reset | about 0 |  | V
 |  | 2 | blanking | DRV_BL with Nano held in reset | LOW |  | V
 |  | 2 | fault latch | fault survives reset until CLEARFAULT | yes |  | -
 |  | 3 | HV | TP4 running | 165-175 |  | V
 |  | 3 | HV | firmware HV sense vs meter | within 5 % |  | %
 |  | 3 | discharge | TP4 1 s after HVOFF | record |  | V
 |  | 3 | discharge | TP4 60 s after unplugging | below 10 |  | V
 |  | 4 | digits | per-digit current (attach 60 values) | 0.7-1.6 |  | mA
 |  | 4 | load | TP4 with all tubes lit | above 160 |  | V
 |  | 4 | load | 12 V input current with all lit | about 0.25 (stop >0.35) |  | A
 |  | 5 | thermal | Nano regulator after 2 h closed | below about 70 |  | C
 |  | 5 | thermal | PS1 and anode resistors after 2 h | record |  | C
 |  | 6 | enclosure | no HV visible through any gap | none |  | -
 |  | 6 | labels | HV warning and rating labels fitted | yes |  | -

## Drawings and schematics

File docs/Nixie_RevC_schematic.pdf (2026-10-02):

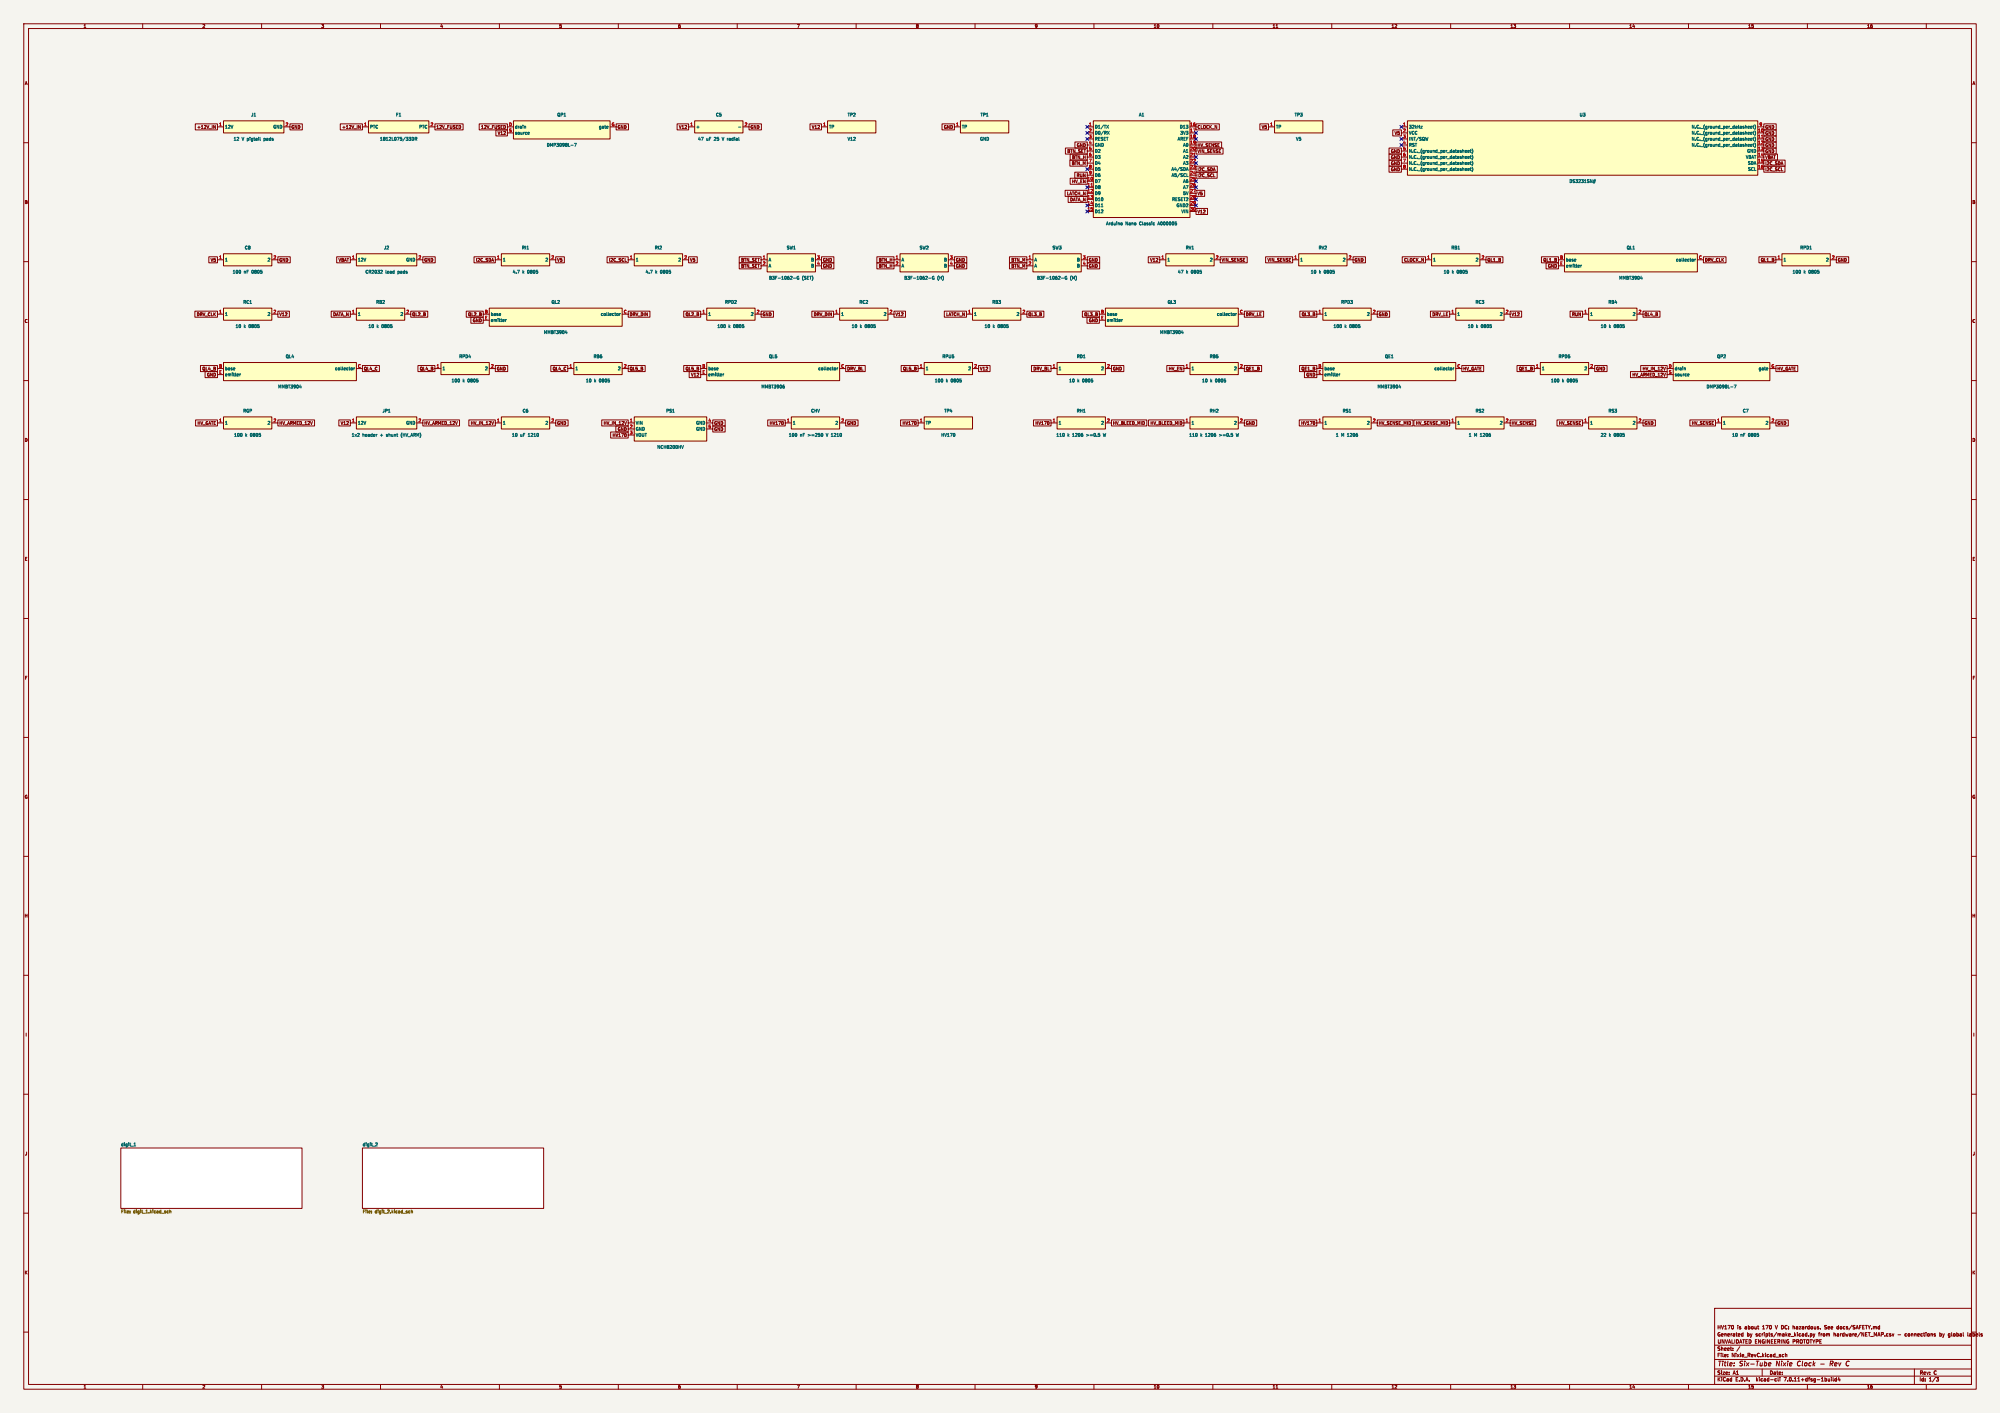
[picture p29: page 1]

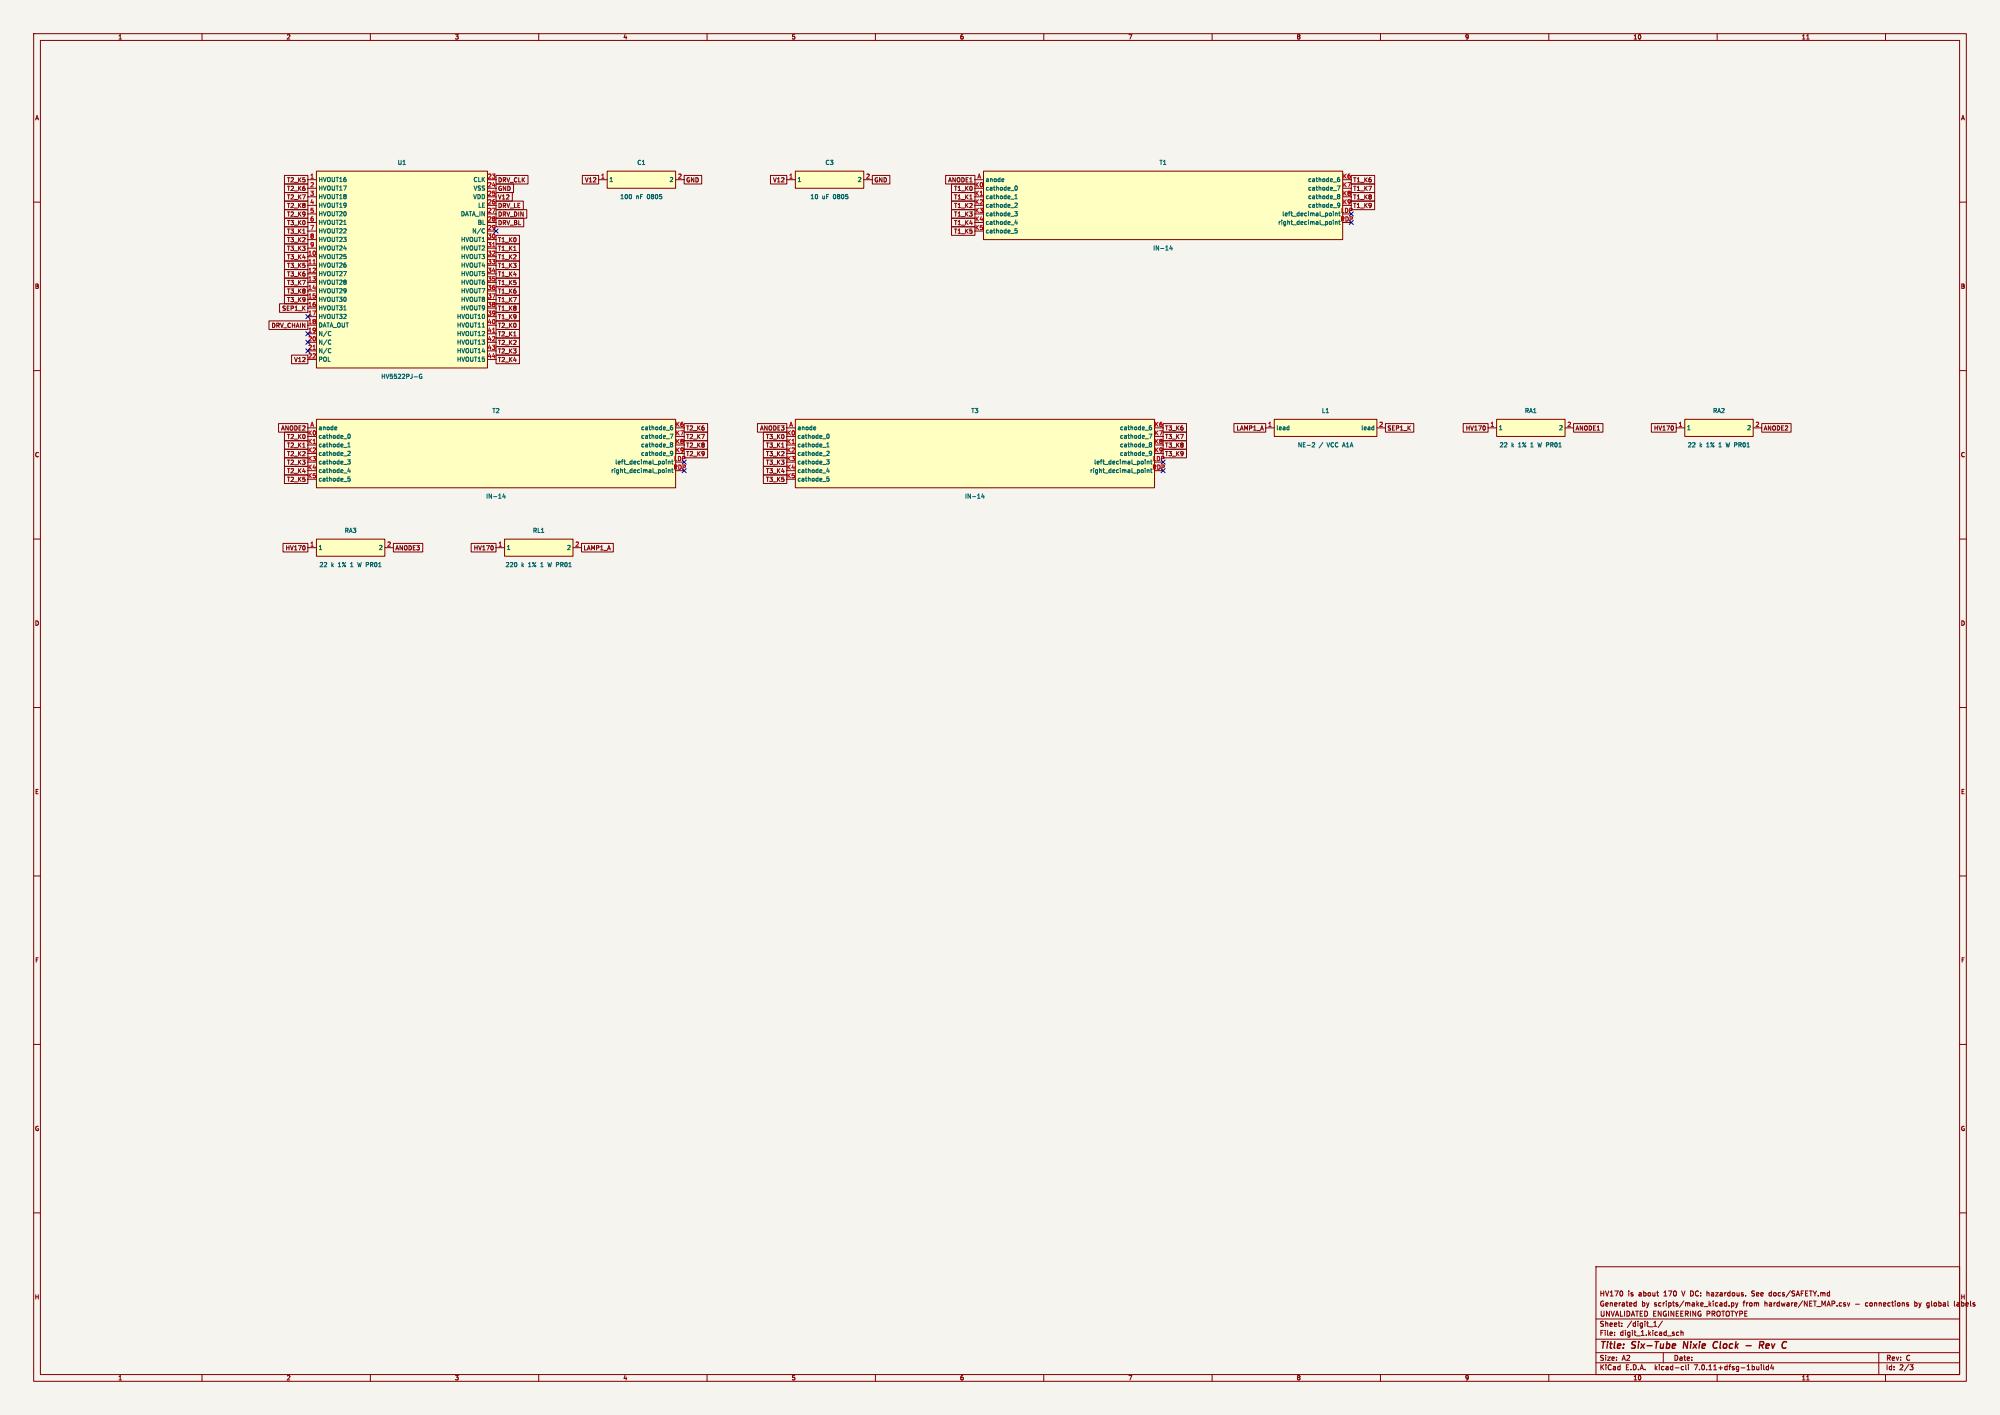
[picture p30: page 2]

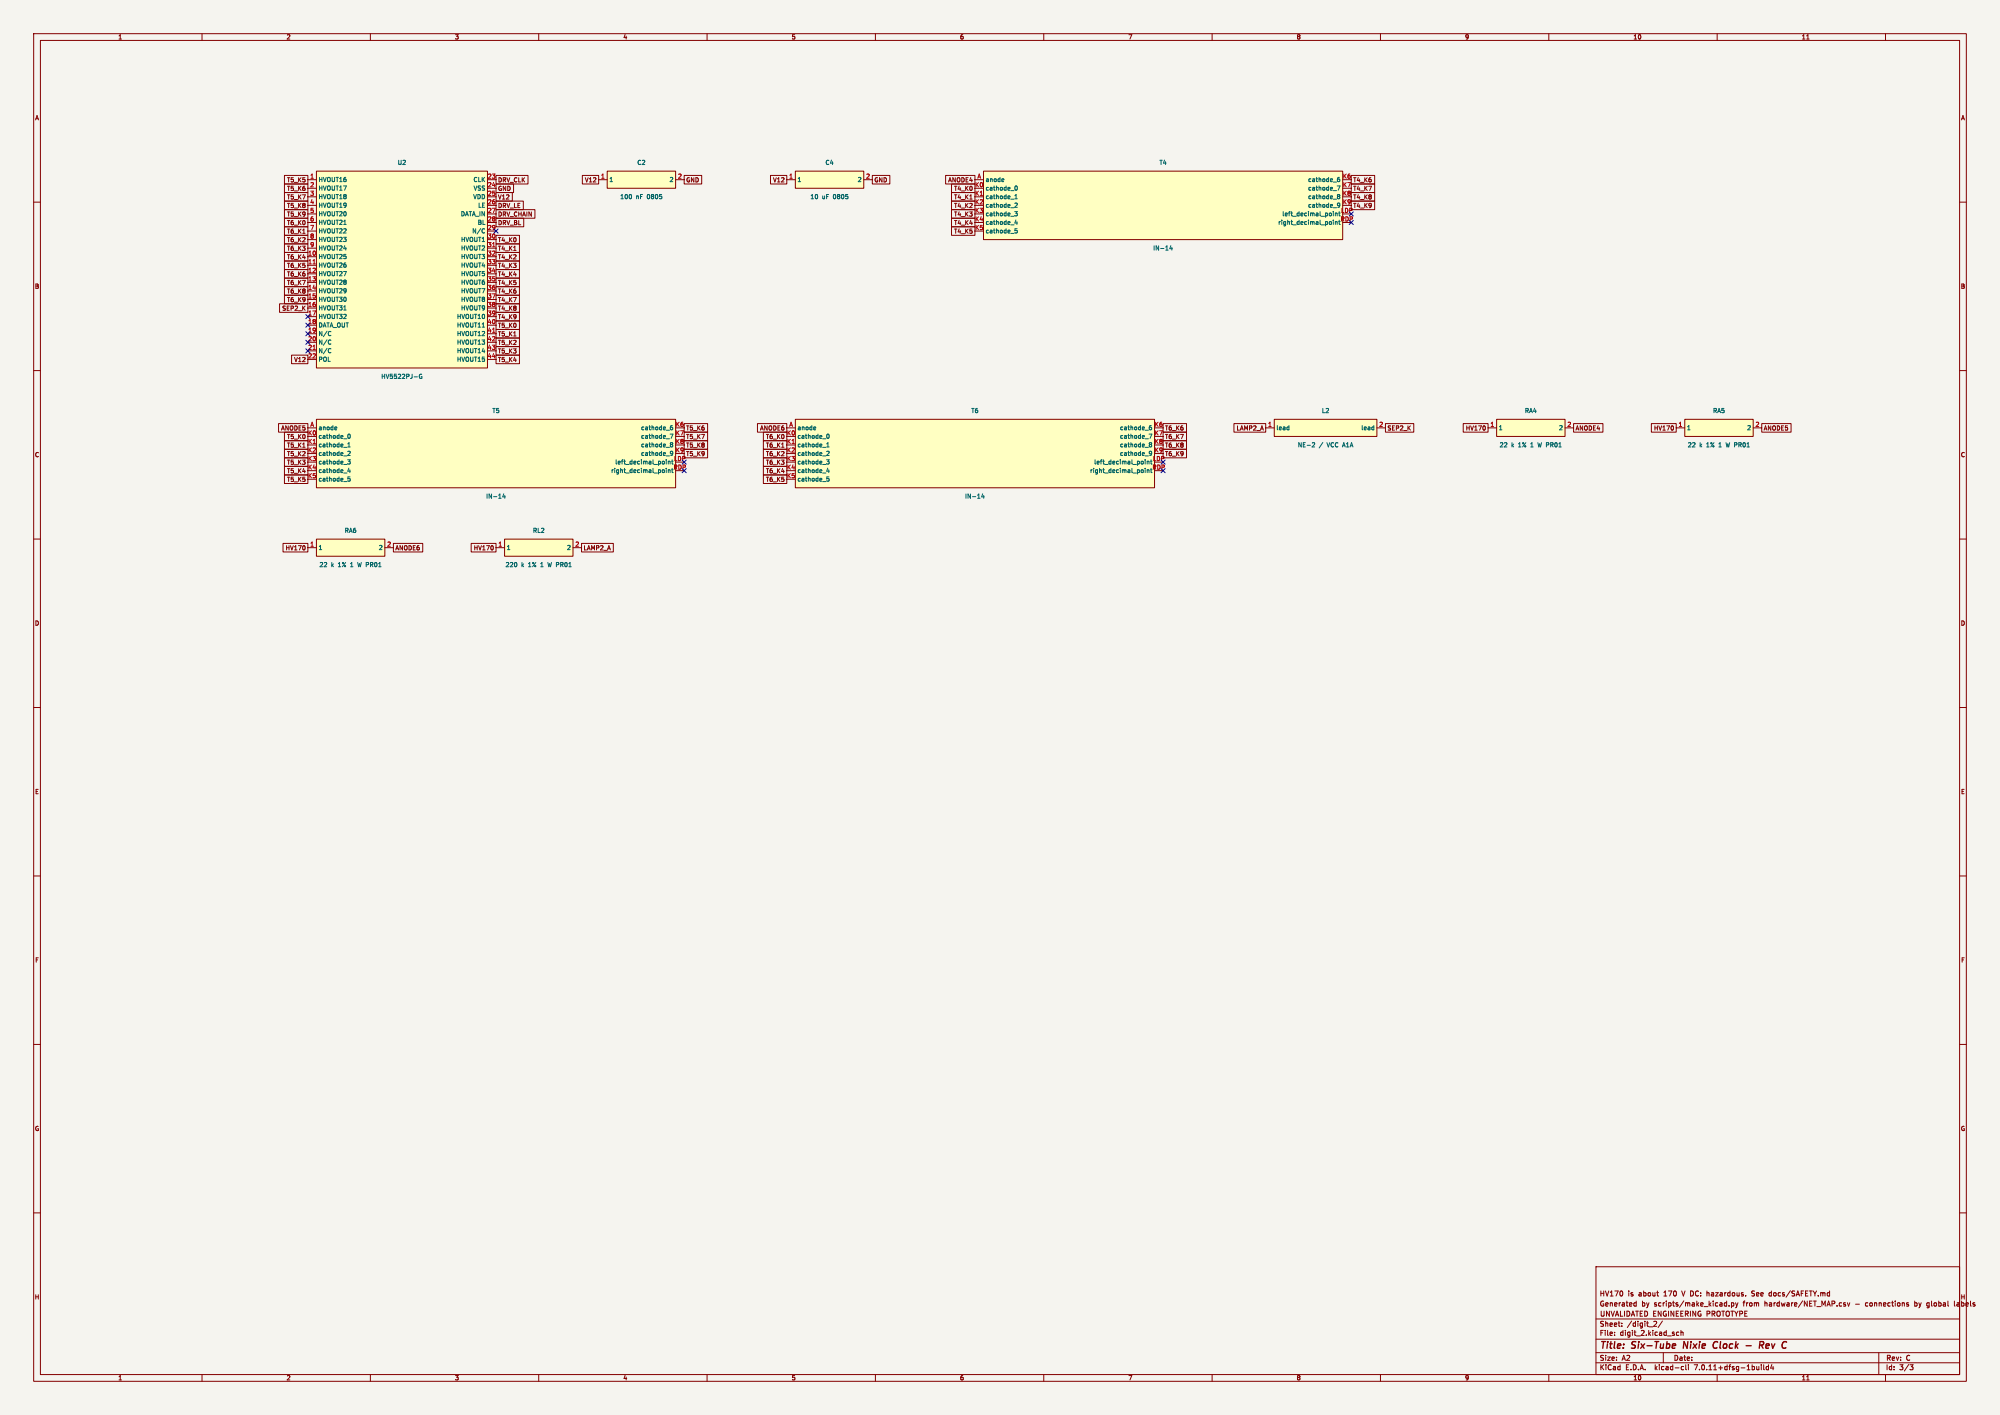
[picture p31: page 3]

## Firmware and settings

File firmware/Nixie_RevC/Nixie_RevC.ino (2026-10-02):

// Nixie_RevC.ino - Six-Tube Nixie Clock, Rev C firmware.
//
// Target: Arduino Nano Classic (A000005, ATmega328P, 16 MHz). NOT for ESP32 or Nano Every.
// Libraries: Wire and EEPROM (both ship with the Arduino AVR core). Serial: 115200 baud.
//
// STATUS: UNVALIDATED. This sketch has been compiled for the ATmega328P outside the
// Arduino IDE (see docs/VALIDATION.md) but has never run on a Rev C board.
//
// SAFETY MODEL (see docs/SAFETY.md):
//  * Hardware defaults make the display blank and the HV converter off whenever the Nano
//    is in reset or unprogrammed (base pull-downs, BL pull-down, QP2 gate pull-up).
//  * This firmware keeps HV off until the time is valid (or the user is setting it with the
//    buttons, 60 s timeout), VIN is in range, and a start check sees the rail inside its window.
//    Any out-of-window reading latches HV_FAULT in EEPROM: it survives resets (watchdog,
//    brown-out, the serial monitor's auto-reset) until a deliberate CLEARFAULT command.
//  * Software OFF is NOT proof the rail is discharged. Always measure TP4 before touching.
//  * A 2 s watchdog resets the Nano if the loop hangs; reset = HV off and blank.

#include <Wire.h>
#include <EEPROM.h>
#include <avr/wdt.h>
#include "display_core.h"

// ---------------- Pins (match hardware/NET_MAP.csv) ----------------
const uint8_t PIN_BTN_SET = 2;
const uint8_t PIN_BTN_H = 3;
const uint8_t PIN_BTN_M = 4;
const uint8_t PIN_RUN = 6;       // HIGH = driver outputs enabled (two-stage shifter to BL)
const uint8_t PIN_HV_EN = 7;     // HIGH = converter input switch on (only if HV_ARM is fitted)
const uint8_t PIN_LATCH_N = 9;   // inverted through QL3: Nano HIGH -> LE LOW
const uint8_t PIN_DATA_N = 10;   // inverted through QL2: Nano HIGH -> DIN LOW
const uint8_t PIN_CLOCK_N = 13;  // inverted through QL1: Nano HIGH -> CLK LOW
const uint8_t PIN_HV_SENSE = A0;
const uint8_t PIN_VIN_SENSE = A1;

// ---------------- Limits (decivolts) - review during Stage 3 ----------------
const uint16_t HV_MIN_DV = 1500;       // below 150 V while running = fault
const uint16_t HV_MAX_DV = 1900;       // above 190 V at any time = fault
const uint16_t HV_OFF_OK_DV = 100;     // expected below 10 V a few seconds after HV off (the discharge gate)
const uint16_t VIN_MIN_DV = 108;       // 10.8 V
const uint16_t VIN_MAX_DV = 132;       // 13.2 V (HV5522 VDD maximum)
const unsigned long HV_START_MS = 1500;
const unsigned long HV_DECAY_MS = 3000;
const unsigned long WAKE_MS = 30000UL;
const unsigned long SET_TIMEOUT_MS = 60000UL;
const int FAULT_ADDR = 32;              // EEPROM byte holding the latched-fault marker
const uint8_t FAULT_MARK = 0xA5;        // only this value means "fault latched" (erased EEPROM reads 0xFF)
const uint8_t DS3231_ADDR = 0x68;
const bool SEPARATOR_BLINK = true;

// ---------------- Settings in EEPROM ----------------
struct Settings {
  uint8_t magic;       // 0xC3 = Rev C layout
  uint8_t twelveHour;  // 0 or 1
  uint8_t sleepOn;     // 0 or 1
  uint16_t sleepStart; // minutes of day
  uint16_t sleepEnd;   // minutes of day
};
Settings cfg;

void loadSettings() {
  EEPROM.get(0, cfg);
  if (cfg.magic != 0xC3 || cfg.twelveHour > 1 || cfg.sleepOn > 1 || cfg.sleepStart >= 1440 || cfg.sleepEnd >= 1440) {
    cfg.magic = 0xC3;
    cfg.twelveHour = 0;
    cfg.sleepOn = 0;
    cfg.sleepStart = 23 * 60;
    cfg.sleepEnd = 7 * 60;
    EEPROM.put(0, cfg);
  }
}
void saveSettings() { EEPROM.put(0, cfg); }

// ---------------- State ----------------
enum HvState : uint8_t { HV_OFF, HV_STARTING, HV_ON, HV_FAULT };
enum UiMode : uint8_t { UI_CLOCK, UI_SET_H, UI_SET_M };
HvState hv = HV_OFF;
UiMode ui = UI_CLOCK;
bool timeValid = false;
bool userHold = false;          // serial HVOFF
uint8_t hh = 0, mm = 0, ss = 0;
uint8_t lastSec = 0xFF;
unsigned long hvStateSince = 0;
unsigned long hvOffSince = 0;
bool decayChecked = true;
bool refusedReported = false;
bool unsafeFrame = false;
unsigned long uiSince = 0;
unsigned long wakeUntil = 0;
int8_t exerciseStep = -1;
unsigned long exerciseNext = 0;
const char* faultText = "";

// ---------------- Driver chain ----------------
// Idle levels at the drivers: CLK LOW, LE LOW (latch holds).
void driverIdle() {
  digitalWrite(PIN_CLOCK_N, HIGH);  // CLK LOW
  digitalWrite(PIN_LATCH_N, HIGH);  // LE LOW
  digitalWrite(PIN_DATA_N, HIGH);   // DIN LOW
}

// Shift 64 bits, bit 63 first, then pulse LE. Data is held stable across the whole
// clock pulse, so either clock edge captures it (VERIFY the edge against the datasheet).
void shiftFrame(uint64_t f) {
  if (!nixie::frameIsSafe(f)) {
    f = 0;  // never latch a frame with two cathodes on one tube
    unsafeFrame = true;  // loop() turns this into a latched HV fault
  }
  driverIdle();
  for (int8_t i = 63; i >= 0; i--) {
    bool bit = (f >> i) & 1;
    digitalWrite(PIN_DATA_N, bit ? LOW : HIGH);  // inverted
    delayMicroseconds(4);
    digitalWrite(PIN_CLOCK_N, LOW);   // CLK HIGH
    delayMicroseconds(4);
    digitalWrite(PIN_CLOCK_N, HIGH);  // CLK LOW
    delayMicroseconds(2);
  }
  digitalWrite(PIN_LATCH_N, LOW);   // LE HIGH: copy shift register to outputs
  delayMicroseconds(4);
  digitalWrite(PIN_LATCH_N, HIGH);  // LE LOW: hold
}

void blankDisplay() {
  digitalWrite(PIN_RUN, LOW);  // BL LOW
  shiftFrame(0);
}

// ---------------- Sensing ----------------
uint16_t readAvg(uint8_t pin) {
  uint16_t sum = 0;
  for (uint8_t i = 0; i < 8; i++) sum += analogRead(pin);
  return sum / 8;
}
uint16_t hvDv() { return nixie::hvDeciVolts(readAvg(PIN_HV_SENSE)); }
uint16_t vinDv() { return nixie::vinDeciVolts(readAvg(PIN_VIN_SENSE)); }

void printDv(uint16_t dv) {
  Serial.print(dv / 10);
  Serial.print('.');
  Serial.print(dv % 10);
  Serial.print(F(" V"));
}

// ---------------- HV control ----------------
void hvOff(const char* why) {
  digitalWrite(PIN_HV_EN, LOW);
  blankDisplay();
  if (hv == HV_ON || hv == HV_STARTING) {
    hvOffSince = millis();
    decayChecked = false;
  }
  if (hv != HV_FAULT) hv = HV_OFF;
  if (why && *why) {
    Serial.print(F("HV off: "));
    Serial.println(why);
  }
}

void hvFault(const char* why) {
  if (hv == HV_FAULT) return;  // already latched: no repeated messages or EEPROM writes
  hvOff(why);
  hv = HV_FAULT;
  faultText = why;
  if (EEPROM.read(FAULT_ADDR) != FAULT_MARK) EEPROM.write(FAULT_ADDR, FAULT_MARK);
  Serial.println(F("HV FAULT latched in EEPROM: survives resets. Find the cause, measure TP4, then send CLEARFAULT."));
}

void hvRequestOn() {
  if (hv != HV_OFF) return;
  uint16_t vin = vinDv();
  if (vin < VIN_MIN_DV || vin > VIN_MAX_DV) {
    if (!refusedReported) {  // report once per episode, not every loop
      refusedReported = true;
      Serial.print(F("HV refused: VIN "));
      printDv(vin);
      Serial.println(F(" outside 10.8-13.2 V (USB power alone cannot run the tubes)"));
    }
    return;
  }
  refusedReported = false;
  blankDisplay();
  digitalWrite(PIN_HV_EN, HIGH);
  hv = HV_STARTING;
  hvStateSince = millis();
}

void hvService() {
  unsigned long now = millis();
  uint16_t v = hvDv();
  if (v > HV_MAX_DV) {
    hvFault("HV above 190 V");
    return;
  }
  if (hv == HV_STARTING) {
    if (v >= HV_MIN_DV) {
      hv = HV_ON;
      hvStateSince = now;
      Serial.print(F("HV up: "));
      printDv(v);
      Serial.println();
    } else if (now - hvStateSince > HV_START_MS) {
      hvFault("HV did not reach 150 V (HV_ARM removed? converter fault?)");
    }
  } else if (hv == HV_ON) {
    if (v < HV_MIN_DV) hvFault("HV sagged below 150 V (overload or converter fault)");
  } else if (!decayChecked && now - hvOffSince > HV_DECAY_MS) {
    decayChecked = true;
    if (v > HV_OFF_OK_DV) {
      Serial.print(F("WARNING: HV still "));
      printDv(v);
      Serial.println(F(" 3 s after off. Bleeder or switch fault suspected. Do not open the case."));
    } else {
      Serial.print(F("HV decayed to "));
      printDv(v);
      Serial.println(F(" (sense reading only - still measure TP4 before any contact)"));
    }
  }
}

// ---------------- DS3231 ----------------
bool rtcRead(uint8_t reg, uint8_t* buf, uint8_t n) {
  Wire.beginTransmission(DS3231_ADDR);
  Wire.write(reg);
  if (Wire.endTransmission(false) != 0) return false;
  if (Wire.requestFrom((int)DS3231_ADDR, (int)n) != n) return false;
  for (uint8_t i = 0; i < n; i++) buf[i] = Wire.read();
  return true;
}
bool rtcWrite(uint8_t reg, const uint8_t* buf, uint8_t n) {
  Wire.beginTransmission(DS3231_ADDR);
  Wire.write(reg);
  for (uint8_t i = 0; i < n; i++) Wire.write(buf[i]);
  return Wire.endTransmission() == 0;
}

// Returns true when a valid time was read. Oscillator-stop flag = invalid.
bool rtcGetTime() {
  uint8_t st;
  if (!rtcRead(0x0F, &st, 1)) return false;
  if (st & 0x80) return false;  // OSF: clock stopped since last set (battery lost?)
  uint8_t b[3];
  if (!rtcRead(0x00, b, 3)) return false;
  uint8_t s = nixie::bcdToBin(b[0] & 0x7F);
  uint8_t m = nixie::bcdToBin(b[1] & 0x7F);
  uint8_t h;
  if (b[2] & 0x40) {  // 12-hour register format (set elsewhere): convert
    h = nixie::bcdToBin(b[2] & 0x1F) % 12;
    if (b[2] & 0x20) h += 12;
  } else {
    h = nixie::bcdToBin(b[2] & 0x3F);
  }
  if (!nixie::validTime(h, m, s)) return false;
  hh = h;
  mm = m;
  ss = s;
  return true;
}

bool rtcSetTime(uint8_t h, uint8_t m, uint8_t s) {
  if (!nixie::validTime(h, m, s)) return false;
  uint8_t b[3] = {nixie::binToBcd(s), nixie::binToBcd(m), nixie::binToBcd(h)};  // 24-hour format
  if (!rtcWrite(0x00, b, 3)) return false;
  uint8_t ctl;
  if (rtcRead(0x0E, &ctl, 1)) {
    ctl &= ~0x80;  // EOSC = 0: keep running on the backup cell
    rtcWrite(0x0E, &ctl, 1);
  }
  uint8_t st;
  if (rtcRead(0x0F, &st, 1)) {
    st &= ~0x80;  // clear OSF
    rtcWrite(0x0F, &st, 1);
  }
  hh = h;
  mm = m;
  ss = s;
  timeValid = true;
  return true;
}

// ---------------- Buttons ----------------
struct Button {
  uint8_t pin;
  bool stable;       // true = pressed
  bool last;
  unsigned long changed;
  unsigned long pressedAt;
  bool longFired;
};
Button bSet = {PIN_BTN_SET, false, false, 0, 0, false};
Button bH = {PIN_BTN_H, false, false, 0, 0, false};
Button bM = {PIN_BTN_M, false, false, 0, 0, false};

// Returns 1 on short press (on release), 2 on long press (2 s, fires once), 0 otherwise.
uint8_t poll(Button& b) {
  bool raw = digitalRead(b.pin) == LOW;
  unsigned long now = millis();
  if (raw != b.last) {
    b.last = raw;
    b.changed = now;
  }
  if (now - b.changed < 30 || raw == b.stable) {
    if (b.stable && !b.longFired && now - b.pressedAt > 2000) {
      b.longFired = true;
      return 2;
    }
    return 0;
  }
  b.stable = raw;
  if (raw) {
    b.pressedAt = now;
    b.longFired = false;
    return 0;
  }
  return b.longFired ? 0 : 1;
}

void wake() { wakeUntil = millis() + WAKE_MS; }

void handleButtons() {
  uint8_t s = poll(bSet), h = poll(bH), m = poll(bM);
  if (s || h || m) wake();
  if (ui != UI_CLOCK && millis() - uiSince > SET_TIMEOUT_MS) {
    ui = UI_CLOCK;  // abandon setting without saving
    Serial.println(F("Set mode timed out (nothing saved)"));
    return;
  }
  if (ui == UI_CLOCK) {
    if (s == 2 || (s == 1 && !timeValid)) {
      ui = UI_SET_H;
      uiSince = millis();
      if (!timeValid) { hh = 0; mm = 0; ss = 0; }
      Serial.println(F("Set hours (H/M to change, SET to continue)"));
    }
    if (h == 2) {
      cfg.twelveHour ^= 1;
      saveSettings();
      Serial.println(cfg.twelveHour ? F("12-hour mode") : F("24-hour mode"));
    }
    if (m == 2) {
      cfg.sleepOn ^= 1;
      saveSettings();
      Serial.println(cfg.sleepOn ? F("Display sleep ON") : F("Display sleep OFF"));
    }
    return;
  }
  if (s || h || m) uiSince = millis();  // any press in set mode restarts the timeout
  if (h == 1) {
    if (ui == UI_SET_H) hh = (hh + 1) % 24;
    else mm = (mm + 1) % 60;
  }
  if (m == 1) {
    if (ui == UI_SET_H) hh = (hh + 23) % 24;
    else mm = (mm + 59) % 60;
  }
  if (s == 1) {
    if (ui == UI_SET_H) {
      ui = UI_SET_M;
    } else {
      ui = UI_CLOCK;
      if (rtcSetTime(hh, mm, 0)) Serial.println(F("Time saved to RTC"));
      else Serial.println(F("RTC write failed"));
    }
  }
}

// ---------------- Serial commands ----------------
char line[32];
uint8_t lineLen = 0;

void printStatus() {
  Serial.print(F("time "));
  if (timeValid) {
    if (hh < 10) Serial.print('0');
    Serial.print(hh);
    Serial.print(':');
    if (mm < 10) Serial.print('0');
    Serial.print(mm);
    Serial.print(':');
    if (ss < 10) Serial.print('0');
    Serial.println(ss);
  } else {
    Serial.println(F("INVALID (set with T hh:mm:ss or long-press SET)"));
  }
  Serial.print(F("VIN "));
  printDv(vinDv());
  Serial.print(F("  HV sense "));
  printDv(hvDv());
  Serial.print(F("  state "));
  const char* names[] = {"OFF", "STARTING", "ON", "FAULT"};
  Serial.println(names[hv]);
  if (hv == HV_FAULT) {
    Serial.print(F("fault: "));
    Serial.println(faultText);
  }
  Serial.print(F("buttons SET/H/M "));
  Serial.print(digitalRead(PIN_BTN_SET) == LOW);
  Serial.print(digitalRead(PIN_BTN_H) == LOW);
  Serial.println(digitalRead(PIN_BTN_M) == LOW);
  Serial.print(cfg.twelveHour ? F("12h") : F("24h"));
  Serial.print(F("  sleep "));
  Serial.println(cfg.sleepOn ? F("on") : F("off"));
}

bool parse2(const char* p, uint8_t& v) {
  if (p[0] < '0' || p[0] > '9' || p[1] < '0' || p[1] > '9') return false;
  v = (uint8_t)((p[0] - '0') * 10 + (p[1] - '0'));
  return true;
}

void runCommand() {
  line[lineLen] = 0;
  uint8_t a, b, c, d;
  if (line[0] == 'T' && line[1] == ' ' && lineLen >= 10 && parse2(line + 2, a) && parse2(line + 5, b) && parse2(line + 8, c)) {
    Serial.println(rtcSetTime(a, b, c) ? F("OK time set") : F("ERR bad time or RTC"));
  } else if (!strcmp(line, "12") || !strcmp(line, "24")) {
    cfg.twelveHour = line[0] == '1';
    saveSettings();
    Serial.println(F("OK"));
  } else if (!strcmp(line, "SLEEP OFF")) {
    cfg.sleepOn = 0;
    saveSettings();
    Serial.println(F("OK"));
  } else if (!strncmp(line, "SLEEP ", 6) && lineLen >= 17 && parse2(line + 6, a) && parse2(line + 9, b) && parse2(line + 12, c) && parse2(line + 15, d) && a < 24 && b < 60 && c < 24 && d < 60) {
    cfg.sleepOn = 1;
    cfg.sleepStart = a * 60 + b;
    cfg.sleepEnd = c * 60 + d;
    saveSettings();
    Serial.println(F("OK"));
  } else if (!strcmp(line, "HVOFF")) {
    userHold = true;
    hvOff("serial HVOFF");
  } else if (!strcmp(line, "RUN")) {
    userHold = false;
    Serial.println(F("OK"));
  } else if (!strcmp(line, "CLEARFAULT")) {
    EEPROM.write(FAULT_ADDR, 0);
    if (hv == HV_FAULT) hv = HV_OFF;
    faultText = "";
    Serial.println(F("Fault cleared. HV may restart now if the display is wanted: be sure TP4 was measured and the cause fixed."));
  } else if (!strcmp(line, "EXERCISE")) {
    exerciseStep = 0;
  } else if (!strcmp(line, "STATUS") || lineLen == 0) {
    printStatus();
  } else {
    Serial.println(F("Commands: STATUS | T hh:mm:ss | 12 | 24 | SLEEP hh:mm hh:mm | SLEEP OFF | HVOFF | RUN | EXERCISE | CLEARFAULT"));
  }
  lineLen = 0;
}

void handleSerial() {
  while (Serial.available()) {
    char ch = Serial.read();
    if (ch == '\r') continue;
    if (ch == '\n') {
      runCommand();
    } else if (lineLen < sizeof(line) - 1) {
      line[lineLen++] = (ch >= 'a' && ch <= 'z') ? ch - 32 : ch;
    }
  }
}

// ---------------- Display policy ----------------
bool wantDisplay() {
  if (userHold || hv == HV_FAULT) return false;
  if (ui != UI_CLOCK) return true;  // user is setting the time
  if (!timeValid) return false;     // default off on invalid time
  if (cfg.sleepOn && nixie::inWindow(hh * 60 + mm, cfg.sleepStart, cfg.sleepEnd) && (long)(millis() - wakeUntil) > 0) return false;
  return true;
}

void render() {
  uint8_t d[nixie::kTubes];
  bool sep = true;
  if (exerciseStep >= 0) {
    nixie::exerciseDigits((uint8_t)exerciseStep, d);
  } else {
    nixie::timeToDigits(hh, mm, ui == UI_CLOCK ? ss : 0, cfg.twelveHour && ui == UI_CLOCK, d);
    bool blinkOff = (millis() / 400) % 2;
    if (ui == UI_SET_H && blinkOff) d[0] = d[1] = nixie::kBlank;
    if (ui == UI_SET_M && blinkOff) d[2] = d[3] = nixie::kBlank;
    if (ui == UI_CLOCK && SEPARATOR_BLINK) sep = (ss % 2) == 0;
  }
  shiftFrame(nixie::buildFrame(d, sep, sep));
  digitalWrite(PIN_RUN, HIGH);  // BL HIGH: outputs enabled
}

// ---------------- Arduino entry points ----------------
void setup() {
  // First: force every HV-related line to its safe state before anything else runs.
  digitalWrite(PIN_HV_EN, LOW);
  pinMode(PIN_HV_EN, OUTPUT);
  digitalWrite(PIN_RUN, LOW);
  pinMode(PIN_RUN, OUTPUT);
  pinMode(PIN_CLOCK_N, OUTPUT);
  pinMode(PIN_DATA_N, OUTPUT);
  pinMode(PIN_LATCH_N, OUTPUT);
  blankDisplay();

  uint8_t resetCause = MCUSR;
  MCUSR = 0;
  wdt_enable(WDTO_2S);

  pinMode(PIN_BTN_SET, INPUT_PULLUP);
  pinMode(PIN_BTN_H, INPUT_PULLUP);
  pinMode(PIN_BTN_M, INPUT_PULLUP);

  Serial.begin(115200);
  Serial.println(F("Nixie Rev C (UNVALIDATED PROTOTYPE FIRMWARE)"));
  // Note: some bootloaders clear MCUSR before the sketch runs, so these may not print.
  if (resetCause & _BV(WDRF)) Serial.println(F("reset: watchdog"));
  if (resetCause & _BV(BORF)) Serial.println(F("reset: brown-out"));

  Wire.begin();
  Wire.setClock(100000);
  loadSettings();
  if (EEPROM.read(FAULT_ADDR) == FAULT_MARK) {
    hv = HV_FAULT;
    faultText = "fault latched before this reset";
    Serial.println(F("HV FAULT is latched from before the reset: HV stays OFF. Measure TP4, fix the cause, then send CLEARFAULT."));
  }
  timeValid = rtcGetTime();
  if (!timeValid) Serial.println(F("RTC time invalid or RTC missing: display stays OFF. Set time to start."));
  wake();
  printStatus();
}

void loop() {
  wdt_reset();
  handleSerial();
  handleButtons();

  static unsigned long lastRtc = 0;
  if (millis() - lastRtc >= 100 && ui == UI_CLOCK) {
    lastRtc = millis();
    bool ok = rtcGetTime();
    if (!ok && timeValid) {
      timeValid = false;
      Serial.println(F("RTC read failed or oscillator stopped: display OFF"));
    } else if (ok) {
      timeValid = true;
    }
    // Hourly anti-poisoning exercise at hh:00:00.
    if (timeValid && ss != lastSec && mm == 0 && ss == 0 && exerciseStep < 0) exerciseStep = 0;
  }

  bool want = wantDisplay();
  if (want && hv == HV_OFF) hvRequestOn();
  if (!want && (hv == HV_ON || hv == HV_STARTING)) hvOff(userHold ? "" : "display not wanted (sleep or invalid time)");
  hvService();
  if (unsafeFrame) {
    unsafeFrame = false;
    Serial.println(F("unsafe frame rejected (more than one cathode on a tube)"));
    hvFault("unsafe frame rejected");
  }

  if (hv == HV_ON) {
    if (exerciseStep >= 0 && (long)(millis() - exerciseNext) >= 0) {  // wrap-safe
      exerciseNext = millis() + 200;
      render();
      if (++exerciseStep >= 10) exerciseStep = -1;
    } else if (exerciseStep < 0 && (ss != lastSec || ui != UI_CLOCK)) {
      render();
    }
  } else if (exerciseStep >= 0) {
    exerciseStep = -1;  // no HV, no exercise
  }
  lastSec = ss;
}

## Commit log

2026-10-02 Six-Tube Nixie Clock Rev C: build guide, KiCad, CAD, firmware, website and desktop app
    [01_printed_hood.3mf, 01_printed_hood.step, 01_printed_hood.stl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]
2026-10-05 Six-Tube Nixie Clock Rev C: alarm-clock case, build guide, KiCad, CAD, firmware, website and desktop app
    [01_alarm_case_shell.3mf, 01_alarm_case_shell.step, 01_alarm_case_shell.stl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]
2026-10-10 Six-Tube Nixie Clock Rev C: walnut and brass heirloom case, build guide, KiCad, CAD, firmware, website and desktop app
    [01_alarm_case_shell.3mf, 01_alarm_case_shell.step, 01_alarm_case_shell.stl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]
